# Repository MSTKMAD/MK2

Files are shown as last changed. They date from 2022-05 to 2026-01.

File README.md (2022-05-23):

# Proyecto de Contruccion del 2º modelo de la MACHETE (MK2)

Este reopsitorio es un Fork qe proviene del respositorio de bitbucket de la EDCPSU.
Las versiones HW de partida son la r15 para la tarjeta de la EDCPSU
Las versiones SW de partida son la 730 para el codigo de la DUAL y la version 731 de la EDCPSU o Main.

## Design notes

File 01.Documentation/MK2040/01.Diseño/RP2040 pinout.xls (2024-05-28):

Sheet: Pinout
 | ArduinoUNO |  |  |  |  |  |  |  |  |  | TPIC2810D MOSFET I2C Expander
 | PWM | Serial | Int | SPI | LED | I2C | Function | DIR | Description |  | Function | DIR | Description
0 |  | Rxi |  |  |  |  | RX | i | RS232 RX | D0 | LDO_S0 | o | Lower bit selection LDO voltage
1 |  | Txo |  |  |  |  | TX | o | RS232 TX | D1 | LDO_S1 | o | S11 bit selection LDO voltage
2 |  |  | INT 2 |  |  |  | PUSH | int | Pushbutton | D2 | LDO_S2 | o | S2 bit selection LDO voltage
3 | pwm |  | INT 3 |  |  |  | ROTPUSH | int | Rotary Pushbutton | D3 | LDO_S3 | o | S3 bit selection LDO voltage
4 |  |  |  |  |  |  | ROTA | i | Rotary A pin | D4 | LDO_S4 | o | S4 bit selection LDO voltage
5 | pwm |  |  |  |  |  | ROTB | i | Rotary B pin | D5 | LDO_S5 | o | S5 bit selection LDO voltage
6 | pwm |  |  |  |  |  | BUZZ | o | Buzzer | D6 | LDO_S6 | o | S6 bit selection LDO voltage
7 |  |  |  |  |  |  | /ERROR | i | Flag error (USB error detection) | D7 | LDO_S7 | o | S7 bit selection LDO voltage
8 |  |  |  |  |  |  | DSP_RST | io | Display Reset
9 | pwm |  |  |  |  |  | ONOFF | o | Output Switch (general op)
10 | pwm |  |  | SS |  |  | DISPLAY1 (SPI) | o | SS Display
11 | pwm |  |  | MOSI |  |  | DISPLAY2 (SPI) | o | MOSI Display
12 |  |  |  | MISO |  |  | DISPLAY3 (SPI) | i | MISO Display |  | TPIC2810D MOSFET I2C Expander
13 |  |  |  | SCK | led |  | DISPLAY4 (SPI) | o | SCK Display |  | Function | DIR | Description
A0 |  |  |  |  |  |  | ISEN | an | Output Current sensing | D0 | DCDC_S0 | o | Bit selection voltage DCDC
A1 |  |  |  |  |  |  | VOSEN | an | Voltage output sensing | D1 | DCDC_S1 | o | Bit selection voltage DCDC
A2 |  |  |  |  |  |  |  |  |  | D2 | DCDC_S2 | o | Bit selection voltage DCDC
A3 |  |  |  |  |  |  | /EN_VREG | o | Enables the NCP380 | D3 | LDO_YES | o | Path through LDO
A4 |  |  |  |  |  | SDA | SDA | o | I2C Bus | D4 | LDO_NOT | o | Bypass LDO
A5 |  |  |  |  |  | SCL | SCL | o | I2C Bus | D5 | 5VRAW_GO | o | Path thru 5V Raw input
A6 |  |  |  |  |  |  | VDCDCSEN | an | Voltage step-up sensing | D6 | USB_ILIM1 | o | Current Limit 1 for USB
A7 |  |  |  |  |  |  | 5VREGSEN | an | Voltage input sensing | D7 | USB_ILIM2 | o | Current Limit 2 for USB

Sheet: Pinout RP2040
 | ArduinoUNO
GPIO | PWM | Serial | Int | SPI | LED | I2C | Function | DIR | Description
0 | 0A | TxO | Int 0 |  |  |  | TX | o | RS232 TX
1 | 0B | RxI | Int 1 |  |  |  | RX | i | RS232 RX
2 | 1A |  | Int 2 |  |  |  | EN_DCDC
3 | 1B |  | Int 3 |  |  |  | PUSH_FILT
4 | 2A |  | Int 4 |  |  |  | RPUSH_FILT
5 | 2B |  | Int 5
6 | 3A |  | Int 6 |  |  | SDA | SDA | o | I2C Bus
7 | 3B |  | Int 7 |  |  | SCL | SCL | o | I2C Bus
8 | 4A |  | Int 8 |  |  |  | PEDAL_IP
9 | 4B |  | Int 9 |  |  |  | ROTB_FILT
10 | 5A |  | Int 10 |  |  |  | ROTA_FILT
11 | 5B |  | Int 11 |  |  |  | OVC_ALARM
12 | 6A |  | Int 12 |  |  |  | BUZZ
13 | 6B |  | Int 13 |  |  |  | SEL
14 | 7A |  | Int 14 |  |  |  | DSP_RESET
15 | 7B |  | Int 15 |  |  |  | SPARE2
16 | 0A |  | Int 16 | Rx |  |  | DISPLAY3 (SPI) | i | MISO Display
17 | 0B |  | Int 17 | CS |  |  | DISPLAY1 (SPI) | o | SS Display
18 | 1A |  | Int 18 | SCK |  |  | DISPLAY4 (SPI) | o | SCK Display
19 | 1B |  | Int 19 | TX |  |  | DISPLAY2 (SPI) | o | MOSI Display
20 | 2A |  | Int 20
21 | 2B |  | Int 21
22 | 3A |  | Int 22
23 | 3B |  | Int 23
24 | 4A |  | Int 24
25 | 4B |  | Int 25
26/A0 | 5A |  | Int 26 |  |  |  | ISEN | an | Output Current sensing
27/A1 | 5B |  | Int 27 |  |  |  | VOSEN | an | Voltage output sensing
28/A2 | 6A |  | Int 28 |  |  |  | VBUS_SENSE | an | Voltage step-up sensing
29/A3 | 6B |  | Int 29

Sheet: Boards Pinout
 | UF2 Bootloader | BOSSA compatible
 |  |  | Adafruit Feather RP2040 |  |  |  |  |  |  |  |  |  | SparkFun Pro Micro - RP2040
 |  |  |  |  |  |  |  | ORIGINAL | r20 | r21 | r22
 |  |  |  | Pin | Name | ADAFRUIT M0 SAMD21G18 | SPARKFUN SAMD21G18 | ARDUINO UNO EDCPSU | ARDUINO UNO EDCPSU | EDCPSU ARM Cortex | EDCPSU ARM Cortex | VOLTAGE
 |  |  |  | 3 | PA02 |  |  |  |  |  |  | 3V3
 |  |  |  | 4 | PA03
 |  |  |  | 9 | PA04
 |  |  |  | 10 | PA05
 |  |  |  | 11 | PA06
Price: | 0.36 € |  |  | 12 | PA07
DEBUG 10 pin connector (https://www.digikey.com/product-detail/en/3220-10-0100-00/1175-1627-ND/3883661) |  |  |  | 13 | PA08
 |  |  |  | 14 | PA09
 |  |  |  | 15 | PA10
 |  |  |  | 16 | PA11
 |  |  |  |  | PA12
 |  |  |  |  | PA13
 |  |  |  |  | PA14
 |  |  |  |  | PA15
 | 5 mm |  |  |  | PA16
12,65 mm |  |  |  |  | PA17
 |  |  |  |  | PA18
 |  |  |  |  | PA19
 |  |  |  |  | PA20
 |  |  |  |  | PA21
 |  |  |  |  | PA22
 |  |  |  |  | PA23
 |  |  |  |  | PA24
 |  |  |  |  | PA25
 |  |  |  |  | PA27
 |  |  |  |  | PA28
 |  |  |  |  | PA30
 |  |  |  |  | PA31
 |  |  |  | 47 | PB02
 |  |  |  | 48 | PB03
 |  |  |  | 7 | PB08
 |  |  |  | 8 | PB09
 |  |  |  |  | PB10
 |  |  |  |  | PB11
 |  |  |  |  | PB22
 |  |  |  |  | PB23

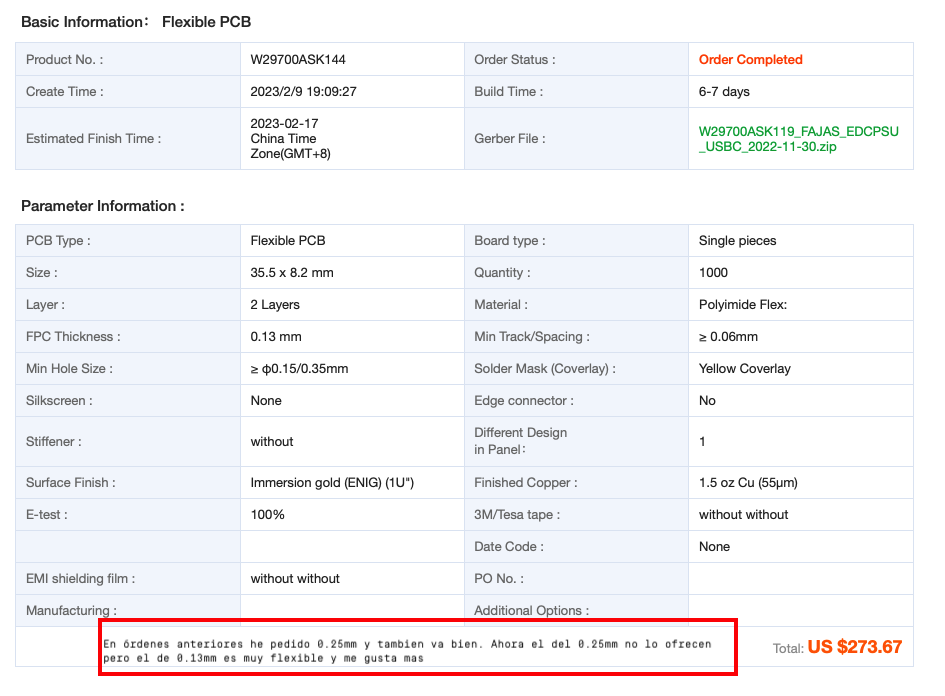
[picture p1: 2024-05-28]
02.Hardware/MK2 PCBs/05.FAJA USBC SINGLE/GERBER/Como pedir faja PCBWAY - 0.13mm.png

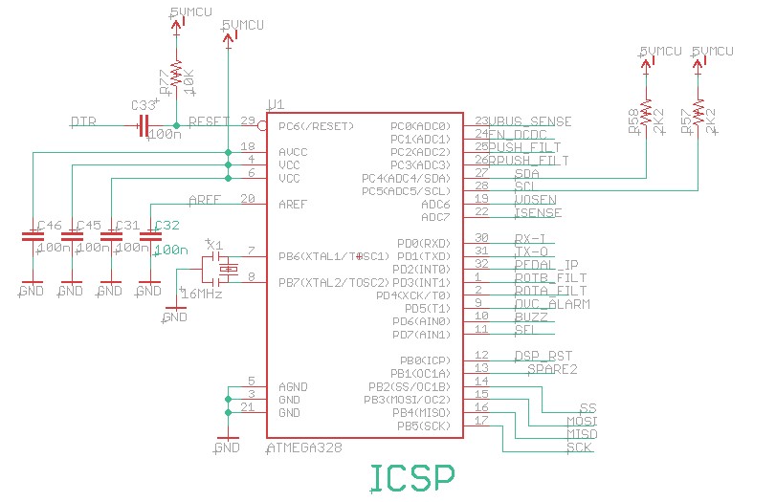
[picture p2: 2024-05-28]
01.Documentation/MK2040/01.Diseño/Atemega328P.jpg

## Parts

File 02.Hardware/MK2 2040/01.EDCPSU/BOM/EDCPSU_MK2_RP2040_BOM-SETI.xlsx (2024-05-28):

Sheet: EDCPSUMK2
 |  |  |  | BOM VERSION v | 5
 |  |  |  | Fecha | 2023-06-05
 |  |  |  | MK2-RP2040
Assembly? | Cambios | Pos | Qty | Parts | Value | Device | Package | Description | Details | COST (500pcs) | COST per Board (500 pcs) | DIGIKEY
P | NO | 2 | 1 | BZ1 | PKMCS0909E4000-R1 | PKMCS0909E4000-R1 | PKMCS0909 | PKMCS0909E4000-R1 |  | 0.48 € | 0.48 € | https://www.digikey.es/es/products/detail/murata-electronics/PKMCS0909E4000-R1/4878400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
P | NO | 3 | 3 | C17, C18, C21 | 4.7uF 50V X7R | CAP1210 | SMD1210 | Capacitor |  | 0.11 € | 0.32 € | https://www.digikey.es/en/products/detail/samsung-electro-mechanics/CL32B475KBUYNNE/3886950
NO | NO | 4 | 0 | C19, C65 | N.C. | CAP0805 | SMD0805 | Capacitor |  |  | 0.00 €
P | NO | 5 | 34 | C2, C4, C5, C6, C7, C8, C10, C12, C14, C16, C20, C22, C23, C24, C25, C27, C28, C29, C31, C32, C33, C34, C36, C44, C47, C48, C49, C50, C53, C55, C57, C58, C60, C66 | 100n 50v X7R/X5R | CAP0805 | SMD0805 | Capacitor |  |  | 0.00 €
P | NO | 6 | 4 | C26, C35, C43, C51 | 10uF 50V X5R/X7R | CAP1206 | SMD1206 | Capacitor |  | 0.07 € | 0.28 € | https://www.digikey.es/en/products/detail/samsung-electro-mechanics/CL31A106MBHNNNE/5961220
P | NO | 7 | 2 | C3, C62 | 22uF 10V X5R | CAP0805 | SMD0805 | Capacitor |  | 0.06 € | 0.11 € | https://www.digikey.es/en/products/detail/murata-electronics/GRM21BR61A226ME51L/5027595
P | NO | 8 | 1 | C30 | 33n | CAP0805 | SMD0805 | Capacitor |  |  | 0.00 €
P | NO | 9 | 1 | C37 | 10nF | CAP0805 | SMD0805 | Capacitor |  |  | 0.00 €
P | NO | 10 | 1 | C38 | 16pF | CAP0805 | SMD0805 | Capacitor |  |  | 0.00 €
P | NO | 11 | 4 | C39, C40, C41, C42 | 22uF 25V X5R | CAP1210 | SMD1210 | Capacitor |  | 0.12 € | 0.49 € | https://www.digikey.es/en/products/detail/samsung-electro-mechanics/CL32A226KPJNNNE/3889030
NO | NO | 12 | 0 | C52 | N.C | CAP0805 | SMD0805 | Capacitor |  |  | 0.00 €
P | NO | 13 | 2 | C59, C61 | 27p | CAP0805 | SMD0805 | Capacitor |  |  | 0.00 €
P | NO | 14 | 2 | C63, C64 | 4.7uF 50V X5R | CAP0805 | SMD0805 | Capacitor |  | 0.04 € | 0.09 € | https://www.digikey.es/en/products/detail/murata-electronics/GRT21BR61H475ME13L/5416817
P | NO | 15 | 8 | C9, C11, C13, C15, C45, C46, C54, C56 | 1uF 50V X7R | CAP0805 | SMD0805 | Capacitor |  |  | 0.00 €
P | valor | 16 | 1 | D1 | SMAJ24A | SMAJ24A | SMA-DO214 | ESD Suppressors / TVS Diodes 24volts 5uA 10.3 Amps UNI-Dir |  | 0.11 € | 0.11 € | https://www.digikey.es/en/products/detail/littelfuse-inc/SMAJ24A/762288
P | NO | 17 | 2 | D2, D7 | BAV199 | BAV199 | SOT23 | DIODE |  | 0.11 € | 0.23 € | https://www.digikey.es/es/products/detail/infineon-technologies/BAV199E6327HTSA1/506263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
P | NO | 18 | 1 | D4 | PESD5V0U2BT,215 | PESD5V0U2BT,215 | SOT23 | PESD5V0U2BT - Ultra low capacitance bidirectional double ESD protection diode |  | 0.18 € | 0.18 € | https://www.digikey.es/es/products/detail/nexperia-usa-inc/PESD5V0U2BT-215/1766938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
P | NO | 19 | 1 | D5 | 3SMAJ5923B-TP | 3SMAJ5923B-TP | SMA-DO214 | Zener Diodes 3W 8.2V |  | 0.12 € | 0.12 € | https://www.digikey.es/es/products/detail/micro-commercial-co/3SMAJ5923B-TP/1793169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
NO | NO | 20 | 0 | D6 | N.C | DSMC | DO-214AB |  |  |  | 0.00 €
P | Valor | 21 | 1 | D8 | SMAJ18A | SMAJ18A | SMA-DO214 | TVS 18V 400W Unidirectional |  | 0.13 € | 0.13 € | https://www.digikey.es/en/products/detail/littelfuse-inc/SMAJ18A/762282
P | NO | 22 | 1 | DZ1 | MMSZ5228B | MMSZ5228B | SOD123F | Diode Zener 3.9 5% 500mW 2Pin SOD123 Diodes Inc MMSZ5227B-7-F Zener Diode, 3.9V 5% 500 mW SMT 2-Pin SOD-123 |  | 0.09 € | 0.09 € | https://eu.mouser.com/ProductDetail/Diotec-Semiconductor/MMSZ5228B?qs=OlC7AqGiEDkIT4mCF6hrjg%3D%3D
P | NO | 25 | 1 | J1 | DX07S016JA1R1500 | DX07S016JA1R1500 | JAE_DX07S016JA1R1500 | USB-C (USB TYPE-C) USB 2.0 Receptacle Connector 24 (16+8 Dummy) Position Surface Mount, Right Angle; Through Hole |  | 1.08 € | 1.08 € | https://www.digikey.es/es/products/detail/jae-electronics/DX07S016JA1R1500/11585731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
P | NO | 26 | 1 | J6 | Display | OLED_LCD | OLED_LCD |  |  |  | 0.00 €
P | NO | 27 | 1 | JP1 | 20021521-00010T1LF | 20021521-00010T1LF | 20021521-00010T1LF | MINITEK 127 SHROUDED HDR |  | 0.64 € | 0.64 € | https://www.digikey.es/en/products/detail/amphenol-cs-fci/20021521-00010T1LF/2414951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
P | NO | 29 | 1 | L1 | NRS4018T4R7MDGJ | NRS4018T4R7MDGJ | NRS4018T100MDGJ | Inductor SMD wirewound 4.7uH |  | 0.12 € | 0.12 € | https://www.digikey.es/en/products/detail/taiyo-yuden/NRS4018T100MDGJ/2648964
P | NO | 30 | 1 | L2 | 4.7uH | L74437368047 | WE-LHMI |  |  | 0.72 € | 0.72 € | https://www.digikey.es/en/products/detail/pulse-electronics/PA4342-472NLT/5436333
P | NO | 31 | 5 | L3, L4, L5, L6, L7 | MMZ2012Y202BT000 | SMD0805 | SMD0805 | Ferrite bead |  | 0.02 € | 0.11 € | https://www.digikey.es/en/products/detail/tdk-corporation/MMZ2012Y202BT000/571868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
P | Valor | 32 | 1 | LED1 | LTL1NHSH6D | LTL1NHSH6D | LTL1NHSH6D | LED 3MM LITEON YELLOW 65mcd 60º |  | 0.03 € | 0.03 € | https://www.tme.eu/es/en/details/ltl1nhsh6d/tht-leds-round/liteon/
NO | sin montar | 33 | 0 | LS1 | SMT-0540-S-R | SMT-0540-S-R | SMT0540SR | Speakers & Transducers SMD TRANSDUCER 3VP-P 100MA |  |  | 0.00 €
P | NO | 34 | 1 | OP1 | LTV816S | LTV816S | SMD4 | OPTO COUPLER |  | 0.13 € | 0.13 € | https://www.digikey.es/es/products/detail/liteon/LTV-816S/385831?s=N4IgTCBcDaIIwDYAMBaOBmBcUFYUDkAREAXQF8g
P | NO | 35 | 1 | PTC1 | 2A NOM / 3.5A LIM | 0ZCC0150BF2C | SMD1812 | PTC RESTTBLE 1.50A 24V CHIP 1812 |  | 0.13 € | 0.13 € | https://www.digikey.es/es/products/detail/bel-fuse-inc/0ZCC0150BF2C/2165288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
P | NO | 36 | 4 | Q2, Q4, Q5, Q9 | 2N7002PW | MOSFET-NCHANNEL2N7002PW | SOT323 | N-MOSFET VGS=2.4V 500mA, VDS=60V |  | 0.09 € | 0.35 € | https://www.digikey.es/es/products/detail/nexperia-usa-inc/2N7002PW-115/2296328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
P | NO | 37 | 8 | R1,R32, R39, R40, R42, R49, R66 | 10K | RESISTOR0805 | SMD0805 | Generic Resistor Package |  |  | 0.00 €
P | NO | 38 | 1 | R10 | 22K | RESISTOR0805 | SMD0805 | Generic Resistor Package |  |  | 0.00 €
P | Valor | 39 | 1 | R12 | 0.025R / 1W | RR2512 | SMD2512 | 25mR Sensing resistor |  | 0.19 € | 0.19 € | https://www.digikey.es/en/products/detail/yageo/RL2512FK-070R025L/3885847
P | NO | 40 | 5 | R13, R23, R52, R53, R54 | 2K2 | RESISTOR0805 | SMD0805 | Generic Resistor Package |  |  | 0.00 €
P | NO | 41 | 7 | R14, R17, R21, R24, R28, R29, R65 | 33R | RESISTOR0805 | SMD0805 | Generic Resistor Package |  |  | 0.00 €
NO | NO | 42 | 7 | R16, R18, R30, R34, R45, R58, R60 | N.C | RESISTOR0805 | SMD0805 | Generic Resistor Package |  |  | 0.00 €
P | Cantidad | 43 | 7 | R2, R19, R20, R25, R27, R46, R59 | 1K | RESISTOR0805 | SMD0805 | Generic Resistor Package |  |  | 0.00 €
P | Cantidad | 44 | 7 | R22, R26, R31, R33, R61, R99, R57 | 330R | RESISTOR0805 | SMD0805 | Generic Resistor Package |  |  | 0.00 €
P | Cantidad | 45 | 2 | R3, R43 | 11K | RESISTOR0805 | SMD0805 | Generic Resistor Package |  |  | 0.00 €
P | Cantidad | 46 | 2 | R37, R41 | 150K | RESISTOR0805 | SMD0805 | Generic Resistor Package |  |  | 0.00 €
P | NO | 47 | 2 | R38, R63 | 27R | RESISTOR0805 | SMD0805 | Generic Resistor Package |  |  | 0.00 €
P | NO | 48 | 1 | R4 | 5K6 | RESISTOR0805 | SMD0805 | Generic Resistor Package |  |  | 0.00 €
NO | Eliminada | 49 | 0 | - | - | - | - | - |  |  | 0.00 €
P | NO | 50 | 1 | R36 | 27K | RESISTOR0805 | SMD0805 | Generic Resistor Package |  |  | 0.00 €
P | NO | 51 | 1 | R44 | 25K | RESISTOR0805 | SMD0805 | Generic Resistor Package |  |  | 0.00 €
P | NO | 52 | 2 | R47, R48 | 100R | RESISTOR0805 | SMD0805 | Generic Resistor Package |  |  | 0.00 €
P | NO | 53 | 1 | R5 | 2K8 | RESISTOR0805 | SMD0805 | Generic Resistor Package |  |  | 0.00 €
P | NO | 54 | 1 | R50 | 56K | RESISTOR0805 | SMD0805 | Generic Resistor Package |  |  | 0.00 €
P | NO | 55 | 1 | R51 | 390K | RESISTOR0805 | SMD0805 | Generic Resistor Package |  |  | 0.00 €
P | NO | 56 | 2 | R55, R56 | 5K1 | RESISTOR0805 | SMD0805 | Generic Resistor Package |  |  | 0.00 €
NO | Eliminada | 57 | 0 | - | - | - | - | - |  |  | 0.00 €
P | NO | 58 | 1 | R6 | 1K4 | RESISTOR0805 | SMD0805 | Generic Resistor Package |  |  | 0.00 €
P | NO | 59 | 1 | R62 | 100K | RESISTOR0805 | SMD0805 | Generic Resistor Package |  |  | 0.00 €
P | NO | 60 | 1 | R7 | 180K | RESISTOR0805 | SMD0805 | Generic Resistor Package |  |  | 0.00 €
P | NO | 61 | 1 | R8 | 91K | RESISTOR0805 | SMD0805 | Generic Resistor Package |  |  | 0.00 €
P | NO | 62 | 1 | R9 | 43K | RESISTOR0805 | SMD0805 | Generic Resistor Package |  |  | 0.00 €
P | NO | 63 | 1 | R35 | 130R | RESISTOR0805 | SMD0805 | Generic Resistor Package |  |  | 0.00 €
P | NO | 64 | 1 | RSENSE | 100mR | RESISTOR1206 | SMD1206 | Generic Resistor Package |  | 0.06 € | 0.06 € | https://www.digikey.es/en/products/detail/bourns-inc/CRL1206-FW-R100ELF/3593165
P | correccion | 65 | 1 | S1 | PEC12R-3220F-S0024 | ROTARTY_ENCODER | PEC12R-3220F-S0024 | ROTARY ENCODER MECHANICAL 24PPR |  | 0.91 € | 0.91 € | https://www.digikey.es/en/products/detail/bourns-inc/PEC12R-3220F-S0024/4699265
P | correccion | 66 | 1 | S2 | KSC931G LFS | KSC931G LFS | KSC931G LFS | Momentary switch |  | 0.54 € | 0.54 € | https://www.digikey.es/en/products/detail/c-k/KSC931G-LFS/3533878
P | NO | 67 | 1 | U1 | RP2040TR7 | RP2040TR7 | 56-QFN (7x7) | ARM MCU, RP2040 Series Microcontrollers, ARM Cortex-M0+, 32 bit, 133 MHz, 16 MB, 56 Pins |  | 0.65 € | 0.65 € | https://www.digikey.es/es/products/detail/raspberry-pi/SC0914-13/14306010?s=N4IgTCBcDaIE4AcwAYAsyQF0C%2BQ
P | NO | 68 | 1 | U10 | IP2721 | IP2721 | TSSOP16 | TYPEC/PD2.0/PD3.0 Physical Layer IC for USB TYPEC input Interfaces Working voltage: 3V~25V Package: TSSOP16 |  |  | 0.00 €
P | correccion | 69 | 1 | U11 | AP63203 | AP63203WU-7 | SOT23-6 | Switching Voltage Regulators DCDC Conv HV Buck TSOT26 T&R 3K |  | 0.43 € | 0.43 € | https://www.digikey.es/es/products/detail/diodes-incorporated/AP63203WU-7/9858426
P | NO | 70 | 1 | U12 | AP64501SP-13 | AP64501SP-13 | SOIC8 | Conv DC-DC 3.8V to 40V Synchronous Step Down Single-Out 0.8V to 39V 5A 8-Pin SO EP T/R |  | 1.25 € | 1.25 € | https://www.digikey.es/es/products/detail/diodes-incorporated/AP64501SP-13/10419715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
NO | sin montar | 71 | 0 | U2 | MCP4725A1T-E/CH | MCP4725A1T-E/CH | SOT23-6 | MCP4725 DAC |  |  | 0.00 € | https://www.digikey.es/es/products/detail/microchip-technology/MCP4725A1T-E-CH/1827895
P | NO | 72 | 2 | U3, U6 | SN74AC14PWR | 7414 | TSSOP14 | Hex schmitt trigger INVERTER |  | 0.27 € | 0.54 € | https://www.digikey.es/es/products/detail/texas-instruments/SN74AC14PWR/376031
P | Valor | 73 | 1 | U4 | MAX9938TEUK+TCT-ND | integrated Circuit | SOT23-5 | Current sense amplifier. GAIN=25 |  | 1.08 € | 1.08 € | https://www.digikey.es/es/products/detail/analog-devices-inc-maxim-integrated/MAX9938TEUK-T/1937784
P | NO | 74 | 1 | U5 | W25Q64JVSSIQ | W25Q64JVSSIQ | SOIC8-WIDE | 64M-bit Serial Flash Memory with uniform 4KB sectors and Dual/Quad SPI |  | 0.76 € | 0.76 € | https://www.digikey.es/es/products/detail/winbond-electronics/W25Q64JVSSIQ/5803992
P | NO | 75 | 1 | U7 | TPIC2810D | TPIC2810D | SOIC16 |  |  | 1.03 € | 1.03 € | https://www.digikey.es/es/products/detail/texas-instruments/TPIC2810D/509926
P | Valor | 76 | 1 | U8 | LM4040C30FTA | LM4040C30FTA | SOT23 | Diodes Inc LM4040C30FTA, Shunt Precision Voltage Reference 3V, 0.5%, 3-Pin SOT-23 |  | 0.28 € | 0.28 € | https://www.digikey.es/es/products/detail/diodes-incorporated/LM4040C30FTA/4249970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
P | NO | 77 | 1 | U9 | MAX9064EUK+T | MAX9064EUK+T | SOT23-6 |  |  | 0.86 € | 0.86 € | https://www.digikey.es/es/products/detail/analog-devices-inc-maxim-integrated/MAX9064EUK-T/1937852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
P | correccion | 78 | 1 | X1 | ABM3C-12.000MHZ-D4Y-T | ABM3C-12.000MHZ-D4Y-T | ABM3C-12.000MHZ-D4Y-T | Abracon 12MHz Crystal +/-30ppm 4-SMD, No Lead 5 x 3 x 1.3mm |  | 0.57 € | 0.57 € | https://www.digikey.es/es/products/detail/abracon-llc/ABM3C-12-000MHZ-D4Y-T/2639882
P | Nueva | 79 | 1 | R15 | 0R | RESISTOR0805 | SMD0805 | Generic Resistor Package |  |  | 0.00 €
NO | sin montar | 80 | 0 | D3 | N.C | BAV199 | SOT23 | DIODE |  |  | 0.00 €
P | Nueva | 81 | 1 | R11 | 15K | RESISTOR0805 | SMD0805 | Generic Resistor Package |  |  | 0.00 €
 |  |  |  |  |  |  |  |  |  | 13.47 € | 15.10 €

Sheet: Historico
HISTÓRICO
VERSIÓN | FECHA | AUTOR | CAMBIO
1 | 2023-04-04 | JRC | Creacion
2 | 2023-05-30 | JRC | Se añade el pos 79 con el part R15 Se añade la pos 80 con el part D3 con el valor N.C Se añade a la pos 44 el part 57 aumentando su Qty. Se cambia el value de la pos 76 a LM4040C30FTA Se cambia el valor de la pos 39 part R12 a 0,025mOhm Se aumenta la pos 46 con el part R41 Se aumenta la pos 45 con el part R43 Se añade la pos 81 cambia el valor de R11 a 15K
3 | 2023-05-31 | JRC | Se añade la columna de Cambios
4 | 2023-06-01 | DGB | Varios cambios y correcciones. Se añaden links de digikey, se corrigen denominaciones y se estandariza nombre de encapsulados
5 | 2023-06-05 | JRC | Se añaden la columna de precios por unidad en compras de 500 y el coste de la placa, multiplicando por el numero de unidades en la placa

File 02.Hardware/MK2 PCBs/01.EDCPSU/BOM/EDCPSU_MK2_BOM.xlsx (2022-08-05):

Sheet: EDCPSUMK2
 |  |  |  |  |  |  | BOM VERSION v1
 |  |  |  |  |  |  | 2022-05-23
 |  |  |  |  |  |  | EDCPSUMK2r1
Assembly? | Compra Seti | Pos | Qty | Parts | Value | Device | Package | Description | Details | DIGIKEY | COST (25pcs) | COST (100pcs) | COST per Board (25pcs)
P | P | 1 | 1 | R12 | 0.05R / 1W | Resistor | 2512 | Current sense resistor | 1W, 1%, 75ppm | 985-1555-1-ND | 0.27 | 0.18 | 0.27
P | P | 2 | 7 | R1, R32, R39, R49, R42, R66, R77 | 10K | Resistor | 805 | Resistor | 5% |  |  |  | 0
P | P | 3 | 1 | R11 | 15K | Resistor | 805 | Resistor | 5%
P | P | 4 | 1 | R3 | 11K | Resistor | 805 | Resistor | 5% |  |  |  | 0
P | P | 5 | 1 | R7 | 180K | Resistor | 805 | Resistor | 5% |  |  |  | 0
P | P | 6 | 6 | R2, R19, R20, R25,R27,R59 | 1K | Resistor | 805 | Resistor | 5% |  |  |  | 0
P | P | 7 | 1 | R6 | 1K4 | Resistor | 805 | Resistor | 5% |  |  |  | 0
P | P | 8 | 1 | R16 | 12K | Resistor | 805 | Resistor | 5% |  |  |  | 0
P | P | 9 | 2 | R37,R51 | 220K | Resistor | 805 | Resistor | 5% |  |  |  | 0
P | P | 10 | 1 | R10 | 22K | Resistor | 805 | Resistor | 5% |  |  |  | 0
P | P | 11 | 7 | R13, R23, R52, R53, R54, R57, R58 | 2K2 | Resistor | 805 | Resistor | 5% |  |  |  | 0
P | P | 12 | 1 | R5 | 2K8 | Resistor | 805 | Resistor | 5% |  |  |  | 0
P | P | 13 | 10 | R14, R17, R21, R24, R28, R29, R31, R65, R99, R45 | 33 | Resistor | 805 | Resistor | 5% |  |  |  | 0
P | P | 14 | 4 | R30,R33, R35, R61 | 330 | Resistor | 805 | Resistor | 5% |  |  |  | 0
P | P | 15 | 2 | R22, R26 | 330 | Resistor | 1206 | Resistor | 5% |  |  |  | 0
P | P | 16 | 1 | R44 | 33K | Resistor | 805 | Resistor | 5% |  |  |  | 0
P | P | 17 | 1 | R9 | 43K | Resistor | 805 | Resistor | 5% |  |  |  | 0
P | P | 18 | 1 | R4 | 5K6 | Resistor | 805 | Resistor | 5% |  |  |  | 0
P | P | 19 | 1 | R15 | 68K | Resistor | 805 | Resistor | 5% |  |  |  | 0
P | P | 20 | 1 | R36 | 75K | Resistor | 805 | Resistor | 5% |  |  |  | 0
P | P | 21 | 1 | R8 | 91K | Resistor | 805 | Resistor | 5% |  |  |  | 0
P | P | 22 | 29 | C1, C2, C7, C8, C10, C12, C14, C15, C20, C22, C23, C24, C25, C27, C28, C29, C31, C32, C33, C34, C36, C44, C45, C46, C47, C48, C49, C50, C53,C55,C57,C58 | 100n | Capacitor | 805 | Capacitor | 25V-50V, X7R or XR5 |  |  |  | 0
P | P | 23 | 5 | C4, C6, C26, C35, C43 | 10uF | Capacitor | 1206 | Capacitor | 25V-50V, X7R or XR5 |  |  |  | 0
P | P | 24 | 2 | C3, C30 | 15n | Capacitor | 805 | Capacitor | 25V-50V, X7R or XR5 |  |  |  | 0
P | P | 25 | 1 | C38 | 15p | Capacitor | 805 | Capacitor | 25V-50V, X7R or XR5 |  |  |  | 0
P | P | 26 | 4 | C11, C13, C16, C54 | 1uF | Capacitor | 805 | Capacitor | 25V-50V, X7R or XR5 |  |  |  | 0
P | P | 27 | 2 | C9,C56 | 1uF | Capacitor | 1206 | Capacitor | 25V-50V, X7R or XR5 |  |  |  | 0
P | P | 28 | 1 | C37 | 2.2n | Capacitor | 805 | Capacitor | 25V-50V, X7R or XR5 |  |  |  | 0
P | P | 29 | 4 | C39, C40, C41, C42 | 22uF | Capacitor | 1210 | Capacitor | 25V, X5R | 490-6540-1-ND | 0.31 |  | 1.24
P | P | 30 | 3 | C17, C18, C21 | 4.7uF | Capacitor | 1206 | Capacitor | 50V, 10% X7R | 1276-2789-1-ND | 0.18 | 0.14 | 0.54
P | P | 31 | 1 | L2 | 4.7uH | inductor | WE-LHMI |  | 4.7uH, 7A 0.0155 OHM | 732-3389-1-ND | 2.96 | 2.5 | 2.96
P | P | 32 | 1 | L1 | 6.8uH | Inductor | NR4018T100M | Inductor | 6.8uH, 1A, 0.132R | 587-2657-1-ND | 0.25 | 0.2 | 0.25
P | P | 33 | 5 | L3, L4, L5, L6, L7 | MMZ2012Y202BT000 | Inductor | 805 | Inductor | FERRITE CHIP 2000 OHM 400MA | 445-1561-1-ND | 0.08 | 0.045 | 0.4
P | P | 34 | 2 | U3, U6 | SN74AC14DBR | integrated Circuit | SSOP14 | Hex schmitt trigger INVERTER |  | 296-4299-1-ND | 0.38 | 0.28 | 0.76
P | P | 35 | 1 | U1 | ATMEGA328P-AU | integrated Circuit | 32-TQFP | MCU 8BIT 32KB FLASH 32TQFP |  | ATMEGA328P-AU-ND (http://www.digikey.es/product-detail/en/ATMEGA328P-AU/ATMEGA328P-AU-ND/1832260) | 2.8 (http://www.digikey.es/product-detail/en/ATMEGA328P-AU/ATMEGA328P-AU-ND/1832260) | 2.56 | 2.8
P | P | 36 | 1 | U5 | LM3480IM3X-12 | integrated Circuit | SOT23-3 | Small package linear regulator |  | LM3480IM3X-12/NOPBCT-ND | 0.76 | 0.66 | 0.76
P | P | 37 | 1 | U4 | MAX9938TEUK+TCT-ND | integrated Circuit | SOT23-5 | Current sense amplifier | X25 GAIN | MAX9938TEUK+TCT-ND | 1 | 0.93 | 1
P | P | 38 | 1 | U2 | BD9G101G | integrated Circuit | SSOP6 | BD9G101G - Simple Step-down |  | BD9G101G-CT-ND | 1.26 | 1.11 | 1.26
P | P | 39 | 1 | U7 | TPIC2810D | integrated Circuit | SO16 | I2C Led driver |  | 296-21426-5-ND | 1.4 | 1.13 | 1.4
P | P | 40 | 1 | U8 | TPS54531DDAR | Integrated Circuit | SOIC8 | BUCK converter |  | 296-40801-1-ND | 2.2 | 1.45 | 2.2
P | P | 41 | 1 | X1 | 16MHz | RESONATORSMD | 3-SMD, Non-Standard | CER RESONATOR 16.00MHZ SMD | 16MHz | 490-1198-1-ND | 0.39 | 0.31 | 0.39
P | P | 42 | 1 | S2 | TAC_SWITCH_KSC931G-SMD | pushbutton | TAC_SW_SMD_KSC931G | Momentary Switch |  | CKN10432CT-ND | 0.73 | 0.61 | 0.73
P | P | 43 | 1 | PTC1 | 1,5A HOLD / 3A LIM | PTC | 1812 | PTC RESTTBLE 1.50A 24V CHIP 1812 | 1,5A | 507-1505-1-ND | 0.24 | 0.22 | 0.24
P | P | 44 | 5 | Q2, Q3, Q4,Q5, Q9 | 2N7002PW | transistor | SOT323 | MOSFET N-CH 60V 0.31A, 1.6 Ohm. 2.4 VGS |  | 568-5987-1-ND | 0.24 | 0.18 | 1.2
P | P | 45 | 2 | D2,D7 | BAV199 | diode | SOT23 | DIODE |  | BAV199INCT-ND | 0.18 | 0.08 | 0.36
P | P | 46 | 1 | D6 | Diode | diode | DO-214AB | SCHOTTKY 40V 5A DO214AB |  | SK54L-TPMSCT-ND | 0.35 | 0.3 | 0.35
P | P | 47 | 1 | D1 | RB060M-60TR | diode | PMDU | DIODE SCHOTTKY 60V 2A PMDU |  | RB060M-60CT-ND | 0.3 | 0.19 | 0.3
P | P | 48 | 1 | D8 | B220A-13-F | diode | DO-214AC | DIODE SCHOTTKY 20V 2A SMA |  | B220A-FDICT-ND | 0.31 | 0.19 | 0.31
P | P | 49 | 1 | OP1 | LTV816S | Integrated Circuit | SMD4 Gullwing | OPTO COUPLER | CTRmin=50% @ 5mA, 5KViso | 160-1361-5-ND | 0.28 | 0.18 | 0.28
P | P | 50 | 1 | BZ1 | PKMCS0909E4000-R1 | speaker | SMD | Buzzer 12V |  | 490-9647-1-ND (https://www.digikey.es/product-detail/en/murata-electronics-north-america/PKMCS0909E4000-R1/490-9647-1-ND/4878401) | 1.08 | 0.968 | 1.08
P | NO | 52 | 1 | S1 | ROTARTY_ENCODER | ROTARTY_ENCODER | ROTARY_ENC_PLAIN | Simple no LED rotary encoder | Cambiado modelo con rosca | 652-PEC12R3220FS0024 (http://www.mouser.com/ProductDetail/bourns/pec12r-3220f-s0024/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) |  | 0.62
P | NO | 53 | 1 | LED1 | LED thru hole | LED3MM | LED3MM | LED Yellow
- | - | 54 |  | DELETED
- | - | 55 |  | DELETED
NO | NO | 56 | 2 | C5, C19 | N.C. | CAP0805 | 805 | Capacitor
NO | NO | 57 | 1 | R18 | N.C. | RESISTOR0805-RES | 805 | Resistor
- | - | 58 |  | DELETED
- | - | 59 |  | DELETED
- | - | 60 |  | DELETED
- | - | 61 |  | DELETED
P | NO | 62 | 1 | J6 | Display | OLED_LCD | OLED_LCD
- | - | 63 |  | DELETED
- | - | 64 |  | DELETED
- | - | 65 |  | DELETED
P | P | 66 | 1 | R41 | 330k | RESISTOR0805-RES | SMD0805 | Resistor | 5%
P | P | 67 | 1 | R43 | 27k | RESISTOR0805-RES | SMD0805 | Resistor | 5%
P | P | 68 | 1 | D4 | BZT52-B5V6J | DIODE | SOD-123 | Zener diode 5V6 590mW 2% 40ohm | 2% | Mouser (https://www.mouser.es/ProductDetail/Nexperia/BZT52-B5V6J) |  | 0.054
NO | NO | 69 | 0 | R46,R34 | N.C. | RESISTOR0805-RES | SMD0805 | Resistor | 5%
P | P | 70 | 2 | R47,R48 | 100R | RESISTOR0805-RES | SMD0805 | Resistor | 5%
P | P | 71 | 1 | R50 | 56K | RESISTOR0805-RES | SMD0805 | Resistor | 5%
P | P | 72 | 2 | R55,R56 | 5K1 | RESISTOR0805-RES | SMD0805 | Resistor | 5%
P | P | 73 | 1 | R62 | 100K | RESISTOR0805-RES | SMD0805 | Resistor | 5%
P | P | 74 | 1 | Rsense | 100mR | RESISTOR1206-RES | SMD1206 | Resistor | 1% | 273-KDV12DR100ETCT-ND (https://www.digikey.es/es/products/detail/ohmite/KDV12DR100ET/10476622)
P | P | 75 | 1 | J1 | DX07S016JA1R1500 | DX07S016JA1R1500 | JAE_DX07S016JA1R1500 | USB-C Connector |  | 670-DX07S016JA1R1500TR-ND (https://www.digikey.es/es/products/detail/jae-electronics/DX07S016JA1R1500/11585731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)
P | P | 76 | 1 | U9 | MAX9064EUK+T | 21-0057F_MXM | SOT23-5 | Comparator 0,2v |  | MAX9064EUK+TCT-ND (https://www.digikey.es/es/products/detail/analog-devices-inc-maxim-integrated/MAX9064EUK-T/1937852)
P | NO | 77 | 1 | U10 | IP2721 | SOP65P640X120-16N | TSSOP16

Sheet: Historico
HISTÓRICO
VERSIÓN | FECHA | AUTOR | CAMBIO
0 | 2016-10-17 | D. Garrido | Creación
1 | 2016-10-27 | D. Garrido | Se añade columna de Posicion. Pos30, se corrige encapsulado de condensadores de SMD1210 a 1206 Pos40 , se corrige denominacion de integrado (antes:74HC14). Pos42 , se corrige denominación de integrado (antes: LM3480IM4) Se añade Pos64,65 (sin completar aún)
2 | 2020-09-06 | D. Garrido | Se añade posiciones 66, 67 y 68. Se añade Q4 en pos44 and R45 in pos13
3 | 2020-10-09 | D. Garrido | Pos 52. Nuevo rotary con rosca. Referencia de Mouser
Cambio de Modelo a MK2 |  |  | Esta BOM se crea a partir de la original EDCPSU v3
1 | 2022-05-22 | J.Rodriguez | Se cambia el valor de R30 de 33 a 330 se elimina de la Pos13 y se añade a la Pos14. Se cambia el valor de R27 de 330 a 1k, se elimina de la Pos14 y se añade a la Pos6 Se añade R49 en Pos2. Se añade R51 a Pos 9. Se añade R59 a Pos 6. Se añade R34 a Pos 69. Se elimina C51 de Pos22. Se elimina C52 de Pos23. Se añade Q5 a la Pos44 Se elimina D3 de Pos45. Se elimina D5 de Pos46. Se añade C55 , C57 y C58 a Pos 22. Se añade C56 a Pos 27. Se añade D7 a Pos 45. Se añade Pos70, Pos71, Pos72, Pos73, Pos74, Pos75, Pos76 y Pos77. Se elimina Pos 54,55,58,59,61,63,64,65 (No se montaban)

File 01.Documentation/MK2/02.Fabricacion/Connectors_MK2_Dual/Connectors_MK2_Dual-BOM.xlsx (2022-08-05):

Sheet: BOM
 |  |  |  |  |  |  | BOM VERSION v1
 |  |  |  |  |  |  | 2022-05-27
 |  |  |  |  |  |  | CONNECTORS_MK2_DUAL_v1
Assembly? | Compra Seti | Pos | Qty | Parts | Value/Reference | Device | Package | Description | Details | DIGIKEY | COST (1000pcs) | Substitute
P | P | 1 | 1 | R3 | 10k | Resistor | SMD0603 | Resistor | 5%
P | P | 2 | 2 | R8, R9 | 220R | Resistor | SMD0603 | Resistor | 5%
P | P | 3 | 1 | R4 | 330R | Resistor | SMD0604 | Resistor | 5%
P | P | 4 | 1 | R7 | 3k3 | Resistor | SMD0605 | Resistor | 5%
P | P | 5 | 2 | R5, R6 | 47k | Resistor | SMD0606 | Resistor | 5%
P | P | 6 | 5 | Q1, Q2, Q3, Q4, Q5 | 2N7002PW | transistor | SOT323 | N-channel MOSFETs |  | 2N7002W-FDICT-ND (https://www.digikey.es/es/products/detail/diodes-incorporated/2N7002W-7-F/814962)
P | P | 7 | 2 | Q6, Q7 | SI4425DY | transistor | SOIC8 | Trans MOSFET P-CH 30V 29A 8-Pin SOIC N T/R |  | 2156-SI4425DY-ND (https://www.digikey.es/es/products/detail/rochester-electronics-llc/SI4425DY/12129450) |  | SI4459ADY-T1-GE3 AOSP21313C
P | P | 8 | 3 | MACHINE1, MACHINE2, PEDAL | ACJS-MHOM | Connector | CONN_MHDR_AMP | Audio connector 6.35mm stereo |  | 889-1817-ND (https://www.digikey.es/es/products/detail/amphenol-sine-systems-corp/ACJS-MHDR/7105422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)
P | P | 9 | 2 | LED1, LED2 | 5988380117F | Led | LED_APA3010SRCPRV-GX_KNB | SMD Led Green 90º position |  | 350-3034-2-ND (https://www.digikey.es/es/products/detail/dialight/5988380117F/2672539)
P | NO | 10 | 1 | FLX2 | FLEX8 | Cabling |  | Polyester flexible PCB. 2 Layers | poliester

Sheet: Historico
HISTÓRICO
VERSIÓN | FECHA | AUTOR | CAMBIO
0 | 27 mayo 2022 | J.Rodriguez | Creación

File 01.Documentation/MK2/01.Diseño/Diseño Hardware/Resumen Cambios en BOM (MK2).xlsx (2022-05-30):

CAMBIOS EN BOM -- MK2
Mayo 2022
 |  |  |  | Añadir unidades en BOM
 |  |  |  | Componentes Nuevo. Comprar
 |  |  |  | No comprar ó disminuir cantidad en BOM
EDCPSUMK2r1
Posicion | Tipo | Value | Cambio | DigikeyCode | Precio
Pos2 | Resistor | 10k | 1 | -
Pos6 | Resistor | 1k | 2 | -
Pos9 | Resistor | 220k | 1 | -
Pos13 | Resistor | 33R | -1 | -
Pos14 | Resistor | 330R | 2 | -
Pos22 | Capacitor | 100nF | -1 | -
Pos23 | Capacitor | 10uF | -1 | -
Pos27 | Capacitor | 1uF | 1 | -
Pos44 | Semiconductor | 2N7002PW | 1 | 2N7002W-7-F (https://www.digikey.es/en/products/detail/diodes-incorporated/2N7002W-7-F/814962)
Pos46 | Semiconductor | Schottky 60v 2A | -1 | SK54L-TPMSCT-ND (https://www.digikey.es/en/products/detail/micro-commercial-co/SK54L-TP/1990356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)
Pos70 | Resistor | 100R | 2 | -
Pos71 | Resistor | 56k | 1 | -
Pos72 | Resistor | 5k1 | 2 | -
Pos73 | Resistor | 100k | 1 | -
Pos74 | Resistor | 100mR | 1 | 273-KDV12DR100ETTR-ND (https://www.digikey.es/en/products/detail/ohmite/KDV12DR100ET/10476622) | 0.049
Pos75 | Connector | DX07S016JA1R1500 | 1 | 670-DX07S016JA1R1500TR-ND (https://www.digikey.es/en/products/detail/jae-electronics/DX07S016JA1R1500/11585731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) | 1.04
Pos76 | Semiconductor | MAX9064EUK+T | 1 | MAX9064EUK+TTR-ND (https://www.digikey.es/en/products/detail/analog-devices-inc-maxim-integrated/MAX9064EUK-T/1937852) | 0.59
Pos77 | Semiconductor | IP2721 | 1 | YA COMPRADO! | 0.65
Connectors_MK2-Dual-r1
Posicion | Tipo | Value | Cambio | DigikeyCode | Precio
Pos1 | Resistor | 10k | 1 | -
Pos2 | Resistor | 220R | 2 | -
Pos3 | Resistor | 330R | 1 | -
Pos4 | Resistor | 3k3 | 1 | -
Pos5 | Resistor | 47k | 2 | -
Pos6 | Semiconductor | 2N7002 | 5 | 2N7002W-7-F (https://www.digikey.es/en/products/detail/diodes-incorporated/2N7002W-7-F/814962) | 0.08
Pos7 | Semiconductor | SI4425DY | 2 | 2156-SI4425DY-ND (https://www.digikey.es/es/products/detail/rochester-electronics-llc/SI4425DY/12129450) | 0.7
Pos8 | Connector | ACJS-MHDR | 1 | 889-1817-ND (https://www.digikey.es/en/products/detail/amphenol-sine-systems-corp/ACJS-MHDR/7105422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)
Pos9 | Semiconductor | APA3010SRCPRV-GX | 2 | 754-1577-2-ND (https://www.digikey.es/en/products/detail/kingbright/APA3010SRCPRV-GX/2757938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) | 0.088

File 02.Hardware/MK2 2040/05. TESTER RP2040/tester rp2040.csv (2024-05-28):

Qty | Value | Device | Package | Parts | Description
7 |  | CONN_01 | 1X01 | J3, J4, J5, J6, J7, J8, J9 | Single connection point. Often used as Generic Header-pin footprint for 0.1 inch spaced/style header connections
1 |  | LED3MM | LED3MM | LED1 | LEDs
1 |  | RPI_PICO_IG-TH | RPI_PICO_TH | X1
4 | 100R | RESISTOR0805 | 0805 | R8, R15, R28, R30 | Generic Resistor Package
2 | 100k | RESISTOR0402 | 0402 | R2, R16 | Generic Resistor Package
3 | 100n 50v X7R/X5R | CAP0805 | 0805 | C9, C10, C11 | Capacitor
1 | 10k | RESISTOR0805 | 0805 | R66 | Generic Resistor Package
1 | 130R | RESISTOR0805 | 0805 | R35 | Generic Resistor Package
1 | 250mA/100V | DIODE-BAS16J | SOD-323 | D1 | Diode
3 | 2N7002PW | MOSFET-NCHANNEL2N7002PW | SOT323 | Q2, Q3, Q6 | Common NMOSFET Parts
3 | 2k2 | RESISTOR0805 | 0805 | R25, R26, R27 | Generic Resistor Package
1 | 302-S201 | 302-S201 | SHDR20W66P254_2X10_3300X905X90 | J1 | CONN HEADER VERT 20POS GOLD
5 | 33 | RESISTOR0805 | 0805 | R20, R21, R22, R24, R29 | Generic Resistor Package
1 | 330R | RESISTOR0805 | 0805 | R31 | Generic Resistor Package
4 | 47 | RESISTOR0805 | 0805 | R3, R9, R11, R13 | Generic Resistor Package
1 | 47K | RESISTOR0805 | 0805 | R6 | Generic Resistor Package
2 | 47k | RESISTOR0402 | 0402 | R1, R5 | Generic Resistor Package
5 | 51k | RESISTOR0805 | 0805 | R4, R7, R10, R12, R14 | Generic Resistor Package
1 | BAV199 | BAV199 | SOT23 | D2 | DIODE
1 | Display | OLED_LCD | OLED_LCD | DISPLAY
1 | MAX4634EUB+T | MAX4634EUB+T | SOP50P490X110-10N | IC1 | Multiplexer Switch ICs Fast, Low-Voltage, 4 Ohm, 4-Channel CMOS Analog Multiplexer
1 | MMSZ5227B-7-F | MMSZ5227B-7-F | SOD3716X135N | Z1 | Diode Zener 3.6V 5% 500mW 2Pin SOD123 Diodes Inc MMSZ5227B-7-F Zener Diode, 3.6V 5% 500 mW SMT 2-Pin SOD-123
3 | MOMENTARY-SWITCH-SPST-SMD-5.2MM | MOMENTARY-SWITCH-SPST-SMD-5.2MM | TACTILE_SWITCH_SMD_5.2MM | S1, S2, S3 | Momentary Switch (Pushbutton) - SPST
4 | PJA3416AE_R1_00001 | PJA3416AE_R1_00001 | SOT23_PJA3416_PNJ | Q1, Q5, Q8, Q9
2 | RQ3G110ATTB | RQ3G110ATTB | RQ3G110ATTB | Q4, Q7 | ROHM - RQ3G110ATTB - Power MOSFET, P Channel, 40 V, 35 A, 0.0098 ohm, RDS 12.4m, PD 20W, HSMT8, Surface Mount

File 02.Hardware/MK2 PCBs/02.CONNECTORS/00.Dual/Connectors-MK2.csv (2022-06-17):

Qty | Value | Device | Package | Parts | Description
1 | 10k | RESISTOR0603 | 0603 | R3 | Generic Resistor Package
2 | 220R | RESISTOR0603 | 0603 | R8, R9 | Generic Resistor Package
5 | 2N7002PW | MOSFET-NCH-2N7002PW | SOT323 | Q1, Q2, Q3, Q4, Q5 | N-channel MOSFETs
1 | 330 | RESISTOR0603 | 0603 | R4 | Generic Resistor Package
1 | 3k3 | RESISTOR0603 | 0603 | R7 | Generic Resistor Package
2 | 47k | RESISTOR0603 | 0603 | R5, R6 | Generic Resistor Package
3 | ACJS-MHDR | ACJS-MHDR | CONN_MHDR_AMP | MACHINE1, MACHINE2, PEDAL
2 | APA3010SRCPRV-GX | APA3010SRCPRV-GX | LED_APA3010SRCPRV-GX_KNB | LED1, LED2
1 | FLEX8 | FLEX8 | FLEX8 | K1 | WR-FPC 1mm SMT Horiz. Bot. Contact Hinge type WR-FPC 1mm 08 pins Hinge type SMT Horizontal Bottom Contact
2 | SI4459ADY-T1-GE3 | SI4459ADY-T1-GE3 | SOIC127P600X175-8N | Q6, Q7 | Trans MOSFET P-CH 30V 29A 8-Pin SOIC N T/R

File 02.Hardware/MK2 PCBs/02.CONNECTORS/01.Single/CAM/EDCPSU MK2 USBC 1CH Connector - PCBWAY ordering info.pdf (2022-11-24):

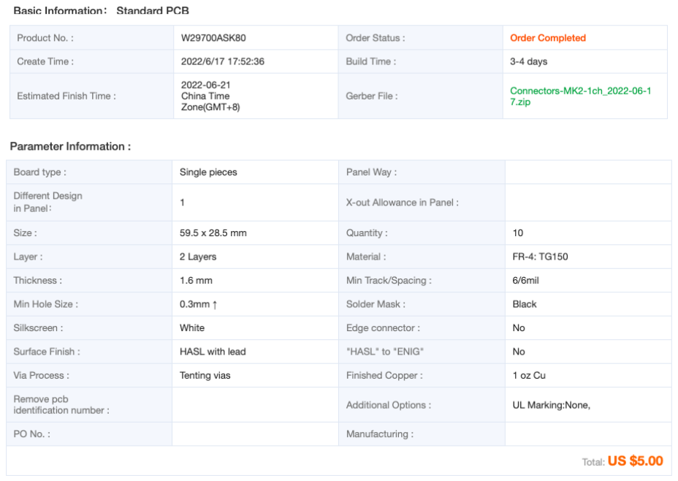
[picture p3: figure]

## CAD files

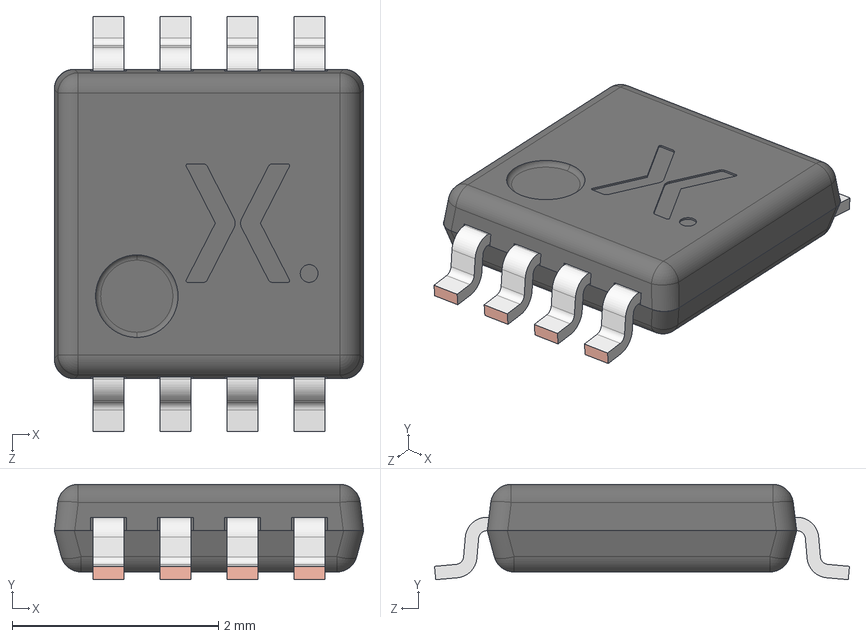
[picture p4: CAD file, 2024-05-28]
01.Documentation/MK2040/01.Diseño/Librerias EAGLE/LIB_74LVC1G74DP,125/74LVC1G74DP,125/3D/74LVC1G74DP,125.stp
3.00 x 0.925 x 4.02 mm
SOT505-2 Lower mold body
SOT505 Lead x 8
SOT505-2 Upper mold body

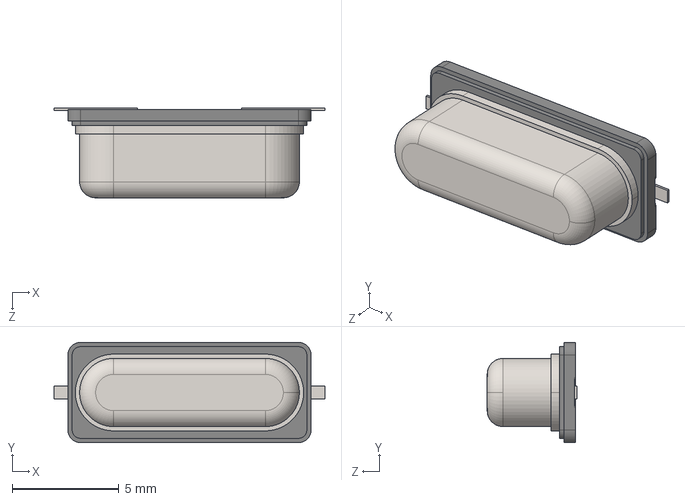
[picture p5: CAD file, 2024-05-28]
01.Documentation/MK2040/01.Diseño/Librerias EAGLE/LIB_ABLS-12.000MHZ-B4-T/ABLS-12.000MHZ-B4-T/3D/ABLS-12.000MHZ-B4-T.stp
12.7 x 4.70 x 4.20 mm

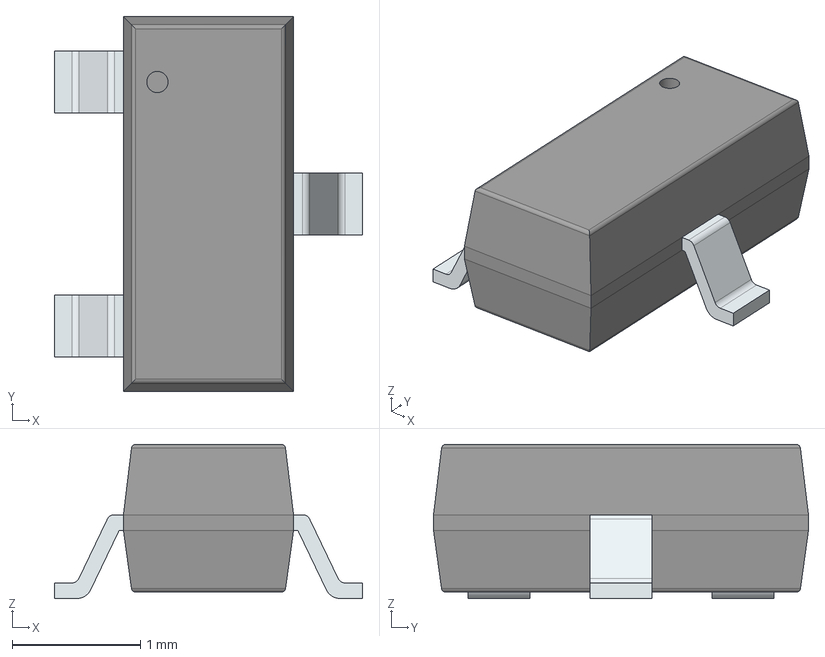
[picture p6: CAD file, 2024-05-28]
01.Documentation/MK2040/01.Diseño/Librerias EAGLE/LIB_MMBD1503A/MMBD1503A/3D/MMBD1503A.stp
2.40 x 2.92 x 1.20 mm
PinsArrayL
FilletPinR

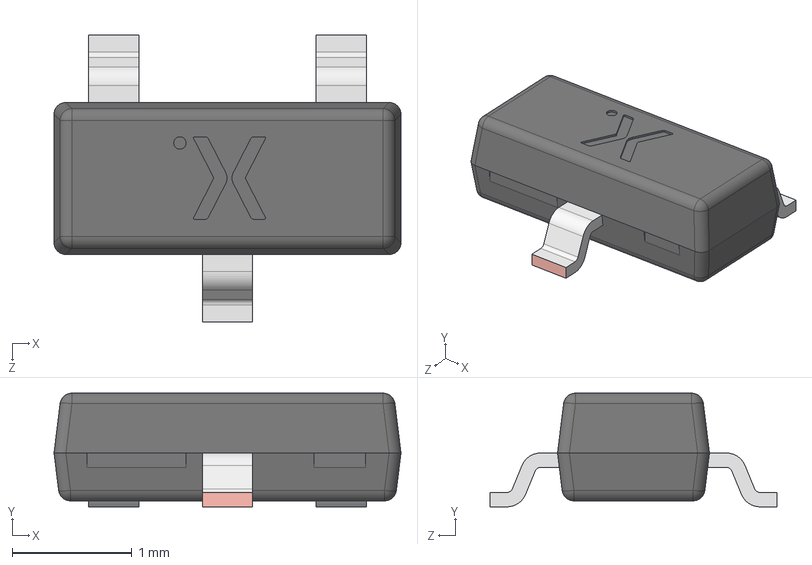
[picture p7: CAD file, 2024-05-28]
01.Documentation/MK2040/01.Diseño/Librerias EAGLE/LIB_PESD5V0U2BT,215/PESD5V0U2BT,215/3D/PESD5V0U2BT,215.stp
2.90 x 0.95 x 2.40 mm
SOT23 lower body
SOT23 Lead x 3
SOT23 Upper body

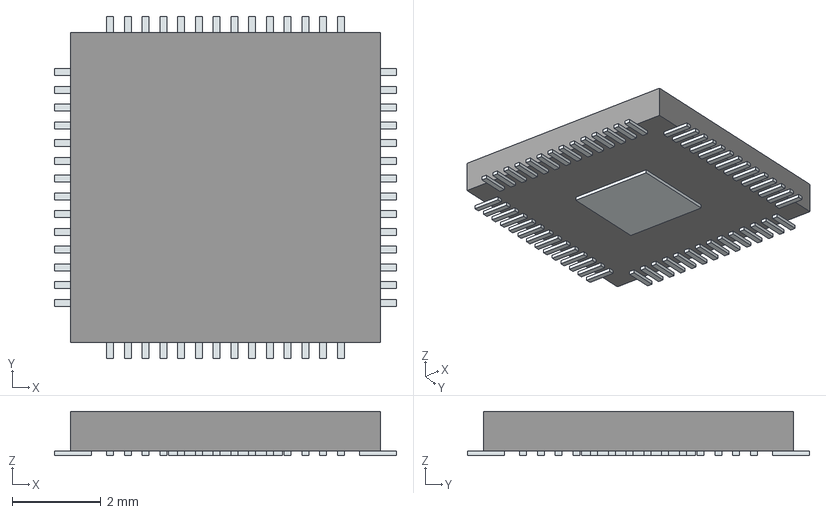
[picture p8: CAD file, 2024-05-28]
01.Documentation/MK2040/01.Diseño/Librerias EAGLE/LIB_RP2040TR7/RP2040TR7/3D/RP2040TR7.stp
7.71 x 7.71 x 1.00 mm
Pins

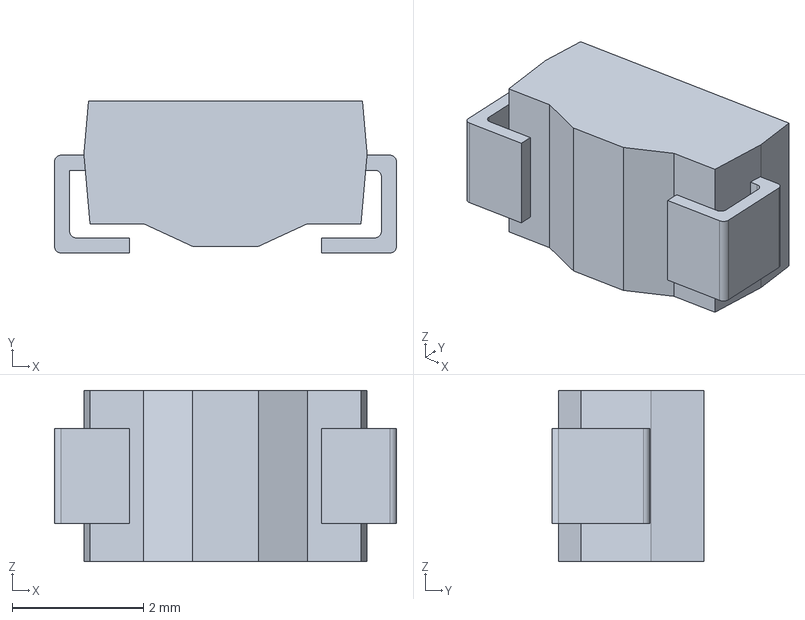
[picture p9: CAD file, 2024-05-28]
01.Documentation/MK2040/01.Diseño/Librerias EAGLE/LIB_SMAJ24CA/SMAJ24CA/3D/SMAJ24CA.stp
5.21 x 2.31 x 2.60 mm

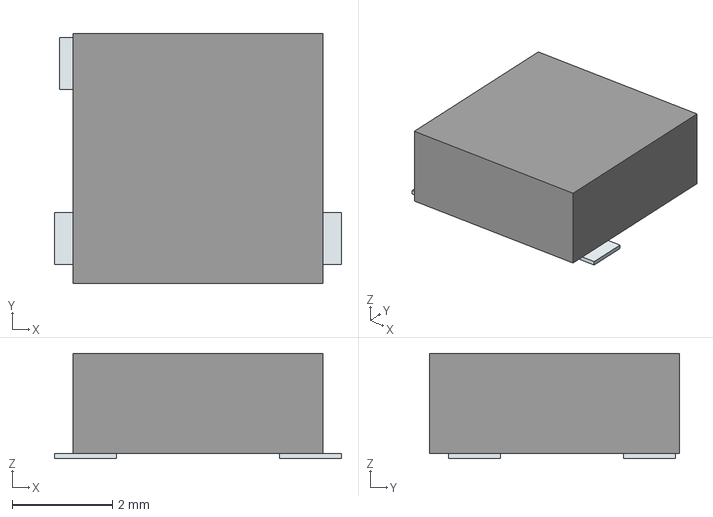
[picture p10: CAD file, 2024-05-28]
01.Documentation/MK2040/01.Diseño/Librerias EAGLE/LIB_SMT-0540-S-R/SMT-0540-S-R/3D/SMT-0540-S-R.stp
5.74 x 5.00 x 2.10 mm
Pins

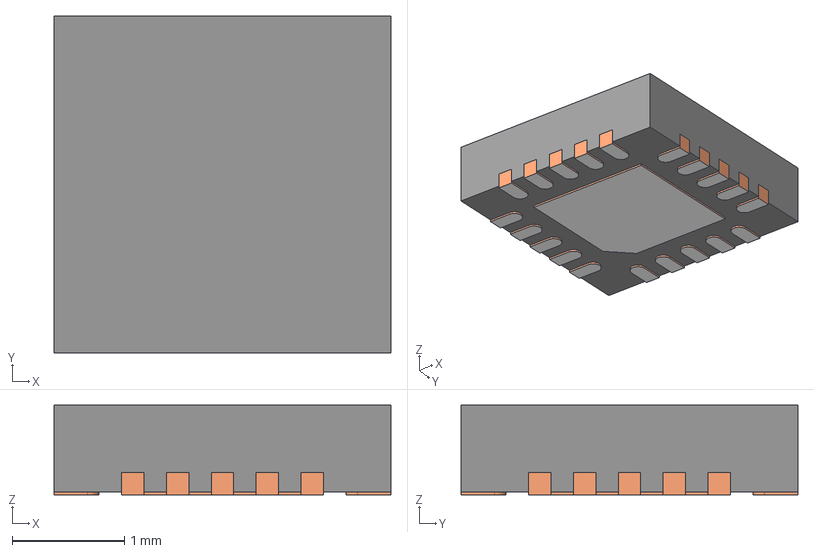
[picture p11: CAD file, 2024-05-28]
01.Documentation/MK2040/01.Diseño/Librerias EAGLE/LIB_TPD8S300RUKR/TPD8S300RUKR/3D/TPD8S300RUKR.stp
3.00 x 3.00 x 0.8 mm
BODY-QFN
FRAME-RUK0020B
PIN1-ID

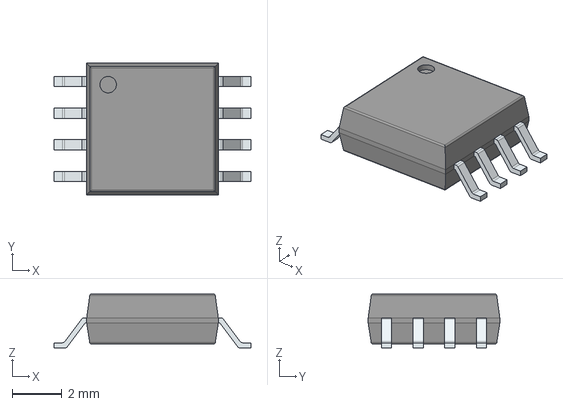
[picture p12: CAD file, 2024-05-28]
01.Documentation/MK2040/01.Diseño/Librerias EAGLE/LIB_W25Q64JVSSIQ/W25Q64JVSSIQ/3D/W25Q64JVSSIQ.stp
7.90 x 5.28 x 2.16 mm
PinsArrayLR

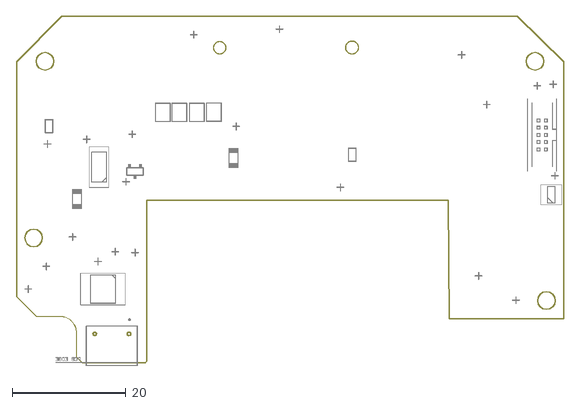
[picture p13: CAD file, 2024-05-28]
02.Hardware/MK2 2040/01.EDCPSU/EDCPSUMK2-RP2040.dxf
96.1 x 61.4

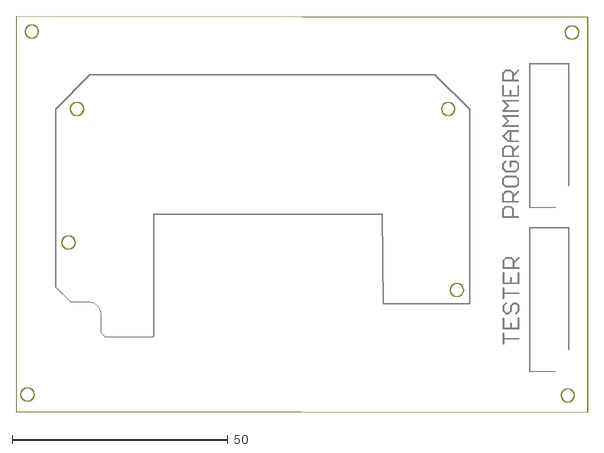
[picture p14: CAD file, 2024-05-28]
02.Hardware/MK2 2040/02.POGO-TEST/POGOTEST-MK2RP2040.dxf
132.6 x 92.0

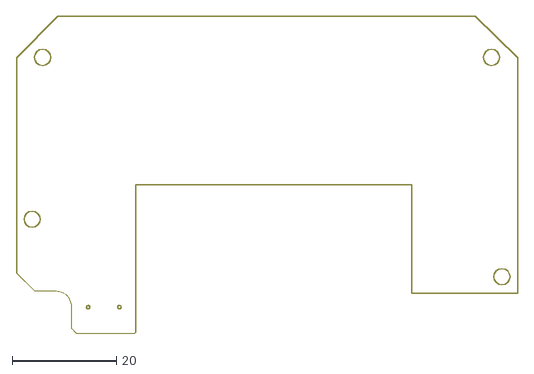
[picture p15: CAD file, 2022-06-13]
02.Hardware/MK2 PCBs/01.EDCPSU/EDCPSUMK2.dxf
96.1 x 60.9

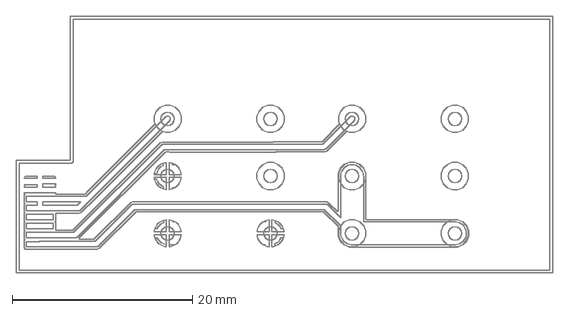
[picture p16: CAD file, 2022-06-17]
02.Hardware/MK2 PCBs/02.CONNECTORS/01.Single/Connectors-MK2-1ch.dxf
59.5 x 28.5 mm

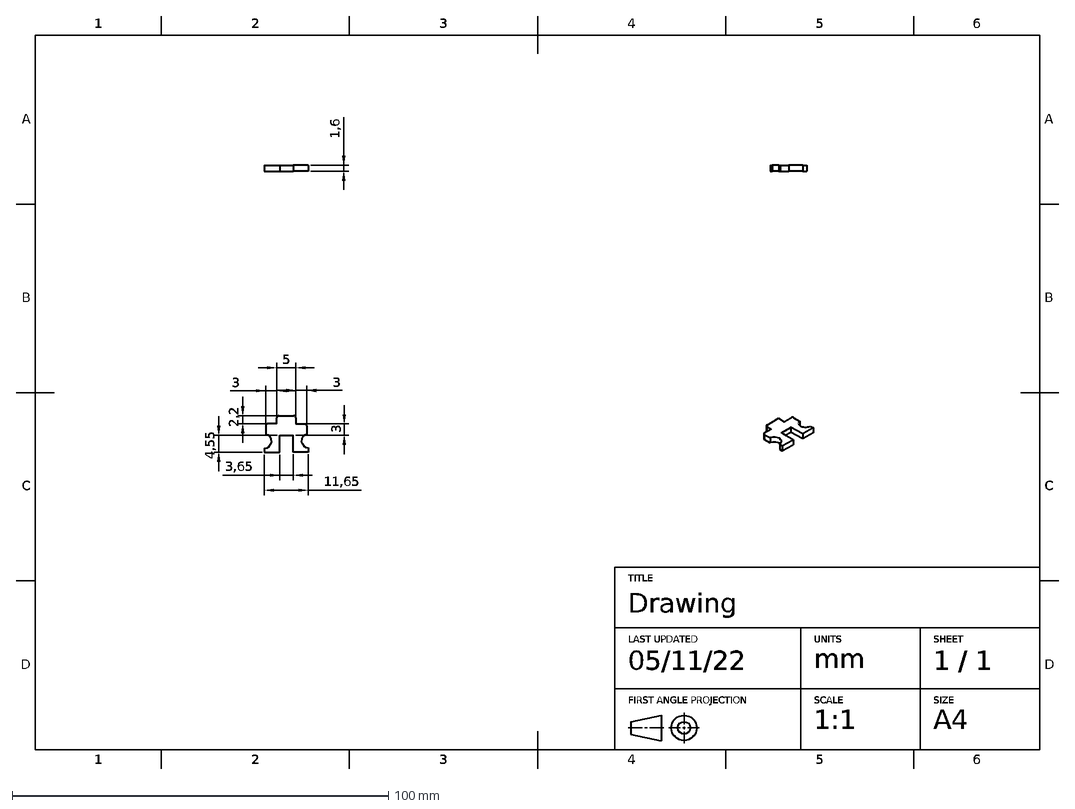
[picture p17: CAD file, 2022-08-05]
02.Hardware/MK2 PCBs/03.TESTS/Lentilla/Drawing 2.dxf
11,65
3
5
3,65
4,55
2,2
1,6
1
2
4
6
D
C
B
A
TITLE
Drawing
LAST UPDATED
05/11/22
UNITS
mm
SHEET
1 / 1
FIRST ANGLE PROJECTION
SCALE
1:1
SIZE
A4

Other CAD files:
02.Hardware/MK2 PCBs/03.TESTS/PRUEBA MECANICA-EDCPSUr16D/MECH_EDCPSUr16D_USBC/EDCPSU_M2 v1.dxf
02.Hardware/MK2 PCBs/03.TESTS/USBC-OVC_LIMIT/CAMOutputs/DrawingFiles/USBC-OVC_LIMIT.dxf
02.Hardware/MK2 PCBs/04.FAJA USBC/FAJA_LARGA_USBC.dxf
01.Documentation/MK2040/01.Diseño/Librerias EAGLE/LIB_74LVC1G74DP,125/74LVC1G74DP,125/Allegro/sop65p400x110-8n.psm
01.Documentation/MK2040/01.Diseño/Librerias EAGLE/LIB_74LVC1G74DP,125/74LVC1G74DP,125/DEHDL/74lvc1g74dp_125/chips/chips.prt
01.Documentation/MK2040/01.Diseño/Librerias EAGLE/LIB_ABLS-12.000MHZ-B4-T/ABLS-12.000MHZ-B4-T/Allegro/abls.psm
01.Documentation/MK2040/01.Diseño/Librerias EAGLE/LIB_ABLS-12.000MHZ-B4-T/ABLS-12.000MHZ-B4-T/DEHDL/abls_12.000mhz_b4_t/chips/chips.prt
01.Documentation/MK2040/01.Diseño/Librerias EAGLE/LIB_AP63201WU-7/AP63201WU-7/3D/AP63201WU-7.stp
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

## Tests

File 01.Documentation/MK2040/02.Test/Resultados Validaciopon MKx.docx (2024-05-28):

# Resultados Validaciopon MKx-RP2040

# 1 alimentación 3v3

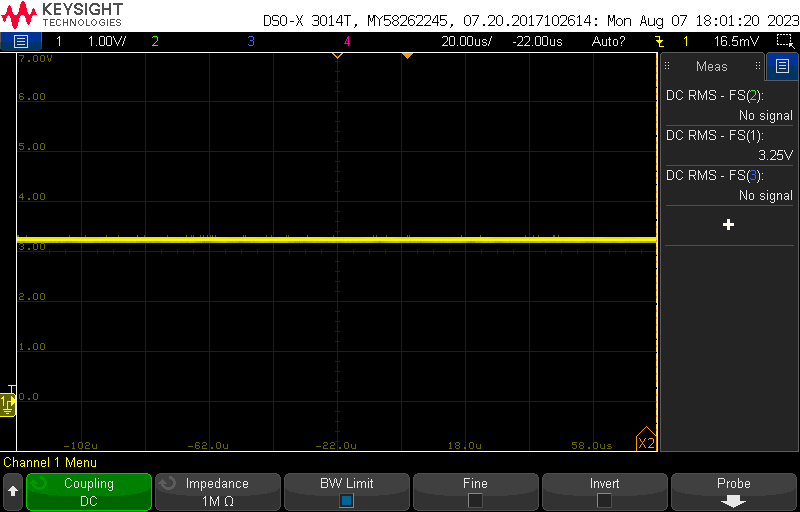
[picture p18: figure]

## 1.1 vacío

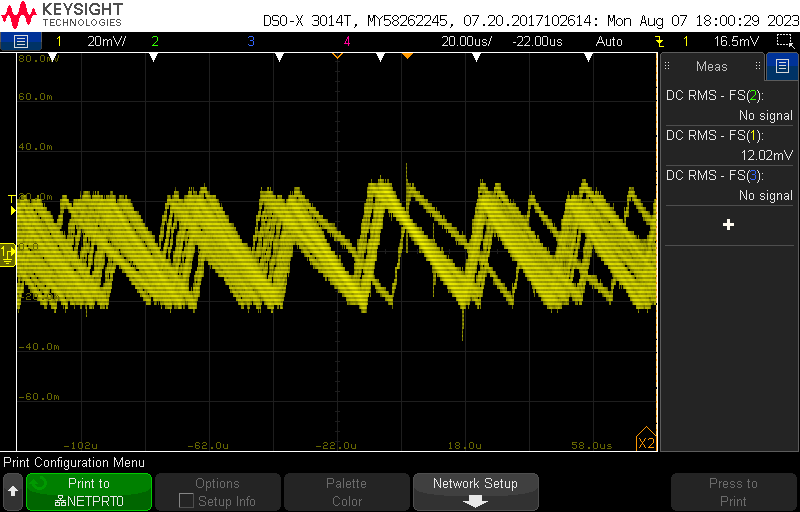
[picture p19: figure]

20mV de rizado

## 1.2 Resistencia de 33 Ohm a la salida

Sin cambios apreciables ni en vlaor ni en rizado

## 1.3 Arranque del sistema

4,5 ms en vacio. Sin cambios en valor fina con carga.

# 2 Guardado en EEPROM

Para comprobar la eeprom se enciende se fija un valor disitinto.

Se espera a que salga el indicador REC que marcaria el guardado en EEPROM.

Se desconecta la alimentacion

Al conectarla de nuevo se observa que efectivamente el valor se ha guardado.

En MK2, se repite el proceso para el NITRO y para el Chanel 2.

En MK1, se repite para las 4 memorias.

En todos los casos se recibe un valor positivo.

# 3 Rotary + Pulsador

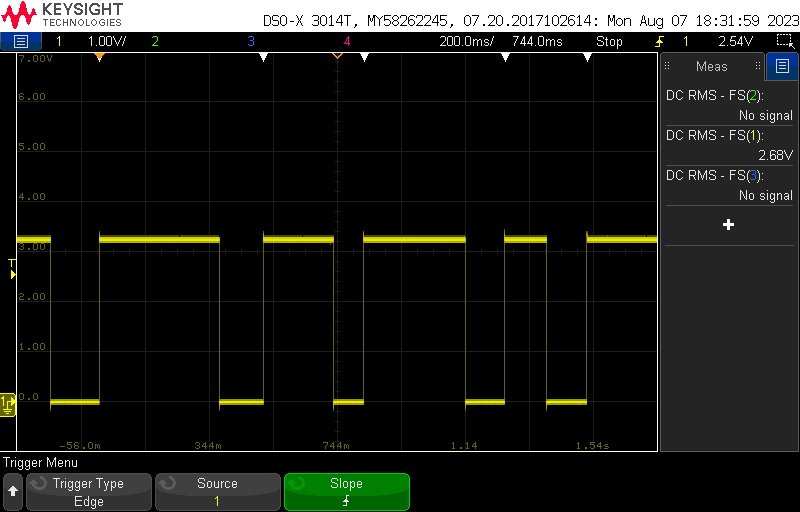
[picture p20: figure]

## 3.1 Pulsacion pulsador

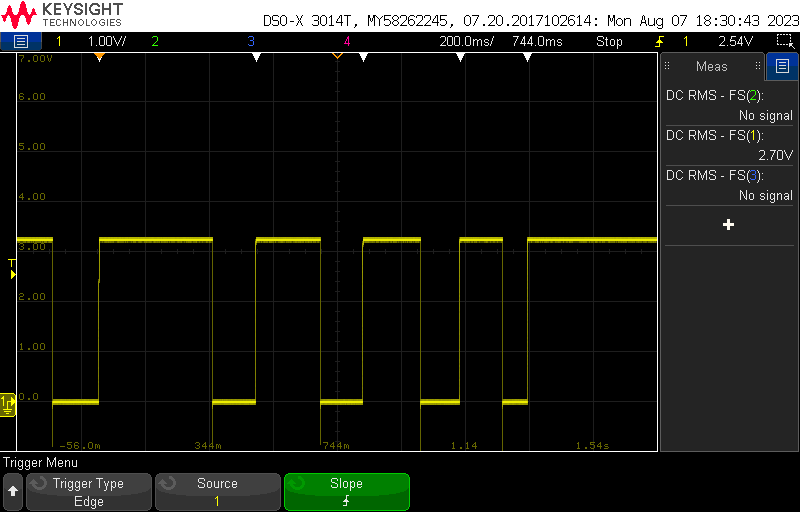
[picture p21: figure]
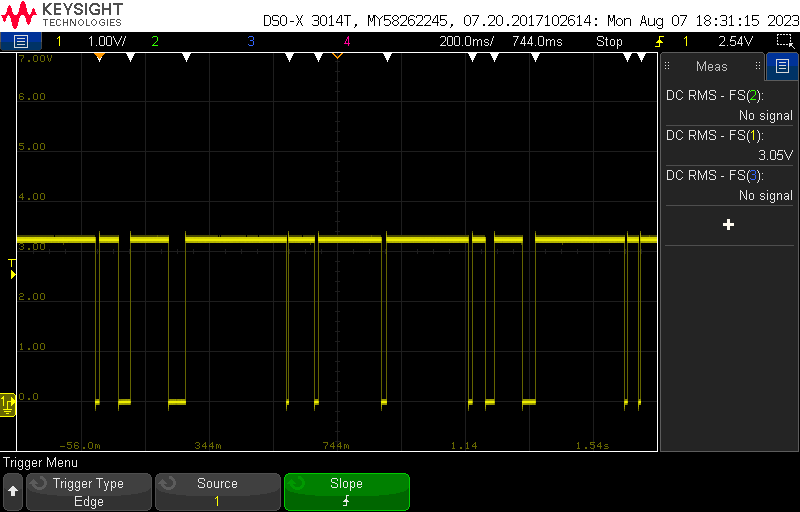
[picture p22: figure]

## 3.2 Pulsacion Rotary

## 3.3 Rotación A

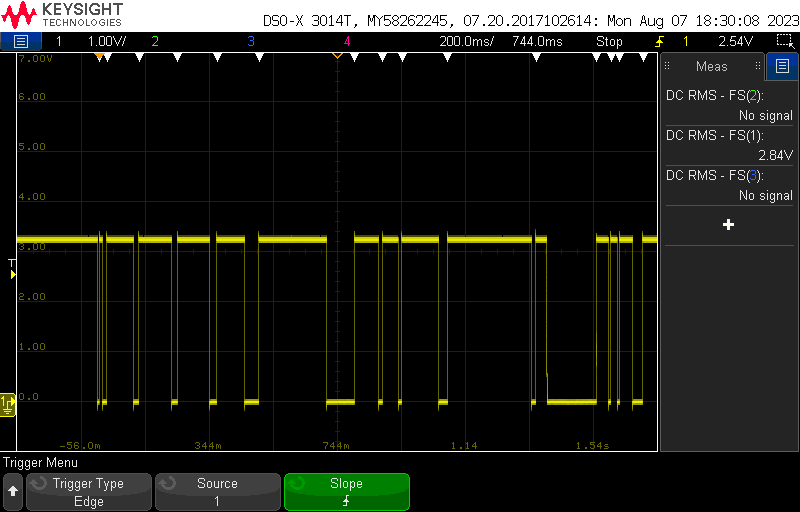
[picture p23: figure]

## 3.4 Rotación B

# 4 Referencia de Tensión de 3v

Valor DCDC.

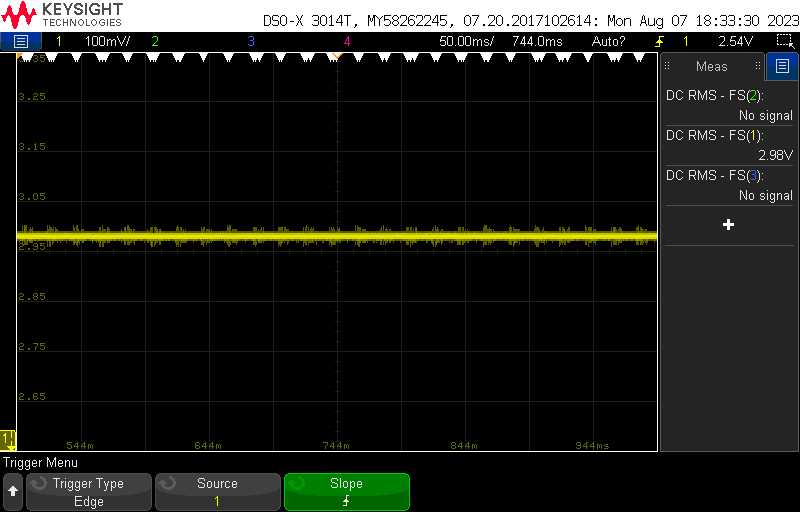
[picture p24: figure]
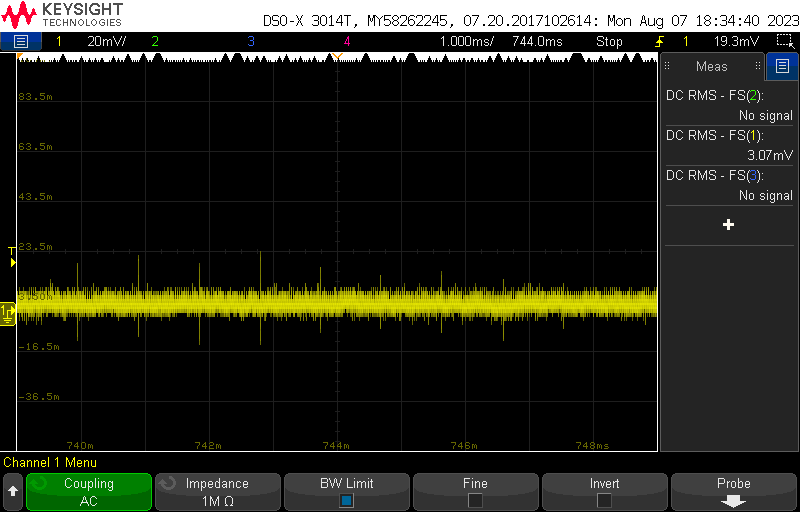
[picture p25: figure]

Rizado.

# 5 Sensados

## 5.1 Corriente de Salida

Isense = Iout*0.025mOhm * 25G

#cuentas ADC = Iout * 0.625 * 1/3v * 1024

## 5.2 Tensión de Salida

Vout_sense = Vout * 27/177 = Vout * 0.1525

#cuentas ADC = Vout * 0.1525 * 1/3v * 1024

## 5.3 Tensión de Entrada

Vin_sense = IN+ * 56/446 = Vout * 0.1255

#cuentas ADC = IN+ * 0.1255 * 1/3v * 1024

# 6 Control de tensión de alimentación

Gracias al sensado de tensión de entrada, el micro es capaz de detectar correctamente las tensiónes por debajo del umbral (17.5v) y no permite el trabajar por con tensiones por debajor. Se hacen pruebas con

20v -> Permite Trabajar

12 → Corta

5 → Corta

# 7 Pedal

## 7.1 Corriente

La corriente con la trabaja el pedal es de 14,5mA

## 7.2 Corriente mínima de funcionamiento

Se hacen pruebas colocado distintos valores de resistencias cerrando los contactos del pedal y midiendo la corriente que circula.

Se obtiene que la corriente mínima (aproximada) de funcionamiento se encuentra entre 1 – 1.2mA

# 8 Comparador de OVC de la entrada

1º Se puentea la resistencia de sensado de salida

2º Se intena hacer mediante cortocircuito → El DCDC no lo agaunta.

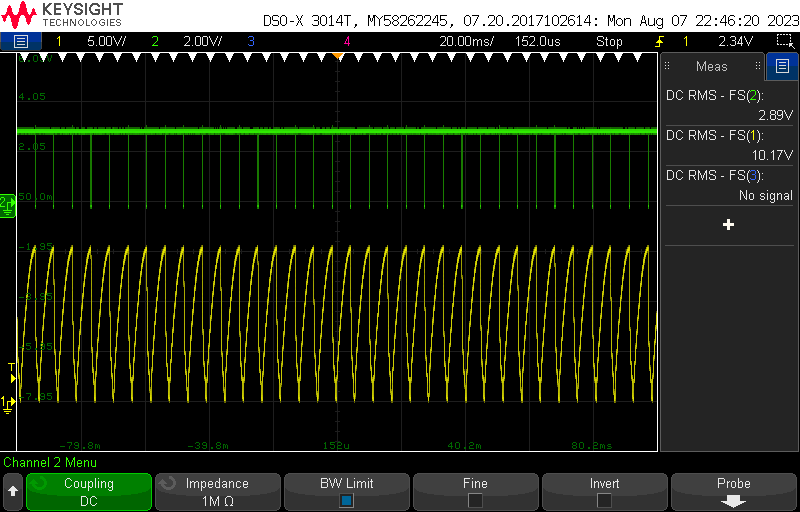
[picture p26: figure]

3º Se hace a 16v @ 6.6Ohm (5.1 +1.5) → 2.5 A entrada → Salta correctamente.

4º Se hace a 16v @ 5.1 Ohm → 48W aprox → Salta Correctamente

Pulso en EN_DCDC debido al comparador → 40us

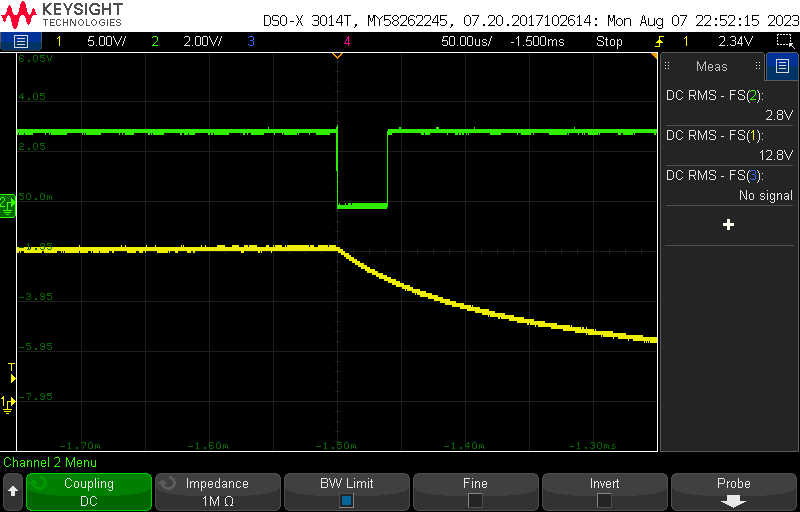
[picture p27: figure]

Pulso en OVC_Alarm tras quitar el condensador C54 que filtraba la señal.

MK2 Atmega → Protección de cobre corriente a la entrada => Salta.


# 9 DCDC

## 9.1 I2C


SDA


SCL

## 9.2 Escalera en Vacio


Rizado 2v


Rizado 9v


Rizado 16

## 9.3 Escalera con carga


Caída por el mosfet → Vgs inestable

5v @ 2 Ohm → 11,25W → Faja y DCDC a 45ºC


5.5v @ 5.1 Ohm → 5.5W → DCDC a 43ºC


9v @ 5.1 Ohm → 16.2W → Faja y DCDC a 50ºC


9v @ 10 Ohm → 8.1 W → DCDC a 43ºC


12.5v @ 10 Ohm → 15.625W → DCDC a 45ºC


16v @ 10 Ohm → 25.6W → DCDC a 40ºC


## 9.4 Comprobador de Producción

El corte por sobre corriente se encuentra tarado por software a 3A .

En el caso del comprobador de producción salta a partir de los 8,1V para una corriente marcada de 2.9 A.

## 9.5 Cortocircuito franco

El DCDC cae. En el caso de la MK1 caerá la tensión del alimentador y por tanto se activa la protección del DCDC en el Enable.

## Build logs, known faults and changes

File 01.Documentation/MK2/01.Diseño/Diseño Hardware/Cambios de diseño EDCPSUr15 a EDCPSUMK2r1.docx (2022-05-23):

# Cambios de diseño EDCPSUr15 a EDCPSUMK2r1.

Componente cambiado | Descripcion del cambio.
R34,R38,R40,LED3,LED2,Q1 | Extirpacion de la célula de test por deshuso.
D5 | Overkill
C52,CR1,K1,D3,Q3,R30 | Célula del relé a la salida del DCDC.

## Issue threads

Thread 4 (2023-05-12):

Cambiar conector de programacion

Jmusotoku, 2023-05-12:
Cambiar el conector de programacion de paso 1.27 al mismo conector  que tiene la [CPU de la bateria.
](https://www.digikey.es/es/products/detail/hirose-electric-co-ltd/DF40C-2-0-20DS-0-4V-51/1967923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)

Cuesta la mitad y hemos visto que tiene bastante resistencia a quitar y poenrse varias veces, ademas que podemos diseñar la placa tal y como queramos.

Closed 2024-04-23.

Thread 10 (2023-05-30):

Rectificacion de la referencia de tension del ADC.

Jmusotoku, 2023-05-30:
**TARADO DE FONDO DE ESCALA**
Los divisores de tensión para las medidas del ADC están taradas a 3v mientras que la referencia de tensión es de 2.5.

**SOLUCION**:
Cambiar la referencia de  tensión a un modelo de 3v.

**R57 ERRONEA**
Durante las pruebas de test de la versión 1 de la placa, se descubrió que el valor de R57, 800R, no es un valor estándar y debido a eso se monto una resistencia de 10K que impedía el correcto funcionamiento de la referencia de tensión.

**SOLUCION**:
Cambiar el valor a 1k, un valor estandar y que permite el correcto funcionamiento de la referencia (150uA min para el ADC + 45uA de la referencia)
Aunque es suficiente una corriente de 200uA vamos a calcular R57 para  1mA
Ahora, al ser la referencia de 3v en vez de 2.5v, hay que recalcular R57.
(3.3-3v)/1mA = aprox 330R

david-reo, 2023-05-31:
Hay que cambiar tambien las referencias al valor anterior de 2.5V

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

Closed 2024-04-23.

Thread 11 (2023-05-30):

Re-diseño de la proteccion hardwward de UV

Jmusotoku, 2023-05-30:
La proteccion de UnderVoltage situada a la entrada del enable de DCDC tiene que recalcularse ya que el los valores de hysteresis del funcionamiento del DCDC son distintos al anterior:
Vh = 1.18
Vl = 1.09

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

SOLUCION:
Siguiendo la formula del datasheet, se obtienen los nuevos valores: 150k y 11K para cotar si la tensión cae por debajo de los 16v

Closed 2024-04-23.

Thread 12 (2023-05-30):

Ajuste de la resistencia de sensado de la tension de salida

Jmusotoku, 2023-05-30:
Al cambiar el fondo de escala del ADC a 3v es necesario reajustar las ganancias en los sensados.
El sensado de la corriente de salida se rige por la formula:
Visense = Iout * R12 *25

Para un limite de 3v y una corriente máxima de 4 A, sale que hay que poner una resistencia de al menos 30mR.

SOLUCION:
R12 pasa de 50mR a 25mR. Permitiendo medir hasta 4,8A.

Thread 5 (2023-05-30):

Cambio ocnectro SWD

Jmusotoku, 2023-05-30:
El conectro colocado actualemnte es demasiado caro. Se decide cambiar en un futuro por el conector usado en el bateria debido a que es mas barato.

Todo esto estaria potenciado si la programacion a traves de los pogopins no fuese bien y fuese un problema.

Closed 2024-04-23.

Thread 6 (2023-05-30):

Apartr de cobre debajo de U12 (DCDC)

Jmusotoku, 2023-05-30:
Debido a problema con el integrado U12,  ha sido necesario desoldarlo. Este compoennte tien un pad de dispiacion inferior al cual esta soldado que dificulta mucho su desmontaje.

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

Se decide abrir el cobre de la capa de bottom para, en caso de ser necesario desmontar el componente, se pudiese aplicar calor desde la parte de abajo para desoldar el pad de  disipación y asi poder retirar el componente.

Jmusotoku, 2023-05-30:
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

Closed 2024-04-23.

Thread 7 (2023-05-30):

Error en el diseño del DCDC de 3v3

Jmusotoku, 2023-05-30:
Durante el test del diseño v1 e la placa EDPSU MK2 RP2040, el DCDC de 3v3 no funciono correctamente.

El problema es el fallo de diseño presente y que se puede comprobar al mirar al datasheet.
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

El FB no se encuentra conectado a la salida. por lo que se encuentra el DCDC en lazo abierto.

SOLUCION:
Se decide cambiar el jumper uno Normalmente Cerrado y poner una resistencia de 0Ohm en R15.

Closed 2024-04-23.

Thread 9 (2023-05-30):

Error Diseño Buzzer EDCPSUMK2 RP2040

Jmusotoku, 2023-05-30:
Durante la etapa de test de la versión 1 del diseño, se descubrió que el diodo de la DCDC de 3v3 se calentaba.

Al comprobar porque se descubrió que error en el diseño del buzzer.
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

Al poner el diodo D3 en serie con la resistencia, y con esa orientación, se conseguía que los 19v estuvieran directamente conectados a los 3v3 v produciendo que el zener se calentara.

SOLUCION:

No montar el diodo D3.

Closed 2024-04-23.

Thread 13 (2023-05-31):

Cambio de Zener del DCDC 3v3

Jmusotoku, 2023-05-31:
Tras las pruebas de la placa v1 del EDPSU-RP2040 se determina que el diodo DZ1 se calienta demasiado, la diferencia entre su voltaje de funcionamiento y el real es demasiado escas y circula mas corriente de la que deberia.

Se decide cambiar a un diodo de 3.9 que aumente la distancia al voltaje de funcionamiento del DCDC pero que no supongo un riesgo para el sistema.

Jmusotoku, 2023-05-31:
Se seleccion el siguiente [MMSZ5228B 3.9v](https://eu.mouser.com/ProductDetail/Diotec-Semiconductor/MMSZ5228B?qs=OlC7AqGiEDkIT4mCF6hrjg%3D%3D)

Closed 2024-04-23.

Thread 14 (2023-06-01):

El TVS de Vin (Vbus) tiene que ser UNI-DIRECCIONAL

david-reo, 2023-06-01:
Actualmente D1 es un TVS bidireccional, lo cual no tiene ningún sentido en la entrada de 19V.

**Solucion**
Se pasa a un TVS idéntico pero uni-direccional

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

Closed 2024-04-23.

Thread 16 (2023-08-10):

Ajuste de las protección de Undervolteje y Cortocircuito

Jmusotoku, 2023-08-10:
El diseño de la protección de undervoltage no es correcta.  Si se detecta una muestra por debajo del umbral, se encuentra en la protección, pero en cuanto se detecta una única fuera del umbral, se sale y no da el fallo.

Adicionalmente, cuando el voltaje es muy bajo (<4v) el voltaje no cae lo suficiente para que el sensado de la tensión de salida lo pueda medir. Esto se debe en gran medida a que al trabajar a bajo voltaje y cortocircuitar el transistor corta y tira la salida a 0, sin embargo el sensado de la salida se produce en la placa EDCPSU, por lo que se queda en el lado con los condensadores de salida del DCDC los cuales evitan que la salida caiga a 0 manteniendo entorno a los 2 V. El sensado de salida no puede medir nunca 0. Por lo tanto es necesario implementar una protección adicional para los casos del corto circuito que tenga en cuenta esta circunstancia.

Closed 2024-04-23.

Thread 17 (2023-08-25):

Mover PADS para pogopin de USB-D+ y USB-D- al otro lado del jumper entre Conector y CPU

david-reo, 2023-08-25:
Ahora mismo los testpad del USB-D+/- están en el lado del conector, de forma que si el jumper que lo une con la CPU no está hecho no hay conexión a la CPU.
Hay que cambiarlos al extremo de la CPU.

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

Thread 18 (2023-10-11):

Aislar lineas que cruzan la linea de corte de PCB para prevenir cortocircuitos.

Jmusotoku, 2023-10-11:
Las pistas que cruzan la linea de corte del PCB para convertir la MK2 en MK1 necesitanestar aisladas para prevenir que al cortar el PCB, estas hagan corto con cualquiera de los planos de las distintas capas

Closed 2024-04-23.

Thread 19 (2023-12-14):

Fallo del Nitro en los modelos de RP2040.

Jmusotoku, 2023-12-14:
Se observado que en los modelos MK1 y MK2 el Nitro es excesivamente corto (<10ms). AL conectar una maquina en la salida es inapreciable la presencia de dicho NITRO.

Es necesario realizar una modificación en el código para asegurar un mínimo de 200ms en el periodo de arranque.

Jmusotoku, 2023-12-14:
Durante la inspeccion del codigo se descubre que este carece de delay durante la escalera ascendente del NITRO.
Esto puede haber pasado desapercibido en el modelo ATMEGA debido a que la comunicacio I2C y la ejecucion de las instrucciones podian estar durando el tiempo suficiente (~5ms) como para que la escalera fuera observable y nostable.
Al pasar a un uControlador mas rapido, este tiempo se habria reducido drasticamente.

Se decide incluir un delay de 5 ms para recuperar el Nitro Previo en la version para ATMEGA y la creacion de un nuevo NITRO para la version RP2040

Jmusotoku, 2023-12-14:
Tras la modificacion y con el testeo sobre maquina se decide aumentar el delay hasta 15ms (aprox) para conseguir que la escalera ascente del Nitro durase un minimo de 200ms y fuese claramente apreciable en el arranque de las maquinas.

Closed 2024-04-23.

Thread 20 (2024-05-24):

Fallo en la produccion Hardware de la EDCPSU en algunos componentes

Jmusotoku, 2024-05-24:
OBSERVACION
La producción de SETI ha venido con algunos componentes mal. Las resistencias de pull-up del I2C no han venido soldadas.
Por otro lado los condensadores C54 y C13 que no deberían venir montados si que han venido.

DIAGNOSTICO
Tras revisar la BOM se observa que dichas indicaciones no están y por lo tanto es normal que SETI haya entregado las placas así.
Las placas son correctas según los archivos que nosotros hemos enviado.

SOLCUION
Actualización de la BOM. Generar documento de cambios para fabricación y avisar a SETI de los cambios.

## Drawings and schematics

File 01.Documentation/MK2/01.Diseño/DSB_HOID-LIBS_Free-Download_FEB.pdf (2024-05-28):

# HOID-LIBS

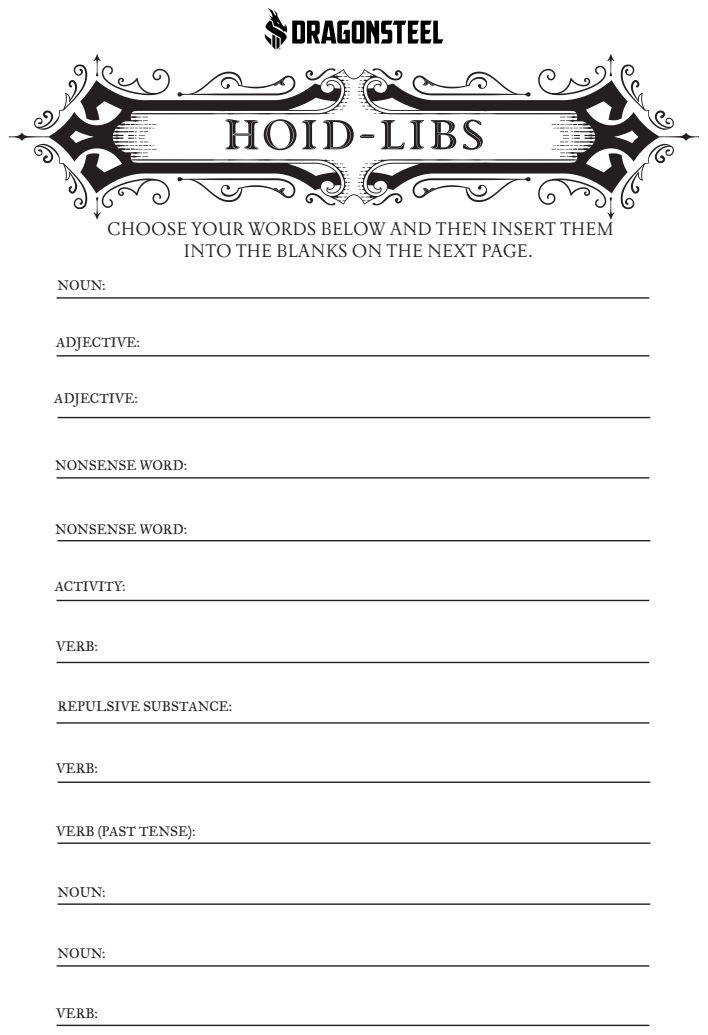
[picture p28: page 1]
NOUN:; ADJECTIVE:; NONSENSE WORD:; REPULSIVE SUBSTANCE:; VERB:; ACTIVITY:

CHOOSE YOUR WORDS BELOW AND THEN INSERT THEM

INTO THE BLANKS ON THE NEXT PAGE.

VERB (PAST TENSE):

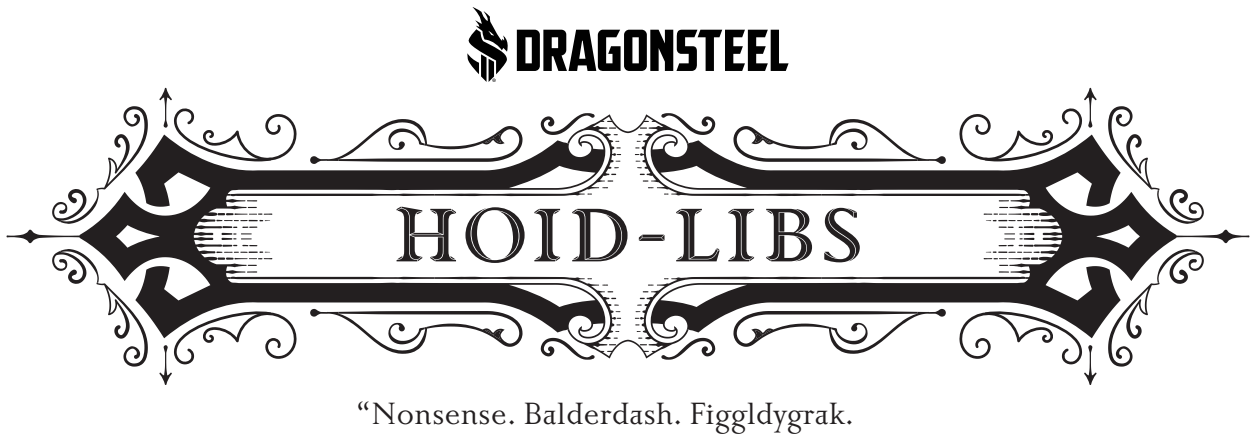
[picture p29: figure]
“Nonsense. Balderdash. Figgldygrak.; HOID-LIBS

...I wonder if you could do that to a ______________. Pull him apart, emotion by emotion, bit by bit, __________ chunk by ____________ chunk. Then combine them back together into something else, like a Dysian Aimian. If you do put a man together like that, Dalinar, be sure to name him _____________, after me. Or perhaps _______________.”

“How remarkable, [if] you spend your life __________________, you eventually find they won’t ___________ up for you. There’s poetry in that, don’t you think, you storming personification of __________________________?”

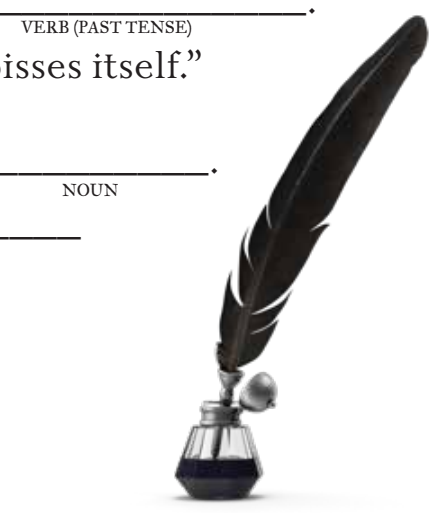
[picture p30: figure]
VERB (PAST TENSE)

“Can you ____________ it? Something just _________________.
I believe that’s the sound the world makes when it pisses itself.”

“Deal with your own stupid ___________, you ___________. Don’t make me come over there and ______________
you around again.”

Isn't it odd that gibberish words are often the sounds of other words, cut up and dismembered, then stitched into something like them —yet wholly unlike them at the same time...

NOUN

NOUN | NOUN
ADJECTIVE | ADJECTIVE
NONSENSE WORD | NONSENSE WORD

REPULSIVE SUBSTANCE

VERB

VERB

ACTIVITY

VERB

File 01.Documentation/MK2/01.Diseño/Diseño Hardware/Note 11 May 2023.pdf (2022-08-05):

100124T | ENA | X

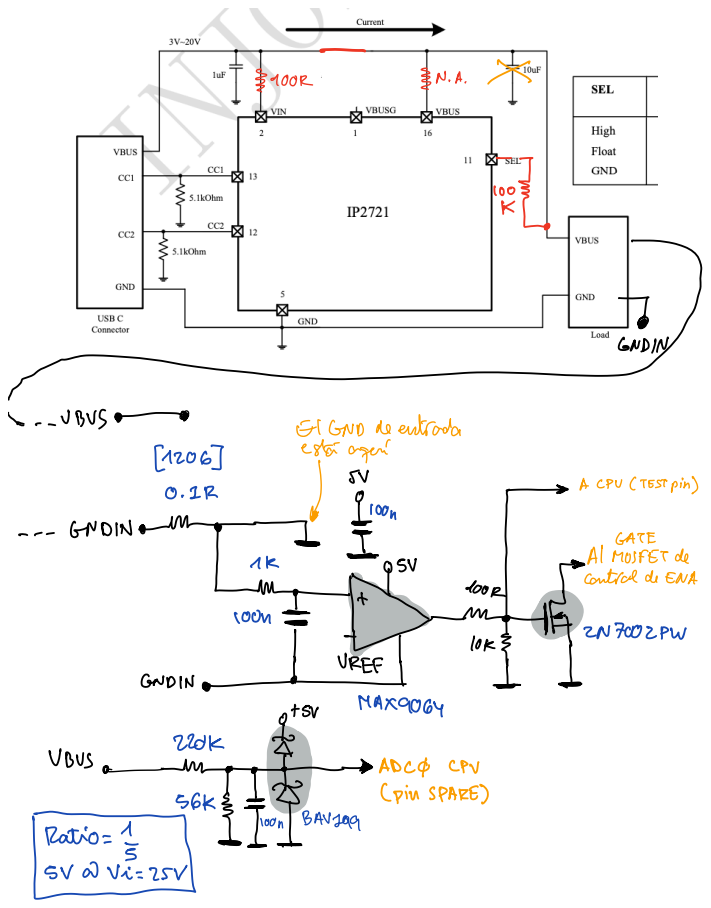
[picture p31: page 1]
estáaquí; BUSTO; A Cpu TESTPin; III; AIMIÉÉde; f controldeENA; jfjj.fi; pinSPARE

mowing
MiÜptFrazoorew
Stigma Arca Civ
zyj

ánimo | YI
ü | µ

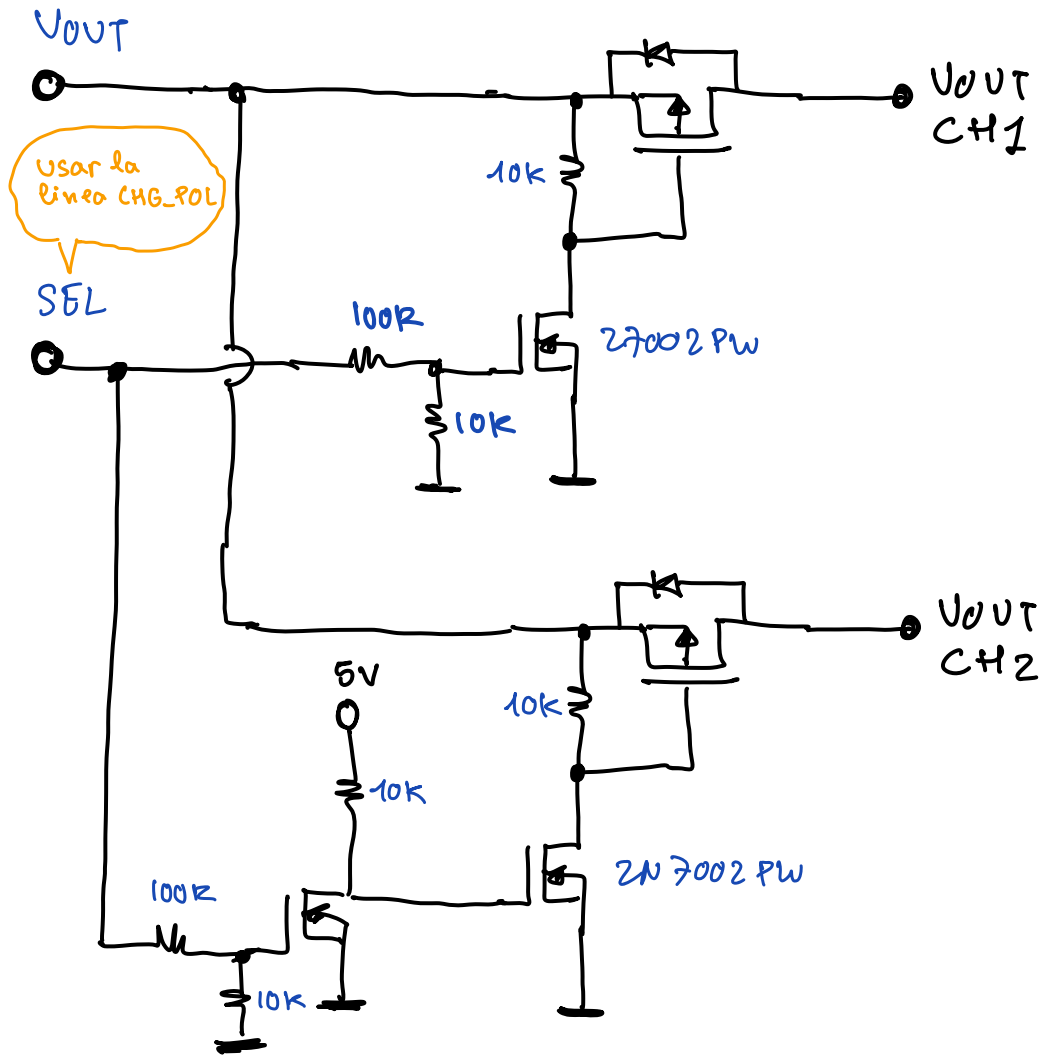
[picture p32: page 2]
ánimo azora; K 1 tewtf; Jjj; azora

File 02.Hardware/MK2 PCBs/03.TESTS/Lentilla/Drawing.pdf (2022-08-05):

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

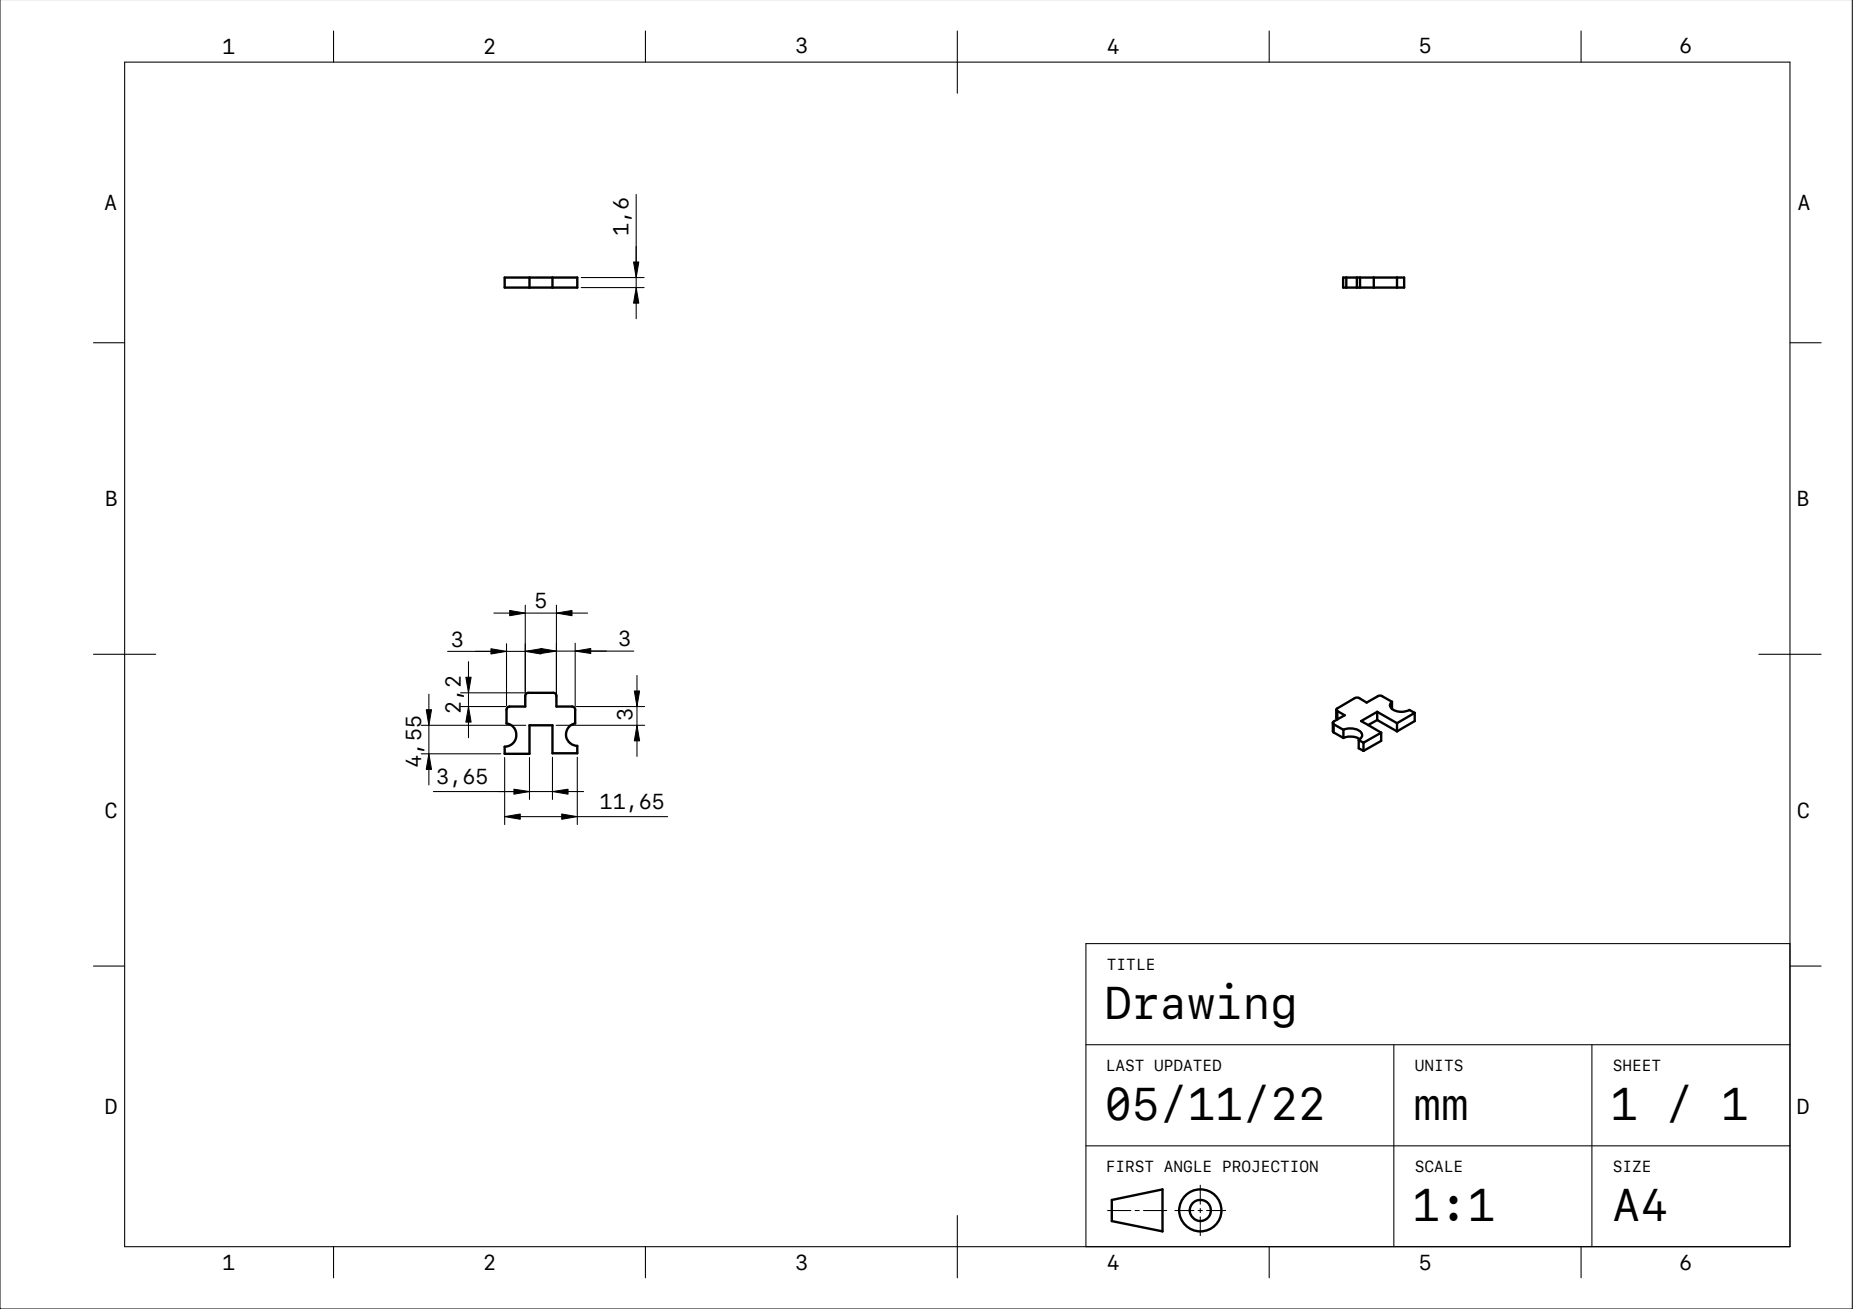
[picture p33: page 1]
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

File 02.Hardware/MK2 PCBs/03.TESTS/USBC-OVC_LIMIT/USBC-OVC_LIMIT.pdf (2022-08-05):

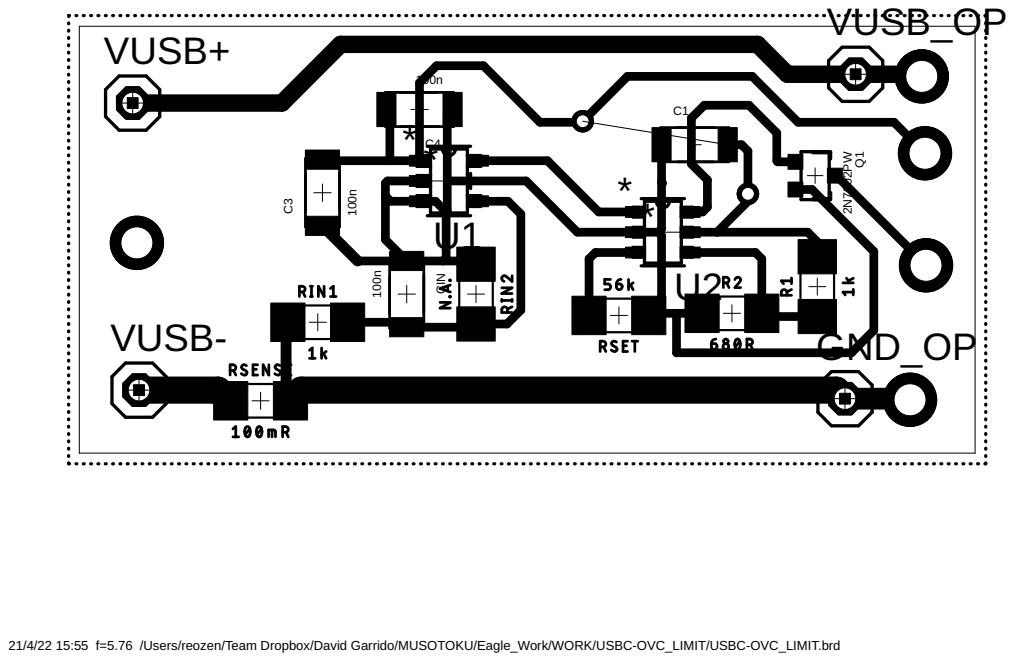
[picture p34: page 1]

21/4/22 15:55 f=5.76 /Users/reozen/Team Dropbox/David Garrido/MUSOTOKU/Eagle_Work/WORK/USBC-OVC_LIMIT/USBC-OVC_LIMIT.brd

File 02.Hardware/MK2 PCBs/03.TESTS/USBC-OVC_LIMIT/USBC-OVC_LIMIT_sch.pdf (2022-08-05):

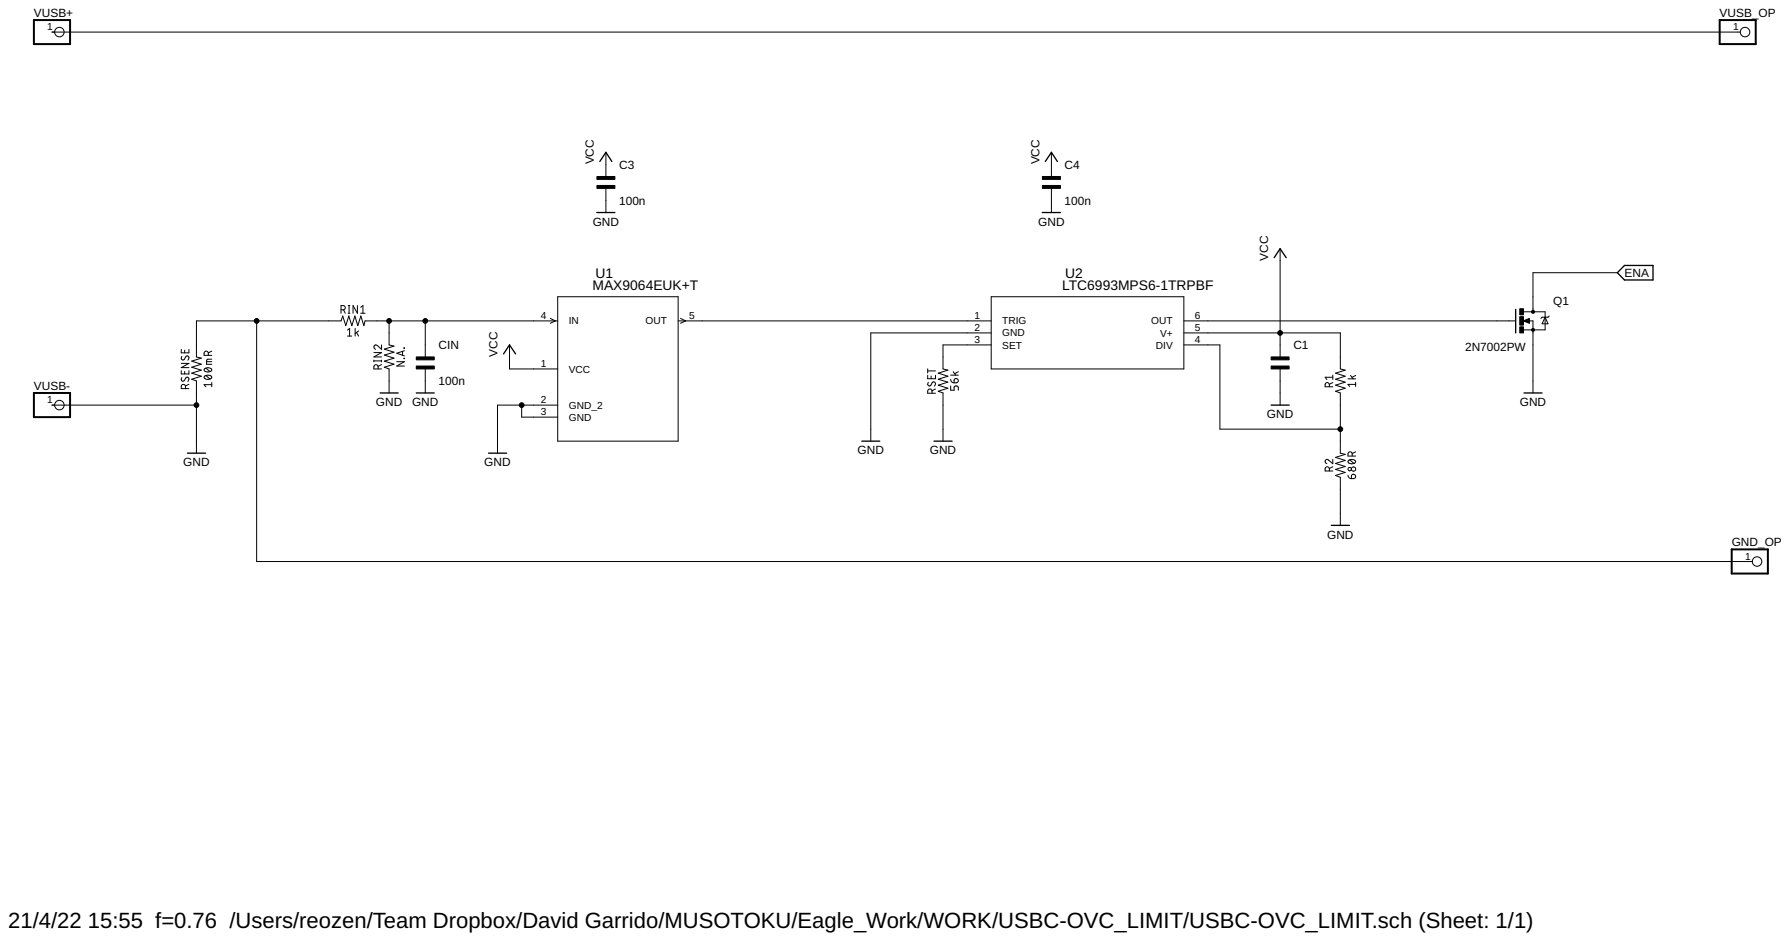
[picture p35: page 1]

21/4/22 15:55 f=0.76 /Users/reozen/Team Dropbox/David Garrido/MUSOTOKU/Eagle_Work/WORK/USBC-OVC_LIMIT/USBC-OVC_LIMIT.sch (Sheet: 1/1)

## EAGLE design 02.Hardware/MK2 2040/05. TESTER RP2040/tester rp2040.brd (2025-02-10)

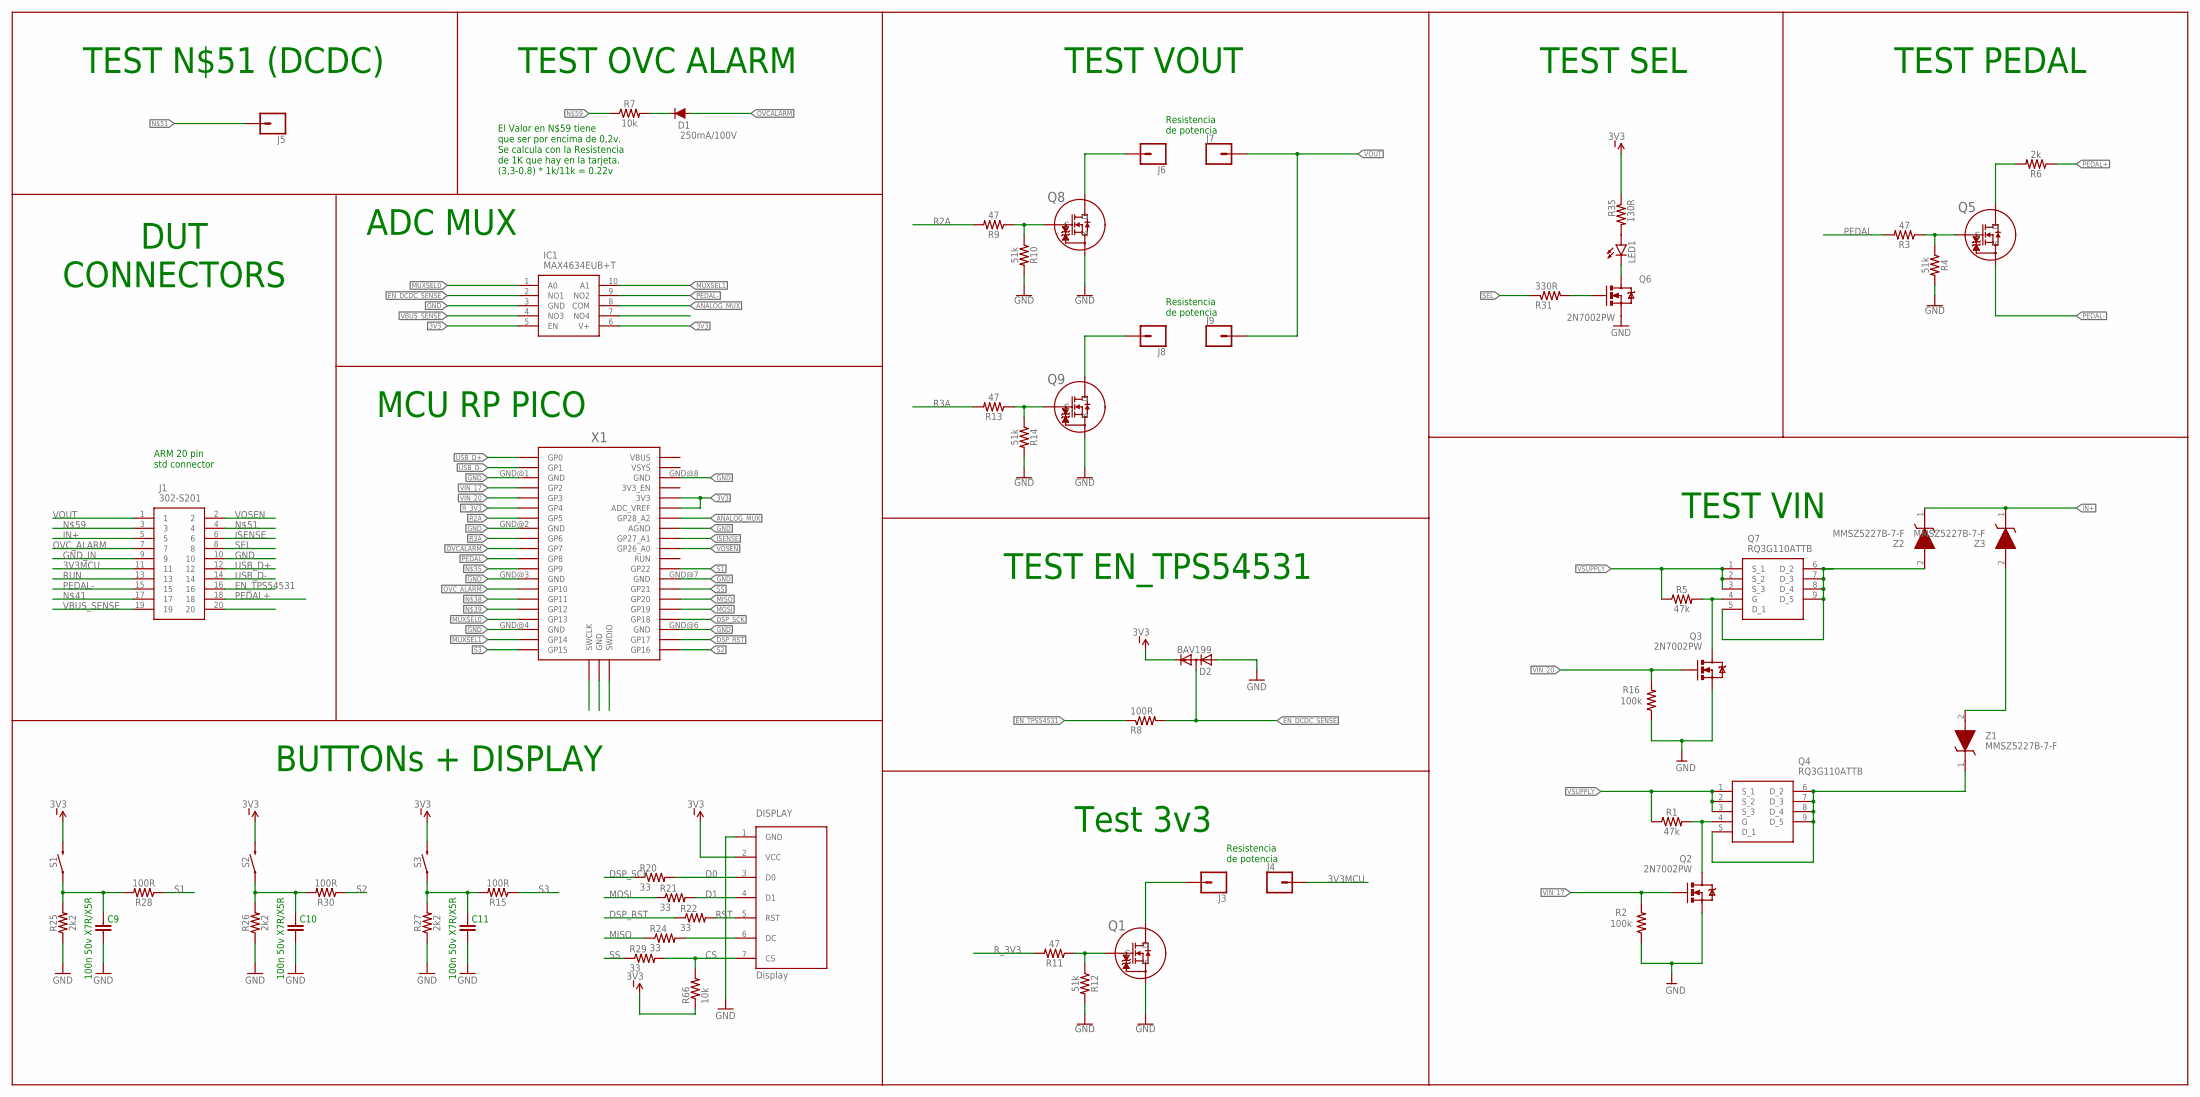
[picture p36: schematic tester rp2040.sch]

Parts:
C9, C10, C11: 100n 50v X7R/X5R; 0805
D1: 250mA/100V; SOD-323
D2: BAV199; SOT23
DISPLAY: Display; OLED_LCD
IC1: MAX4634EUB+T; SOP50P490X110-10N
J1: 302-S201; SHDR20W66P254_2X10_3300X905X90
J3, J4, J5, J6, J7, J8, J9: CONN_01; 1X01
LED1: LED3MM
Q1, Q5, Q8, Q9: PJA3416AE_R1_00001; SOT23_PJA3416_PNJ
Q2, Q3, Q6: 2N7002PW; SOT323
Q4, Q7: RQ3G110ATTB
R1, R5: 47k; 0402
R2, R16: 100k; 0402
R3, R9, R11, R13: 47; 0805
R4, R10, R12, R14: 51k; 0805
R6: 2k; 0805
R7, R66: 10k; 0805
R8, R15, R28, R30: 100R; 0805
R20, R21, R22, R24, R29: 33; 0805
R25, R26, R27: 2k2; 0805
R31: 330R; 0805
R35: 130R; 0805
S1, S2, S3: MOMENTARY-SWITCH-SPST-SMD-5.2MM; TACTILE_SWITCH_SMD_5.2MM
X1: RPI_PICO_IG-TH; RPI_PICO_TH
Z1, Z2, Z3: MMSZ5227B-7-F; SOD3716X135N

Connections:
3V3: D2.2 (C), DISPLAY.2 (VCC), IC1.5 (EN), IC1.6 (V+), R35.1, R66.1, S1.3 (2), S2.3 (2), S3.3 (2), X1.3V3, X1.ADC_VREF
3V3MCU: J1.11, J4.1
ANALOG_MUX: IC1.8 (COM), X1.GP28_A2
CS: DISPLAY.7 (CS), R29.2, R66.2
D0: DISPLAY.3 (D0), R20.2
D1: DISPLAY.4 (D1), R21.2
DSP_RST: R22.1, X1.GP17
DSP_SCK: R20.1, X1.GP18
EN_DCDC_SENSE: D2.3 (AC), IC1.2 (NO1), R8.2
EN_TPS54531: J1.16, R8.1
GND: C9.1, C10.1, C11.1, D2.1 (A), DISPLAY.1 (GND), IC1.3 (GND), J1.10, Q1.2 (S), Q2.2 (S), Q3.2 (S), Q6.2 (S), Q8.2 (S), Q9.2 (S), R2.1, R4.2, R10.2, R12.2, R14.2, R16.1, R25.1, R26.1, R27.1, X1.AGND, X1.GND@1 (GND), X1.GND@2 (GND), X1.GND@3 (GND), X1.GND@4 (GND), X1.GND@6 (GND), X1.GND@7 (GND), X1.GND@8 (GND)
GND_IN: J1.9
IN+: J1.5, Q7.5 (D_1), Q7.6 (D_2), Q7.7 (D_3), Q7.8 (D_4), Q7.9 (D_5), Z2.1 (K), Z2.2 (A), Z3.1 (K)
ISENSE: J1.6, X1.GP27_A1
MISO: R24.1, X1.GP20
MOSI: R21.1, X1.GP19
MUXSEL0: IC1.1 (A0), X1.GP13
MUXSEL1: IC1.10 (A1), X1.GP14
unnamed: J3.1, Q1.3 (D)
unnamed: Z1.2 (A), Z3.2 (A)
unnamed: Q3.3 (D), Q7.4 (G), R5.2
unnamed: D1.C, R7.2
unnamed: Q2.3 (D), Q4.4 (G), R1.2
unnamed: DISPLAY.6 (DC), R24.2
unnamed: Q5.1 (G), R3.1, R4.1
unnamed: Q4.5 (D_1), Q4.6 (D_2), Q4.7 (D_3), Q4.8 (D_4), Q4.9 (D_5), Z1.1 (K)
unnamed: Q1.1 (G), R11.1, R12.1
unnamed: Q5.3 (D), R6.2
unnamed: Q6.1 (G), R31.2
unnamed: LED1.A, R35.2
unnamed: LED1.K (C), Q6.3 (D)
unnamed: Q8.1 (G), R9.1, R10.1
unnamed: J6.1, Q8.3 (D)
unnamed: Q9.1 (G), R13.1, R14.1
unnamed: J8.1, Q9.3 (D)
unnamed: C9.2, R25.2, R28.2, S1.1
unnamed: C10.2, R26.2, R30.2, S2.1
unnamed: J1.4, J5.1
unnamed: C11.2, R15.2, R27.2, S3.1
unnamed: J1.3, R7.1
OVCALARM: D1.A, X1.GP7
OVC_ALARM: J1.7, X1.GP10
PEDAL: R3.2, X1.GP8
PEDAL+: J1.18, R6.1
PEDAL-: IC1.9 (NO2), J1.15, Q5.2 (S)
R2A: R9.2, X1.GP5
R3A: R13.2, X1.GP6
RST: DISPLAY.5 (RST), R22.2
RUN: J1.13
R_3V3: R11.2, X1.GP4
S1: R28.1, X1.GP22
S2: R30.1, X1.GP16
S3: R15.1, X1.GP15
SEL: J1.8, R31.1
SS: R29.1, X1.GP21
USB_D+: J1.12, X1.GP0
USB_D-: J1.14, X1.GP1
VBUS_SENSE: IC1.4 (NO3), J1.19
VIN_17: Q2.1 (G), R2.2, X1.GP2
VIN_20: Q3.1 (G), R16.2, X1.GP3
VOSEN: J1.2, X1.GP26_A0
VOUT: J1.1, J7.1, J9.1
VSUPPLY: Q4.1 (S_1), Q4.2 (S_2), Q4.3 (S_3), Q7.1 (S_1), Q7.2 (S_2), Q7.3 (S_3), R1.1, R5.1

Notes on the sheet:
ARM 20 pin std connector
Resistencia de potencia
Test 3v3
TEST VIN
TEST PEDAL
TEST OVC ALARM
TEST N$51 (DCDC)
TEST SEL
TEST EN_TPS54531
TEST VOUT
ADC MUX
MCU RP PICO
DUT CONNECTORS
BUTTONs + DISPLAY
El Valor en N$59 tiene que ser por encima de 0,2v. Se calcula con la Resistencia de 1K que hay en la tarjeta. (3,3-0.8) * 1k/11k = 0.22v

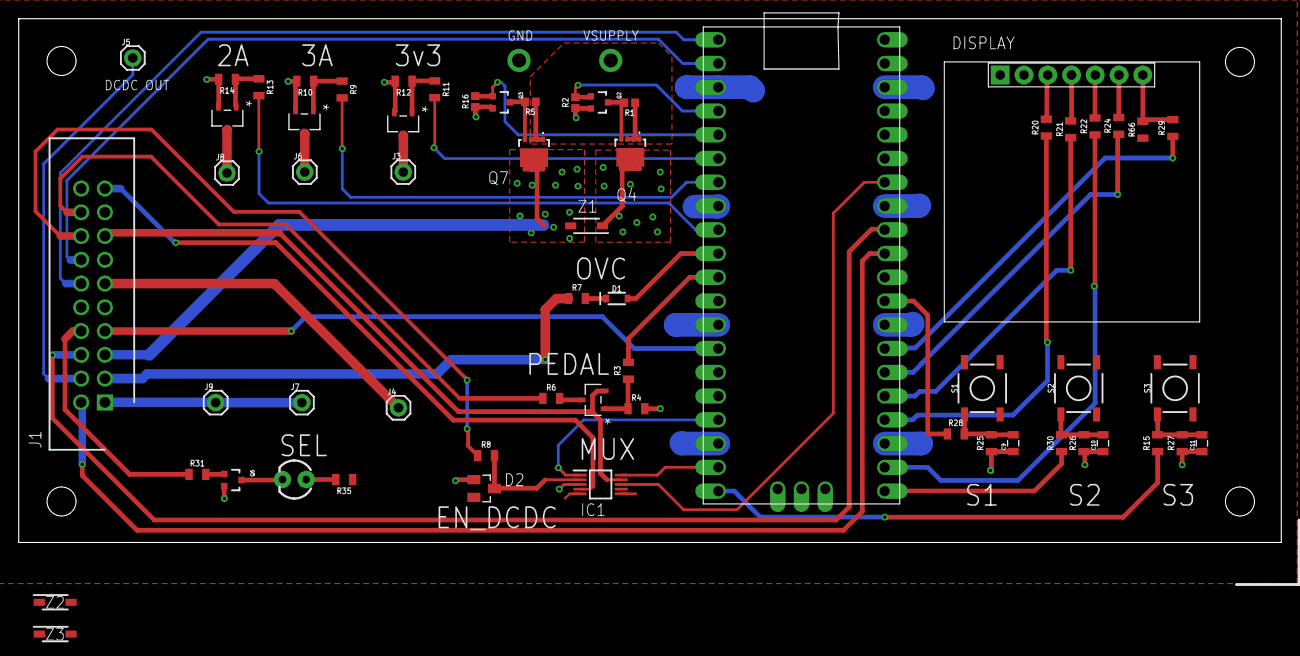
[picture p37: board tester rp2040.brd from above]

Board: 2 copper layers, 135.0 x 56.0 mm, 61 parts (0 on the bottom side), 61 nets.

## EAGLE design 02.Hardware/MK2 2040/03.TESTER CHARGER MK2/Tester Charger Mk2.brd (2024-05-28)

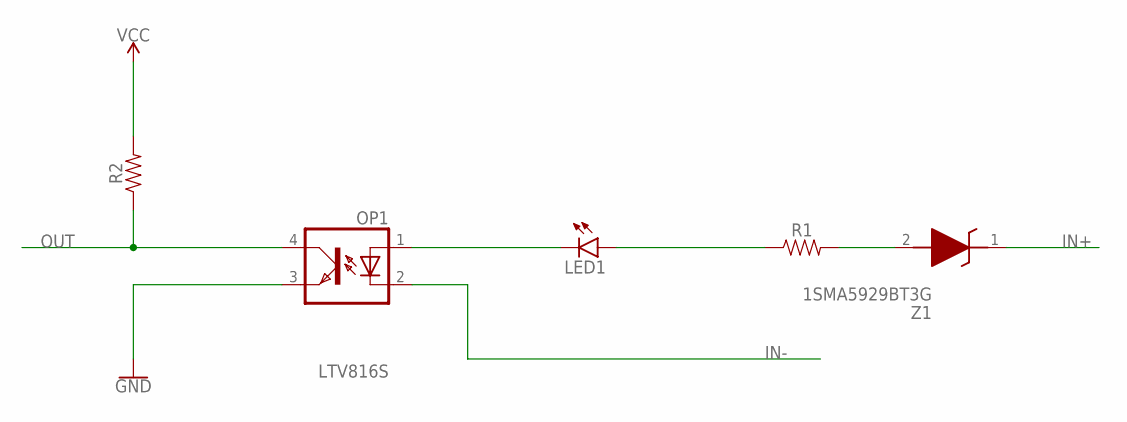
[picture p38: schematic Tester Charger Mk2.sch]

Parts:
LED1: LED3MM
OP1: LTV816S; SMD4
R1, R2: 0805
Z1: 1SMA5929BT3G; DIOM5226X220N

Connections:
GND: OP1.3 (EMIT)
IN+: Z1.1 (K)
IN-: OP1.2 (C)
unnamed: LED1.K (C), OP1.1 (A)
unnamed: R1.2, Z1.2 (A)
unnamed: LED1.A, R1.1
OUT: OP1.4 (COL), R2.1
VCC: R2.2

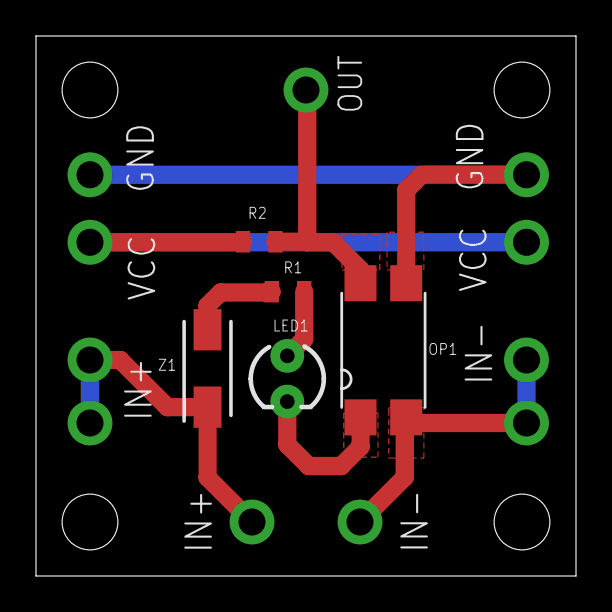
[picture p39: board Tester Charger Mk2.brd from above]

Board: 2 copper layers, 30.0 x 30.0 mm, 5 parts (0 on the bottom side), 4 nets.

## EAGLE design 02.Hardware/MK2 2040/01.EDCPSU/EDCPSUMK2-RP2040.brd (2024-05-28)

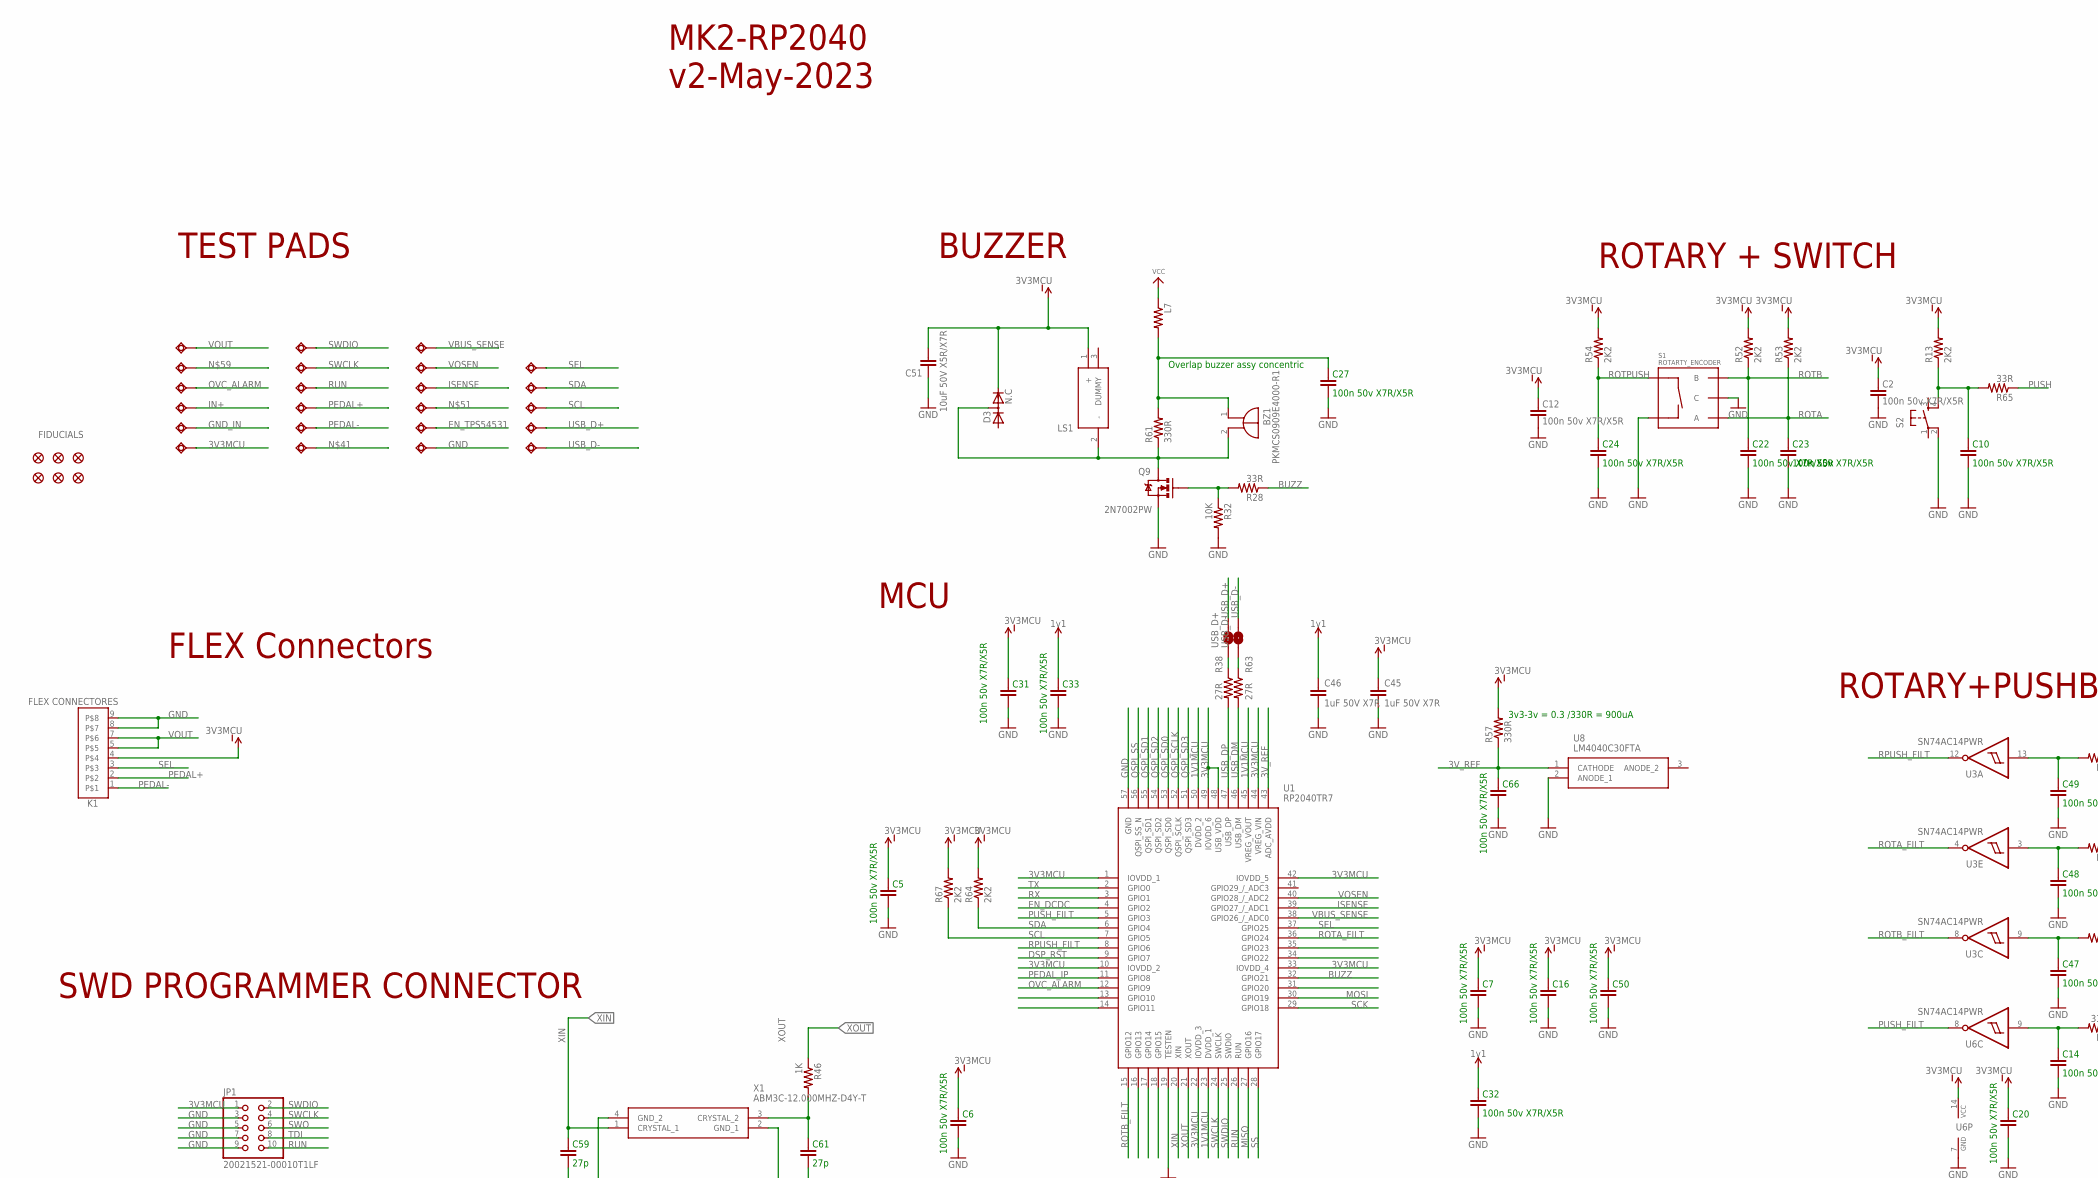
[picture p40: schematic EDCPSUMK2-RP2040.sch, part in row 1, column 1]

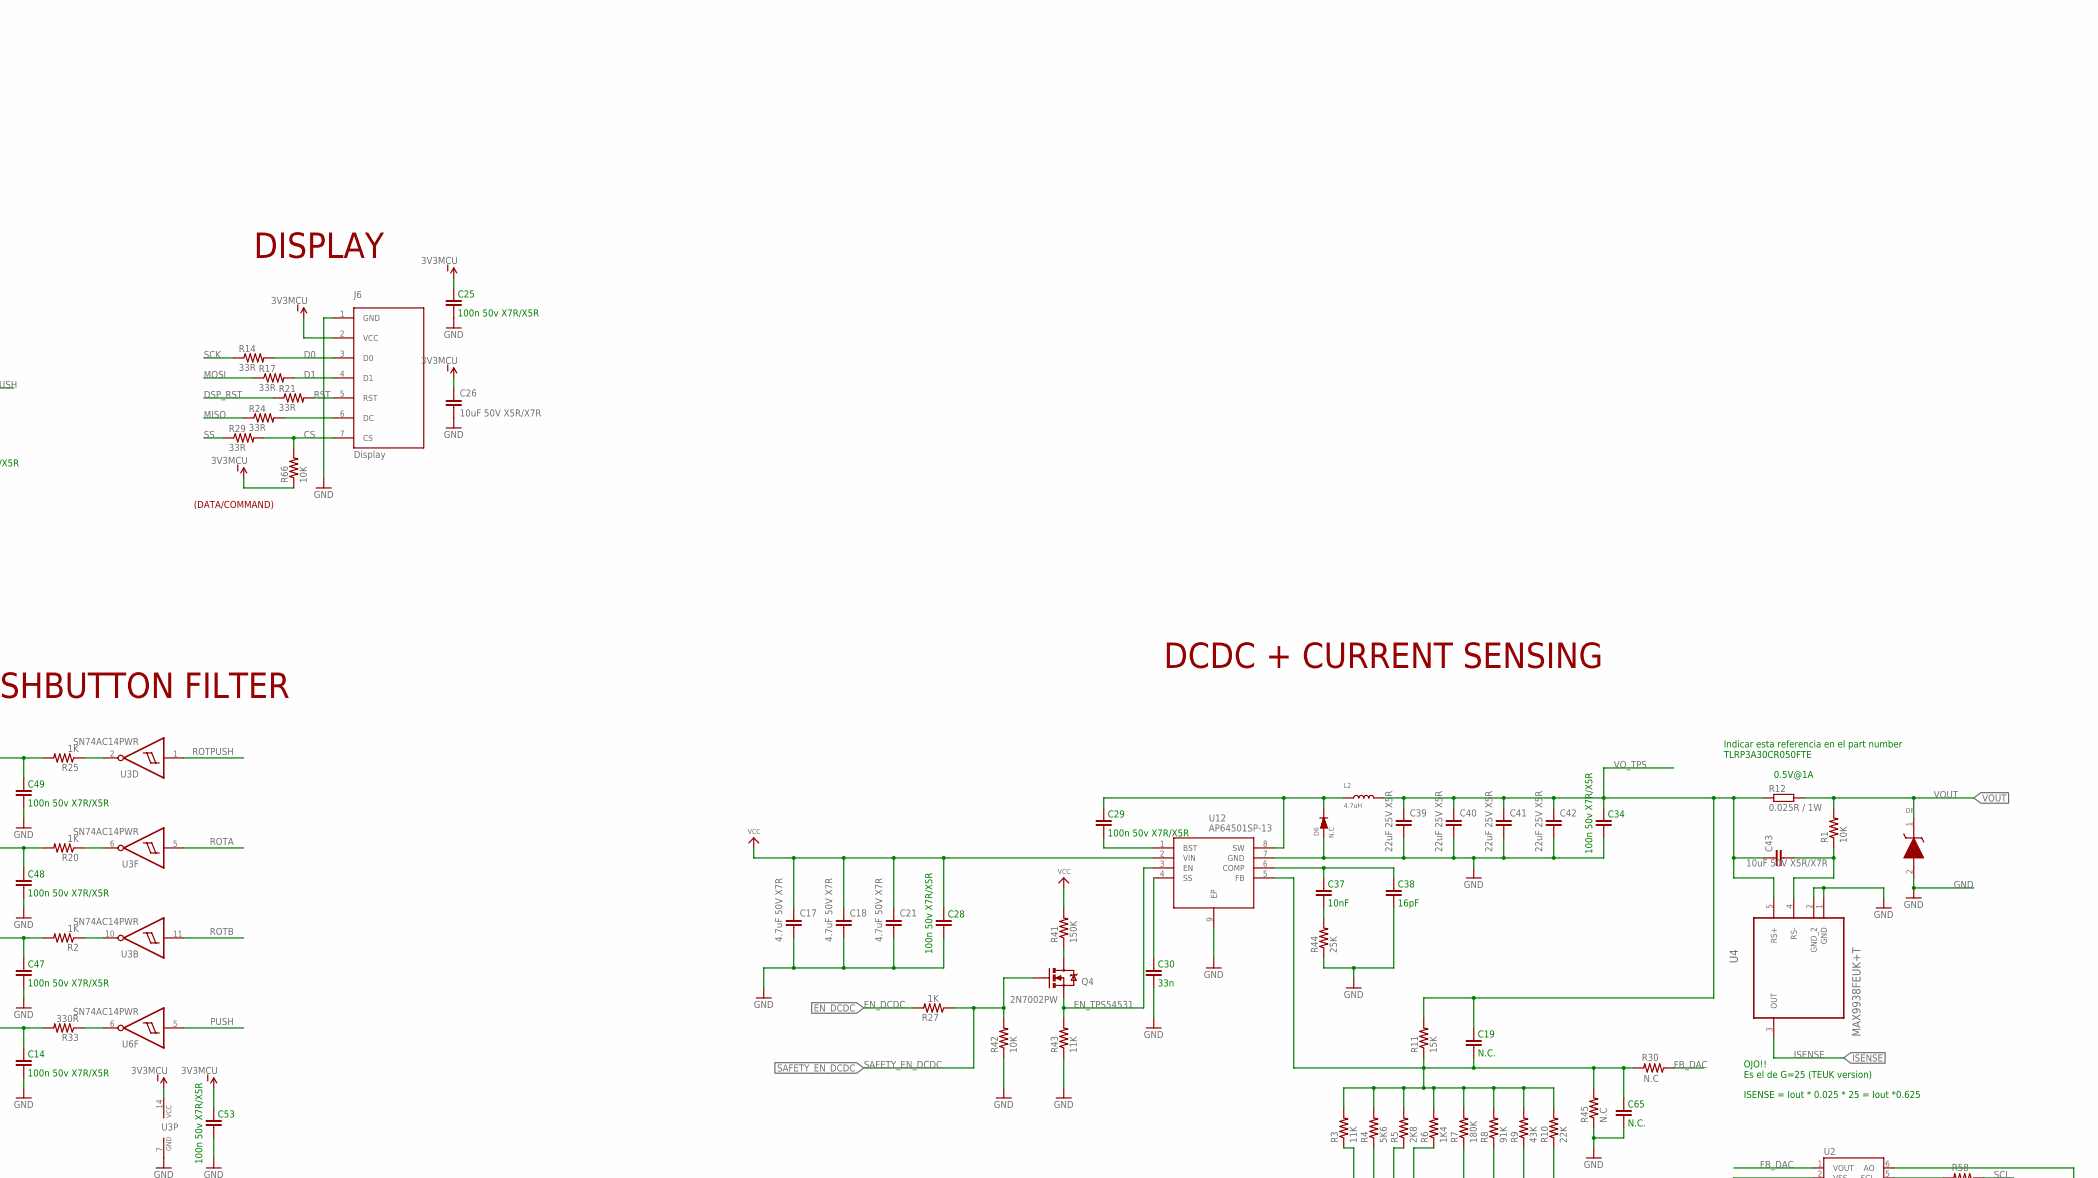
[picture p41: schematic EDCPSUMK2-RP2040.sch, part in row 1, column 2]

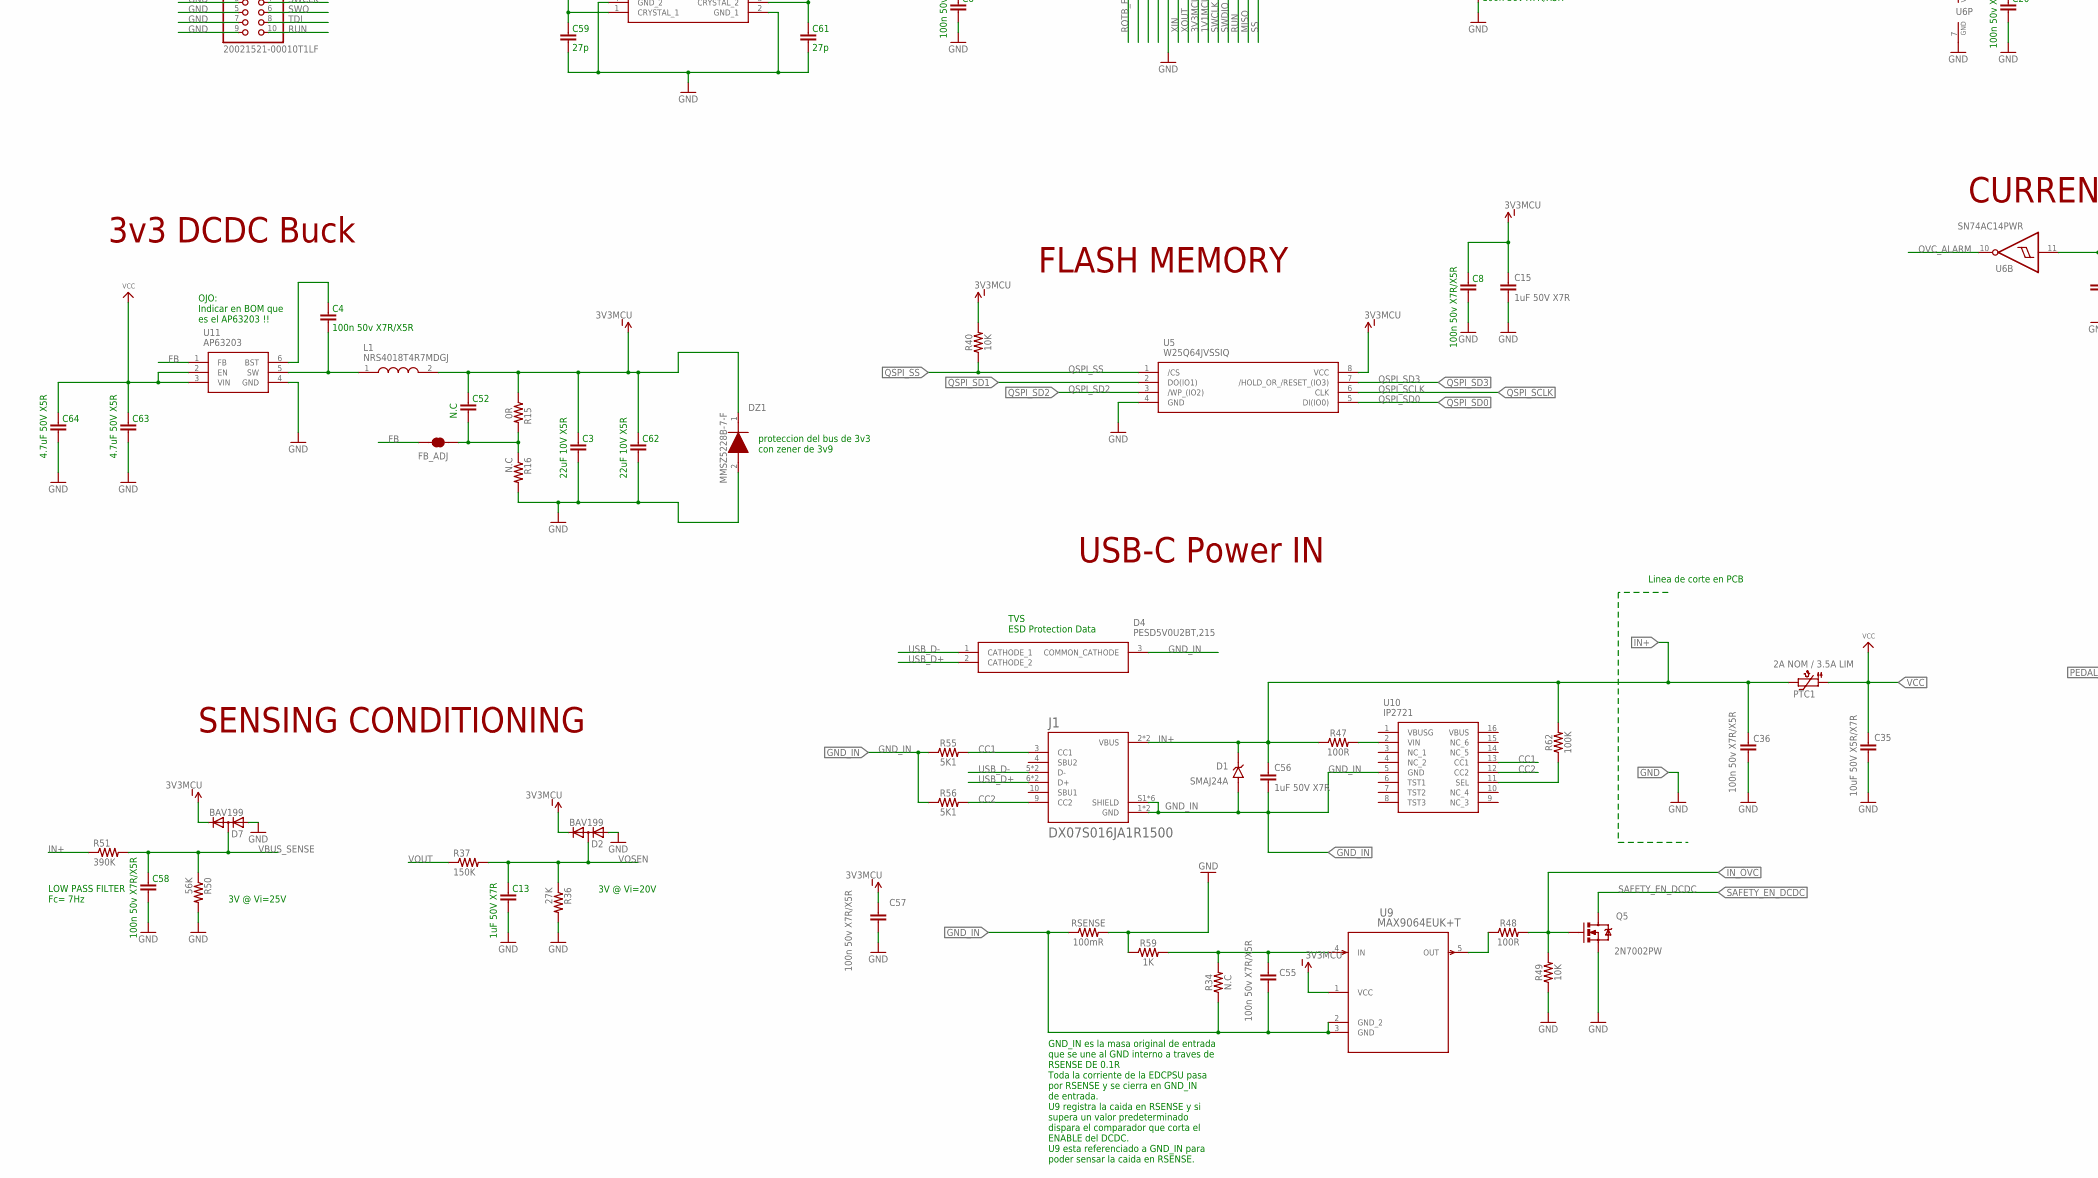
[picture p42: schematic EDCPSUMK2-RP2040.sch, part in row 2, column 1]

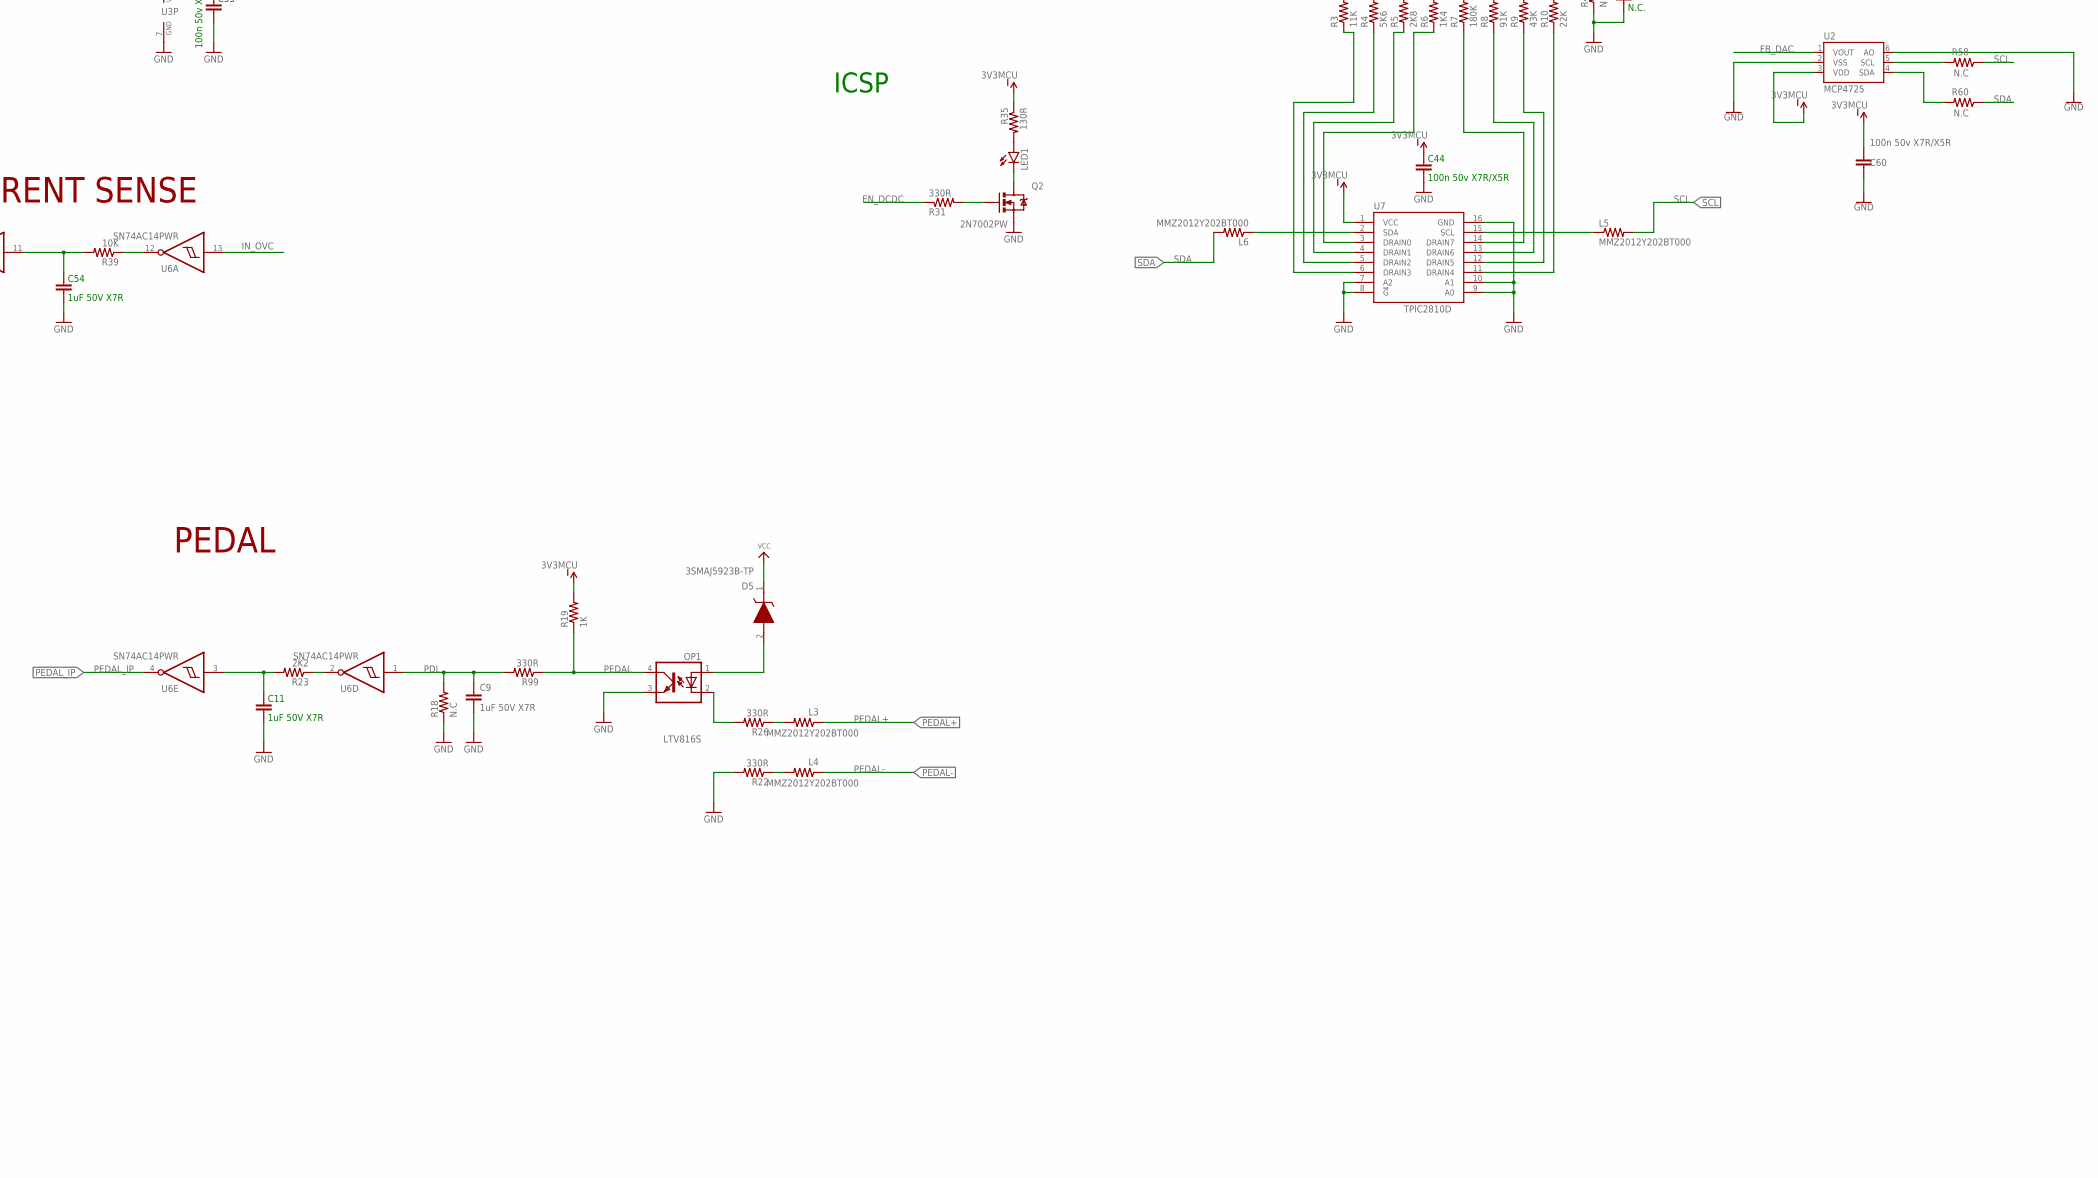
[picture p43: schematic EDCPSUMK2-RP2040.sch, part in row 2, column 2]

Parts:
3V3MCU: TESTPAD_TPSQB1,27; TESTPAD_B1,27
BZ1: PKMCS0909E4000-R1; PKMCS0909
C2, C4, C5, C6, C7, C8, C10, C12, C14, C16, C20, C22, C23, C24, C25, C27, C28, C29, C31, C32, C33, C34, C36, C44, C47, C48, C49, C50, C53, C55, C57, C58, C60, C66: 100n 50v X7R/X5R; 0805
C3, C62: 22uF 10V X5R; 0805
C9, C11, C13, C15, C45, C46, C54, C56: 1uF 50V X7R; 0805
C17, C18, C21: 4.7uF 50V X7R; 1210
C19, C65: N.C.; 0805
C26, C35, C43, C51: 10uF 50V X5R/X7R; 1206
C30: 33n; 0805
C37: 10nF; 0805
C38: 16pF; 0805
C39, C40, C41, C42: 22uF 25V X5R; 1210
C52: N.C; 0805
C59, C61: 27p; 0805
C63, C64: 4.7uF 50V X5R; 0805
D1: SMAJ24A; DIOM4325X244N
D2, D7: BAV199; SOT23
D3: N.C; SOT23
D4: PESD5V0U2BT,215; SOT95P230X110-3N
D5: 3SMAJ5923B-TP; DIOM5226X244N
D6: N.C; DO-214AB
D8: RB060M-60TR; DIOM5226X244N
DZ1: MMSZ5228B-7-F; SODFL3518X115N
EN_TPS54531: TESTPAD_TPSQB1,27; TESTPAD_B1,27
FB_ADJ: JUMPER-SMT_2_NC_TRACE_NO-SILK; SMT-JUMPER_2_NC_TRACE_NO-SILK
FID1, FID2, FID3, FID4, FID5, FID6: FIDUCIAL1X2; FIDUCIAL-1X2
GND: TESTPAD_TPSQB1,27; TESTPAD_B1,27
GND_IN: TESTPAD_TPSQB1,27; TESTPAD_B1,27
IN+: TESTPAD_TPSQB1,27; TESTPAD_B1,27
ISENSE: TESTPAD_TPSQB1,27; TESTPAD_B1,27
J1: DX07S016JA1R1500; JAE_DX07S016JA1R1500
J6: Display; OLED_LCD
JP1: 20021521-00010T1LF
K1: FLEX CONNECTORES; FLEX8
L1: NRS4018T4R7MDGJ; NRS4018T100MDGJ
L2: 4.7uH; WE-LHMI
L3, L4, L5, L6, L7: MMZ2012Y202BT000; 0805
LED1: LED3MM
LS1: SMT-0540-S-R; SMT0540SR
N$41, N$51, N$59: TESTPAD_TPSQB1,27; TESTPAD_B1,27
OP1: LTV816S; SMD4
OVC_ALARM: TESTPAD_TPSQB1,27; TESTPAD_B1,27
PEDAL+: TESTPAD_TPSQB1,27; TESTPAD_B1,27
PEDAL-: TESTPAD_TPSQB1,27; TESTPAD_B1,27
PTC1: 2A NOM / 3.5A LIM; 1812L
Q2, Q4, Q5, Q9: 2N7002PW; SOT323
R1, R32, R39, R40, R42, R49, R66: 10K; 0805
R2, R19, R20, R25, R27, R46, R59: 1K; 0805
R3, R43: 11K; 0805
R4: 5K6; 0805
R5: 2K8; 0805
R6: 1K4; 0805
R7: 180K; 0805
R8: 91K; 0805
R9: 43K; 0805
R10: 22K; 0805
R11: 15K; 0805
R12: 0.025R / 1W; R2512
R13, R23, R52, R53, R54, R64, R67: 2K2; 0805
R14, R17, R21, R24, R28, R29, R65: 33R; 0805
R15: 0R; 0805
R16, R18, R30, R34, R45, R58, R60: N.C; 0805
R22, R26, R31, R33, R57, R61, R99: 330R; 0805
R35: 130R; 0805
R36: 27K; 0805
R37, R41: 150K; 0805
R38, R63: 27R; 0805
R44: 25K; 0805
R47, R48: 100R; 0805
R50: 56K; 0805
R51: 390K; 0805
R55, R56: 5K1; 0805
R62: 100K; 0805
RSENSE: 100mR; 1206
RUN: TESTPAD_TPSQB1,27; TESTPAD_B1,27
S1: ROTARTY_ENCODER; ROTARY_ENC_PLAIN
S2: TAC_SWITCH_KSC931G-SMD; TAC_SW_SMD_KSC931G
SCL: TESTPAD_TPSQB1,27; TESTPAD_B1,27
SDA: TESTPAD_TPSQB1,27; TESTPAD_B1,27
SEL: TESTPAD_TPSQB1,27; TESTPAD_B1,27
SWCLK: TESTPAD_TPSQB1,27; TESTPAD_B1,27
SWDIO: TESTPAD_TPSQB1,27; TESTPAD_B1,27
U1: RP2040TR7
U2: MCP4725; SOT23-6
U3, U6: SN74AC14PWR; TSSOP14
U4: MAX9938FEUK+T; SOT95P280X145-5N
U5: W25Q64JVSSIQ; SOIC127P790X216-8N
U7: TPIC2810D; SO16
U8: LM4040C30FTA; SOT96P240X120-3N
U9: MAX9064EUK+T; 21-0057F_MXM
U10: IP2721; SOP65P640X120-16N
U11: AP63203; SOT95P280X100-6N
U12: AP64501SP-13; SOIC127P600X163-9N
USB-D+: TESTPAD_TPSQB1,27; TESTPAD_B1,27
USB-D-: TESTPAD_TPSQB1,27; TESTPAD_B1,27
USB_D+: JUMPER-SMT_2_NO_NO-SILK; SMT-JUMPER_2_NO_NO-SILK
USB_D-: JUMPER-SMT_2_NO_NO-SILK; SMT-JUMPER_2_NO_NO-SILK
VBUS_SENSE: TESTPAD_TPSQB1,27; TESTPAD_B1,27
VOSEN: TESTPAD_TPSQB1,27; TESTPAD_B1,27
VOUT: TESTPAD_TPSQB1,27; TESTPAD_B1,27
X1: ABM3C-12.000MHZ-D4Y-T; ABM3C16000MHZD4YT

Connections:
1V1MCU: C32.2, C33.2, C46.1, U1.23 (DVDD_1), U1.45 (VREG_VOUT), U1.50 (DVDD_2)
3V3MCU: 3V3MCU.TP, C2.2, C3.2, C5.2, C6.2, C7.2, C8.2, C12.2, C15.1, C16.2, C20.2, C25.2, C26.1, C31.2, C44.2, C45.1, C50.2, C51.2, C52.2, C53.2, C57.1, C60.2, C62.2, D2.2 (C), D3.2 (C), D7.2 (C), DZ1.1 (K), J6.2 (VCC), JP1.1, K1.4, L1.2, LS1.1 (+), R13.2, R15.1, R19.2, R35.1, R40.2, R52.2, R53.2, R54.2, R57.2, R64.2, R66.1, R67.2, U1.1 (IOVDD_1), U1.10 (IOVDD_2), U1.22 (IOVDD_3), U1.33 (IOVDD_4), U1.42 (IOVDD_5), U1.44 (VREG_VIN), U1.48 (USB_VDD), U1.49 (IOVDD_6), U2.3 (VDD), U3.14 (VCC), U5.8 (VCC), U6.14 (VCC), U7.1 (VCC), U9.1 (VCC)
3V_REF: C66.2, R57.1, U1.43 (ADC_AVDD), U8.1 (CATHODE)
BUZZ: R28.1, U1.32 (GPIO21)
CC1: J1.3 (CC1), R55.2, U10.13 (CC1)
CC2: J1.9 (CC2), R56.2, U10.12 (CC2)
CS: J6.7 (CS), R29.2, R66.2
D0: J6.3 (D0), R14.2
D1: J6.4 (D1), R17.2
DSP_RST: R21.1, U1.9 (GPIO7)
EN_DCDC: R27.2, R31.1, U1.4 (GPIO2)
EN_TPS54531: EN_TPS54531.TP, Q4.2 (S), R43.2, U12.3 (EN)
FB: FB_ADJ.2, U11.1 (FB)
FB_DAC: R30.1, U2.1 (VOUT)
GND: C2.1, C3.1, C5.1, C6.1, C7.1, C8.1, C9.2, C10.1, C11.1, C12.1, C13.1, C14.1, C15.2, C16.1, C17.2, C18.2, C20.1, C21.2, C22.1, C23.1, C24.1, C25.1, C26.2, C27.1, C28.1, C30.1, C31.1, C32.1, C33.1, C34.1, C35.2, C36.1, C38.1, C39.2, C40.2, C41.2, C42.2, C44.1, C45.2, C46.2, C47.1, C48.1, C49.1, C50.1, C51.1, C53.1, C54.1, C57.2, C58.1, C59.1, C60.1, C61.1, C62.1, C63.1, C64.1, C65.1, C66.1, D2.1 (A), D6.1 (A), D7.1 (A), D8.2 (A), DZ1.2 (A), GND.TP, J6.1 (GND), JP1.3, JP1.5, JP1.7, JP1.9, K1.8, K1.9, OP1.3 (EMIT), Q2.2 (S), Q5.2 (S), Q9.2 (S), R16.2, R18.1, R22.2, R32.2, R36.2, R42.1, R43.1, R44.1, R45.1, R49.1, R50.2, R59.1, RSENSE.2, S1.C, S1.SW-, S2.2, U1.19 (TESTEN), U1.57 (GND), U2.2 (VSS), U2.6 (AO), U3.7 (GND), U4.1 (GND), U4.2 (GND_2), U5.4 (GND), U6.7 (GND), U7.7 (A2), U7.8 (!G), U7.9 (A0), U7.10 (A1), U7.16 (GND), U8.2 (ANODE_1), U11.4 (GND), U12.7 (GND), U12.9 (EP), X1.2 (GND_1), X1.4 (GND_2)
GND_IN: C55.2, C56.2, D1.A, D4.3 (COMMON_CATHODE), GND_IN.TP, J1.1 (GND), J1.12 (GND), J1.S1 (SHIELD), J1.S2 (SHIELD), J1.S3 (SHIELD), J1.S4 (SHIELD), J1.S5 (SHIELD), J1.S6 (SHIELD), R34.1, R55.1, R56.1, RSENSE.1, U9.2 (GND_2), U9.3 (GND), U10.5 (GND)
IN+: C36.2, C56.1, D1.C (K), IN+.TP, J1.2 (VBUS), J1.11 (VBUS), PTC1.2, R47.1, R51.1, R62.2
IN_OVC: Q5.1 (G), R48.2, R49.2, U6.13 (I)
ISENSE: ISENSE.TP, U1.39 (GPIO27_/_ADC1), U4.3 (OUT)
MISO: R24.1, U1.27 (GPIO16)
MOSI: R17.1, U1.30 (GPIO19)
unnamed: R3.1, U7.6 (DRAIN3)
unnamed: R4.1, U7.5 (DRAIN2)
unnamed: R5.1, U7.4 (DRAIN1)
unnamed: R6.1, U7.3 (DRAIN0)
unnamed: R7.1, U7.14 (DRAIN7)
unnamed: J6.6 (DC), R24.2
unnamed: R8.1, U7.13 (DRAIN6)
unnamed: R9.1, U7.12 (DRAIN5)
unnamed: R10.1, U7.11 (DRAIN4)
unnamed: C43.2, R1.1, U4.4 (RS-)
unnamed: LED1.A, R35.2
unnamed: LED1.K (C), Q2.3 (D)
unnamed: R33.1, U6.6 (O)
unnamed: R62.1, U10.11 (SEL)
unnamed: R39.1, U6.12 (O)
unnamed: D5.2 (A), OP1.1 (A)
unnamed: C10.2, R13.1, R65.2, S2.4
unnamed: C47.2, R2.2, U3.9 (I)
unnamed: C19.1, C65.2, R3.2, R4.2, R5.2, R6.2, R7.2, R8.2, R9.2, R10.2, R11.1, R30.2, R45.2, U12.5 (FB)
unnamed: Q9.1 (G), R28.2, R32.1
unnamed: Q2.1 (G), R31.2
unnamed: R2.1, U3.10 (O)
unnamed: R20.1, U3.6 (O)
unnamed: R25.1, U3.2 (O)
unnamed: C49.2, R25.2, U3.13 (I)
unnamed: C48.2, R20.2, U3.3 (I)
unnamed: C11.2, R23.2, U6.3 (I)
unnamed: BZ1.2 (-), D3.3 (AC), LS1.2 (-), Q9.3 (D), R61.1
unnamed: BZ1.1 (+), C27.2, L7.2, R61.2
unnamed: R23.1, U6.2 (O)
unnamed: Q4.3 (D), R41.1
unnamed: C14.2, R33.2, U6.9 (I)
unnamed: C52.1, FB_ADJ.1, R15.2, R16.1
unnamed: C54.2, R39.2, U6.11 (I)
unnamed: L6.1, U7.2 (SDA)
unnamed: N$41.TP, OP1.2 (C), R26.2
unnamed: L3.2, R26.1
unnamed: C30.2, U12.4 (SS)
unnamed: R58.2, U2.5 (SCL)
unnamed: L4.2, R22.1
unnamed: C29.1, U12.1 (BST)
unnamed: R60.2, U2.4 (SDA)
unnamed: R47.2, U10.2 (VIN)
unnamed: C29.2, D6.2 (K), L2.1, N$51.TP, U12.8 (SW)
unnamed: C37.2, C38.2, U12.6 (COMP)
unnamed: C37.1, R44.2
unnamed: L5.1, U7.15 (SCL)
unnamed: C4.2, U11.6 (BST)
unnamed: R48.1, U9.5 (OUT)
unnamed: C55.1, N$59.TP, R34.2, R59.2, U9.4 (IN)
unnamed: C61.2, R46.2, X1.3 (CRYSTAL_2)
unnamed: R38.1, USB_D+.1
unnamed: R63.1, USB_D-.1
unnamed: C4.1, L1.1, U11.5 (SW)
OVC_ALARM: OVC_ALARM.TP, U1.12 (GPIO9), U6.10 (O)
PDL: C9.1, R18.2, R99.2, U6.1 (I)
PEDAL: OP1.4 (COL), R19.1, R99.1
PEDAL+: K1.2, L3.1, PEDAL+.TP
PEDAL-: K1.1, L4.1, PEDAL-.TP
PEDAL_IP: U1.11 (GPIO8), U6.4 (O)
PUSH: R65.1, U6.5 (I)
PUSH_FILT: U1.5 (GPIO3), U6.8 (O)
QSPI_SCLK: U1.52 (QSPI_SCLK), U5.6 (CLK)
QSPI_SD0: U1.53 (QSPI_SD0), U5.5 (DI(IO0))
QSPI_SD1: U1.55 (QSPI_SD1), U5.2 (DO(IO1))
QSPI_SD2: U1.54 (QSPI_SD2), U5.3 (/WP_(IO2))
QSPI_SD3: U1.51 (QSPI_SD3), U5.7 (/HOLD_OR_/RESET_(IO3))
QSPI_SS: R40.1, U1.56 (QSPI_SS_N), U5.1 (/CS)
ROTA: C23.2, R53.1, S1.A, U3.5 (I)
ROTA_FILT: U1.36 (GPIO24), U3.4 (O)
ROTB: C22.2, R52.1, S1.B, U3.11 (I)
ROTB_FILT: U1.15 (GPIO12), U3.8 (O)
ROTPUSH: C24.2, R54.1, S1.SW+, U3.1 (I)
RPUSH_FILT: U1.8 (GPIO6), U3.12 (O)
RST: J6.5 (RST), R21.2
RUN: JP1.10, RUN.TP, U1.26 (RUN)
RX: U1.3 (GPIO1)
SAFETY_EN_DCDC: Q4.1 (G), Q5.3 (D), R27.1, R42.2
SCK: R14.1, U1.29 (GPIO18)
SCL: L5.2, R58.1, R67.1, SCL.TP, U1.7 (GPIO5)
SDA: L6.2, R60.1, R64.1, SDA.TP, U1.6 (GPIO4)
SEL: K1.3, SEL.TP, U1.37 (GPIO25)
SS: R29.1, U1.28 (GPIO17)
SWCLK: JP1.4, SWCLK.TP, U1.24 (SWCLK)
SWDIO: JP1.2, SWDIO.TP, U1.25 (SWDIO)
SWO: JP1.6
TDI: JP1.8
TX: U1.2 (GPIO0)
USB_D+: D4.2 (CATHODE_2), J1.6 (D+), J1.7 (D+), USB-D+.TP, USB_D+.2
USB_D-: D4.1 (CATHODE_1), J1.5 (D-), J1.8 (D-), USB-D-.TP, USB_D-.2
USB_DM: R63.2, U1.46 (USB_DM)
USB_DP: R38.2, U1.47 (USB_DP)
VBUS_SENSE: C58.2, D7.3 (AC), R50.1, R51.2, U1.38 (GPIO26_/_ADC0), VBUS_SENSE.TP
VCC: C17.1, C18.1, C21.1, C28.2, C35.1, C63.2, C64.2, D5.1 (K), L7.1, PTC1.1, R41.2, U11.2 (EN), U11.3 (VIN), U12.2 (VIN)
VOSEN: C13.2, D2.3 (AC), R36.1, R37.2, U1.40 (GPIO28_/_ADC2), VOSEN.TP
VOUT: D8.1 (K), K1.5, K1.7, R1.2, R12.2, R37.1, VOUT.TP
VO_TPS: C19.2, C34.2, C39.1, C40.1, C41.1, C42.1, C43.1, L2.2, R11.2, R12.1, U4.5 (RS+)
XIN: C59.2, U1.20 (XIN), X1.1 (CRYSTAL_1)
XOUT: R46.1, U1.21 (XOUT)

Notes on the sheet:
0.5V@1A
SENSING CONDITIONING
TEST PADS
MK2-RP2040 v2-May-2023
(DATA/COMMAND)
Overlap buzzer assy concentric
ICSP
BUZZER
ROTARY + SWITCH
DISPLAY
FIDUCIALS
OJO!! Es el de G=25 (TEUK version)
ISENSE = Iout * 0.025 * 25 = Iout *0.625
FLEX Connectors
3V @ Vi=25V
LOW PASS FILTER Fc= 7Hz
SWD PROGRAMMER CONNECTOR
3v3 DCDC Buck
OJO: Indicar en BOM que es el AP63203 !!
FLASH MEMORY
USB-C Power IN
PEDAL
CURRENT SENSE
ROTARY+PUSHBUTTON FILTER
DCDC + CURRENT SENSING
MCU
Indicar esta referencia en el part number TLRP3A30CR050FTE
3v3-3v = 0.3 /330R = 900uA
TVS ESD Protection Data
GND_IN es la masa original de entrada que se une al GND interno a traves de RSENSE DE 0.1R Toda la corriente de la EDCPSU pasa por RSENSE y se cierra en GND_IN de entrada. U9 registra la caida en RSENSE y si supera un valor predeterminado dispara el comparador que corta el ENABLE del DCDC. U9 esta 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
proteccion del bus de 3v3 con zener de 3v9
Linea de corte en PCB
3V @ Vi=20V

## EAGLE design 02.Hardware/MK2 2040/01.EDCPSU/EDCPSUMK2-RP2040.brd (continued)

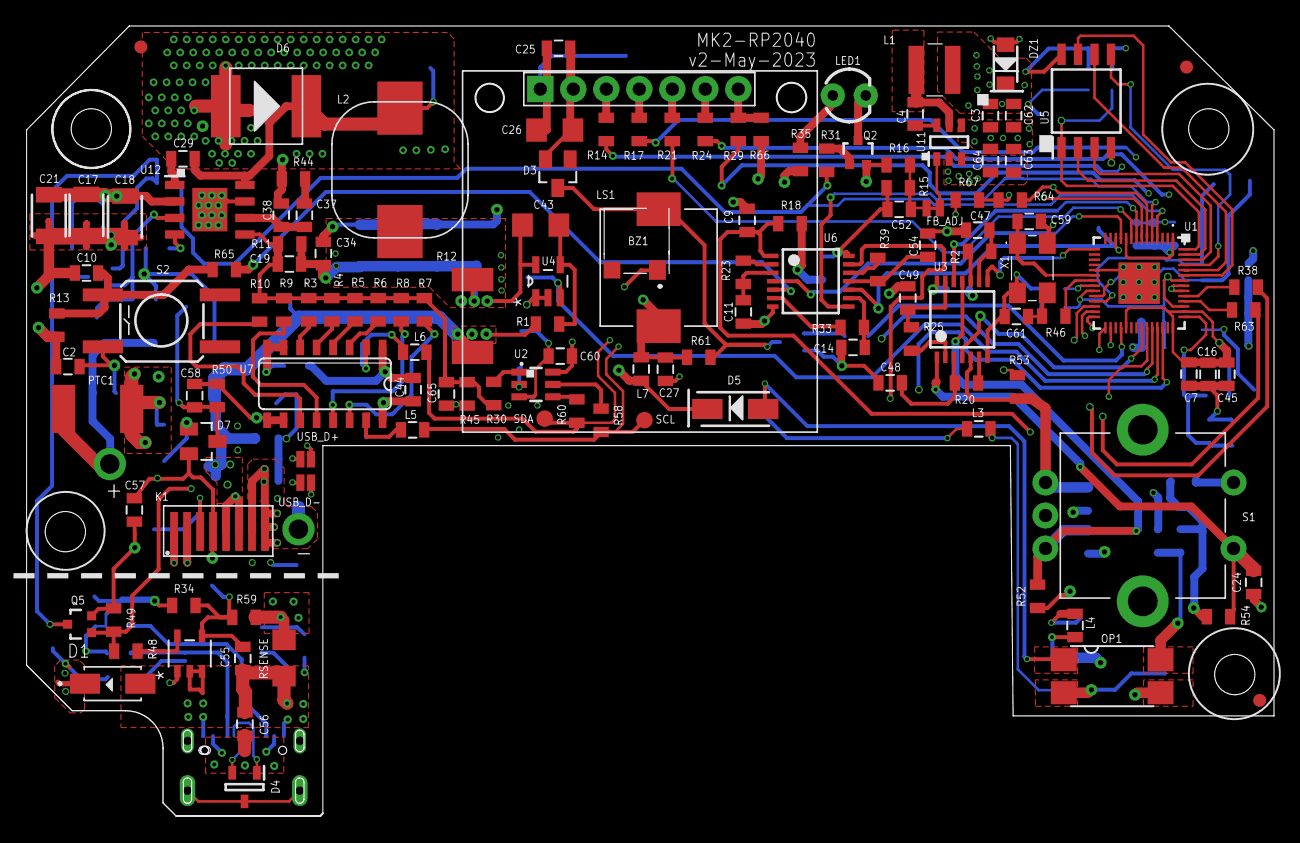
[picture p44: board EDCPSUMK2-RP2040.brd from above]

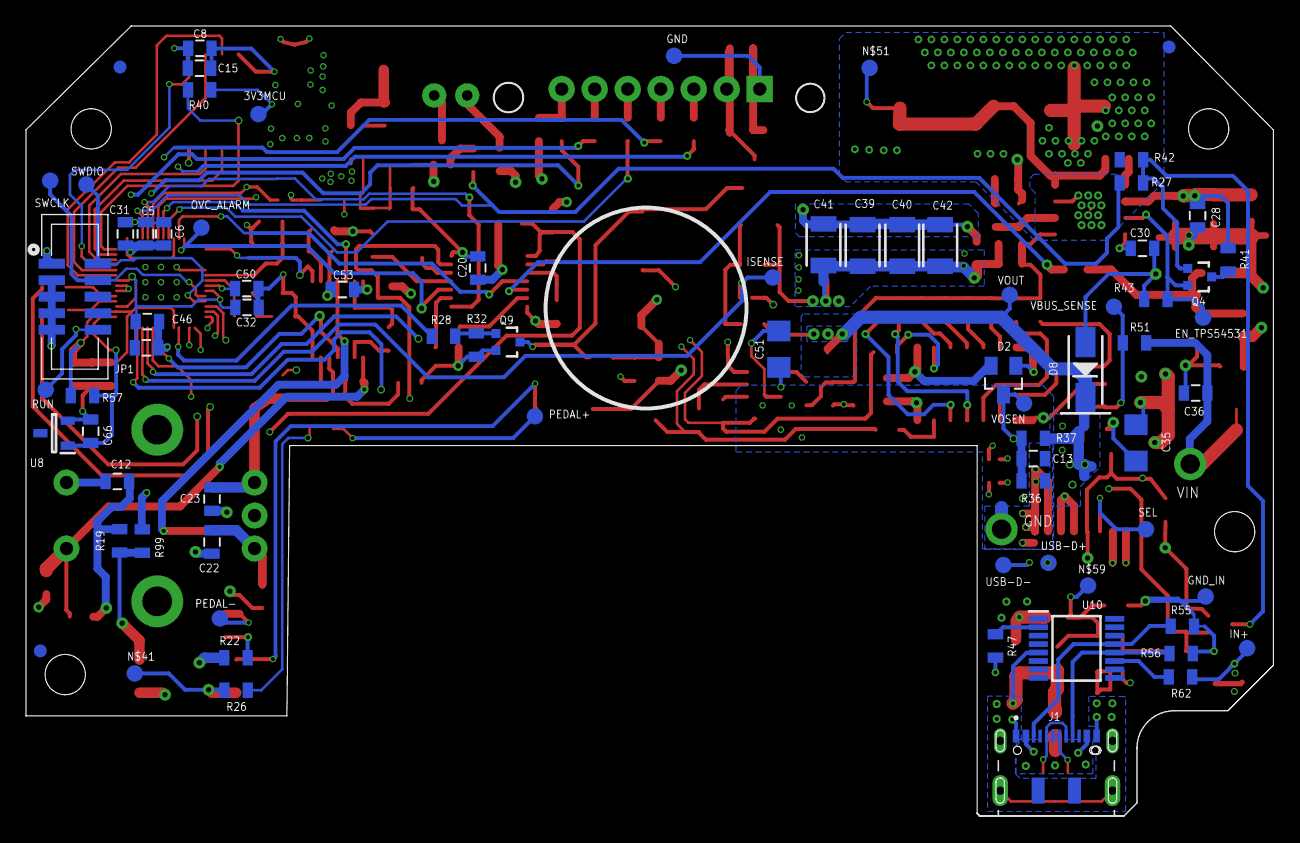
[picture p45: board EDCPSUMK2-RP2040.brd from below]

Board: 4 copper layers, 96.0 x 60.8 mm, 210 parts (76 on the bottom side), 116 nets.

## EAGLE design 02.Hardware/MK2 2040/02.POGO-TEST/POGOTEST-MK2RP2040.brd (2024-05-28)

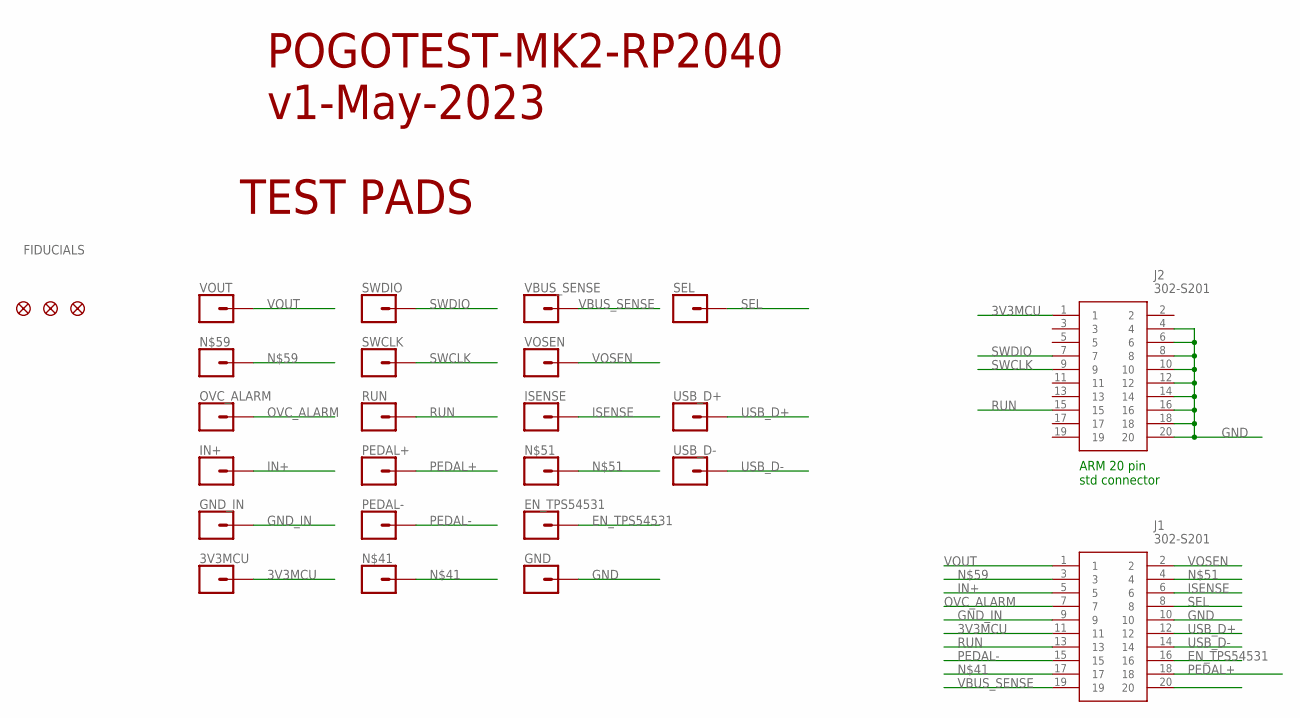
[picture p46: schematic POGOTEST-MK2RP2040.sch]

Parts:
3V3MCU: CONN_01POGOPIN_HOLE_LARGE; 1X01_POGOPIN_HOLE_0.061_DIA
EN_TPS54531: CONN_01POGOPIN_HOLE_LARGE; 1X01_POGOPIN_HOLE_0.061_DIA
FID3, FID5, FID6: FIDUCIAL1X2; FIDUCIAL-1X2
GND: CONN_01POGOPIN_HOLE_LARGE; 1X01_POGOPIN_HOLE_0.061_DIA
GND_IN: CONN_01POGOPIN_HOLE_LARGE; 1X01_POGOPIN_HOLE_0.061_DIA
IN+: CONN_01POGOPIN_HOLE_LARGE; 1X01_POGOPIN_HOLE_0.061_DIA
ISENSE: CONN_01POGOPIN_HOLE_LARGE; 1X01_POGOPIN_HOLE_0.061_DIA
J1, J2: 302-S201; SHDR20W66P254_2X10_3300X905X90
N$41, N$51, N$59: CONN_01POGOPIN_HOLE_LARGE; 1X01_POGOPIN_HOLE_0.061_DIA
OVC_ALARM: CONN_01POGOPIN_HOLE_LARGE; 1X01_POGOPIN_HOLE_0.061_DIA
PEDAL+: CONN_01POGOPIN_HOLE_LARGE; 1X01_POGOPIN_HOLE_0.061_DIA
PEDAL-: CONN_01POGOPIN_HOLE_LARGE; 1X01_POGOPIN_HOLE_0.061_DIA
RUN: CONN_01POGOPIN_HOLE_LARGE; 1X01_POGOPIN_HOLE_0.061_DIA
SEL: CONN_01POGOPIN_HOLE_LARGE; 1X01_POGOPIN_HOLE_0.061_DIA
SWCLK: CONN_01POGOPIN_HOLE_LARGE; 1X01_POGOPIN_HOLE_0.061_DIA
SWDIO: CONN_01POGOPIN_HOLE_LARGE; 1X01_POGOPIN_HOLE_0.061_DIA
USB_D+: CONN_01POGOPIN_HOLE_LARGE; 1X01_POGOPIN_HOLE_0.061_DIA
USB_D-: CONN_01POGOPIN_HOLE_LARGE; 1X01_POGOPIN_HOLE_0.061_DIA
VBUS_SENSE: CONN_01POGOPIN_HOLE_LARGE; 1X01_POGOPIN_HOLE_0.061_DIA
VOSEN: CONN_01POGOPIN_HOLE_LARGE; 1X01_POGOPIN_HOLE_0.061_DIA
VOUT: CONN_01POGOPIN_HOLE_LARGE; 1X01_POGOPIN_HOLE_0.061_DIA

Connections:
3V3MCU: 3V3MCU.2, J1.11, J2.1
EN_TPS54531: EN_TPS54531.2, J1.16
GND: GND.2, J1.10, J2.4, J2.6, J2.8, J2.10, J2.12, J2.14, J2.16, J2.18, J2.20
GND_IN: GND_IN.2, J1.9
IN+: IN+.2, J1.5
ISENSE: ISENSE.2, J1.6
unnamed: J1.17, N$41.2
unnamed: J1.4, N$51.2
unnamed: J1.3, N$59.2
OVC_ALARM: J1.7, OVC_ALARM.2
PEDAL+: J1.18, PEDAL+.2
PEDAL-: J1.15, PEDAL-.2
RUN: J1.13, J2.15, RUN.2
SEL: J1.8, SEL.2
SWCLK: J2.9, SWCLK.2
SWDIO: J2.7, SWDIO.2
USB_D+: J1.12, USB_D+.2
USB_D-: J1.14, USB_D-.2
VBUS_SENSE: J1.19, VBUS_SENSE.2
VOSEN: J1.2, VOSEN.2
VOUT: J1.1, VOUT.2

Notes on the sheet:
TEST PADS
POGOTEST-MK2-RP2040 v1-May-2023
FIDUCIALS
ARM 20 pin std connector

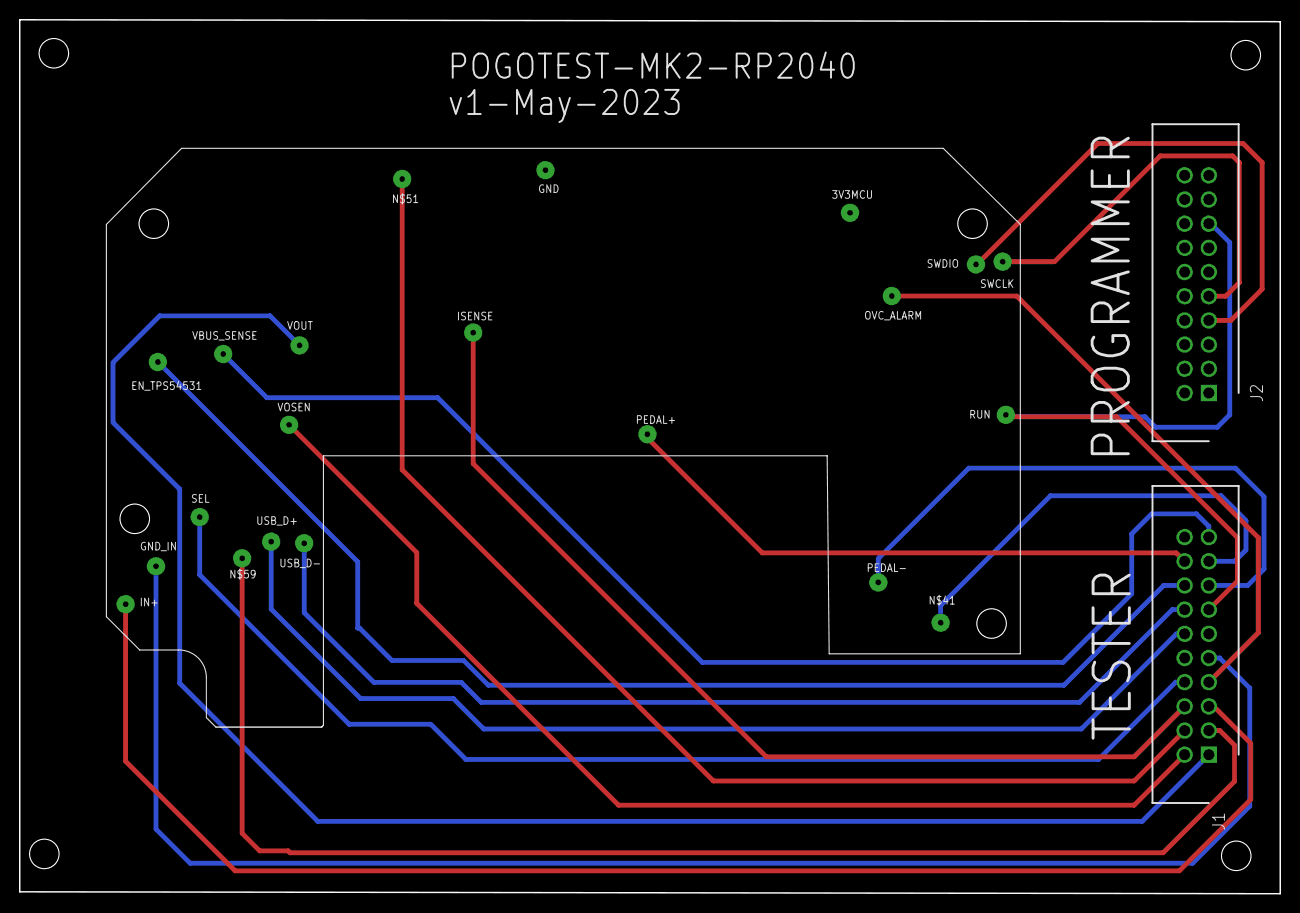
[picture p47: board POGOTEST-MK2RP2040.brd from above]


Board: 2 copper layers, 132.4 x 91.8 mm, 26 parts (3 on the bottom side), 21 nets.

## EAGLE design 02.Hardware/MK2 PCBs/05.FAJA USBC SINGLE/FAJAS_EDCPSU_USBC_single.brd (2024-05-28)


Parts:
K1, K2, K4, K5: FLEX_MK2; FLEX8

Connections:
GND: K1.7, K1.8, K2.7, K2.8, K4.7, K4.8, K5.7, K5.8
P+: K1.2, K2.2, K4.2, K5.2
P-: K1.1, K2.1, K4.1, K5.1
SEL: K1.3, K2.3, K4.3, K5.3
VCC: K1.4, K2.4, K4.4, K5.4
VOUT: K1.5, K1.6, K2.5, K2.6, K4.5, K4.6, K5.5, K5.6

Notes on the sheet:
FAJA_USB-C SINGLE v1-Feb23
EDCPSU <--> CONECTOREs



Board: 2 copper layers, 11.1 x 35.5 mm, 4 parts (2 on the bottom side), 6 nets.

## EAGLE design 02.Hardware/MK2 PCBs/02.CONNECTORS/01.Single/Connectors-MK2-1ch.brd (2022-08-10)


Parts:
K1: FLEX8
MACHINE3, MACHINE4: ACJS-MHDR; CONN_MHDR_AMP

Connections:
GND: K1.8, K1.9, MACHINE3.1, MACHINE3.4, MACHINE3.5
P+: K1.2, MACHINE4.6
P-: K1.1, MACHINE4.1, MACHINE4.4, MACHINE4.5
SEL: K1.3
VCC: K1.4
VOUT: K1.5, K1.7, MACHINE3.6



Board: 2 copper layers, 59.5 x 28.5 mm, 3 parts (2 on the bottom side), 4 nets.

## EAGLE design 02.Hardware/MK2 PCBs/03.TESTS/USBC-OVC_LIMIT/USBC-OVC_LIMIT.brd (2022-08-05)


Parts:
C1, C3, C4: 100n; WCAP-CSGP_1206
CIN: 100n; WCAP-CSGP_1206
GND_OP: PINHD-1X1; 1X01
Q1: 2N7002PW; SOT323
R1: 1k; 1206
R2: 680R; 1206
RIN1: 1k; 1206
RIN2: N.A.; 1206
RSENSE: 100mR; 1206
RSET: 56k; 1206
U1: MAX9064EUK+T; 21-0057F_MXM
U2: LTC6993MPS6-1TRPBF; TSOT-23_S6_LIT
VUSB+: PINHD-1X1; 1X01
VUSB-: PINHD-1X1; 1X01
VUSB_OP: PINHD-1X1; 1X01

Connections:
ENA: Q1.3 (D)
GND: C1.1, C3.1, C4.1, CIN.1, Q1.2 (S), R2.1, RIN2.1, RSENSE.1, RSET.1, U1.2 (GND_2), U1.3 (GND), U2.2 (GND), VUSB-.1
GND_OP: GND_OP.1, RIN1.1, RSENSE.2
unnamed: RSET.2, U2.3 (SET)
unnamed: CIN.2, RIN1.2, RIN2.2, U1.4 (IN)
unnamed: R1.1, R2.2, U2.4 (DIV)
unnamed: Q1.1 (G), U2.6 (OUT)
unnamed: U1.5 (OUT), U2.1 (TRIG)
VCC: C1.2, C3.2, C4.2, R1.2, U1.1 (VCC), U2.5 (V+)
VUSB_OP: VUSB+.1, VUSB_OP.1


Board: 2 copper layers, 42.0 x 20.0 mm, 17 parts (0 on the bottom side), 9 nets.

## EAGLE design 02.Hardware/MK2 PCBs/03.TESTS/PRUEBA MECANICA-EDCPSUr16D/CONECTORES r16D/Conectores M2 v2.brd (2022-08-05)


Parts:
LED1, LED2: APA3010SRCPRV-GX; LED_APA3010SRCPRV-GX_KNB
MACHINE1, MACHINE2: ACJS-MHDR; CONN_MHDR_AMP
PEDAL: ACJS-MHDR; CONN_MHDR_AMP
R1, R2: 0805

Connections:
GND: LED1.1, LED2.1
LED1: R1.1
LED2: R2.1
unnamed: LED2.2, R2.2
unnamed: LED1.2, R1.2



Board: 2 copper layers, 62.1 x 28.0 mm, 7 parts (3 on the bottom side), 3 nets.

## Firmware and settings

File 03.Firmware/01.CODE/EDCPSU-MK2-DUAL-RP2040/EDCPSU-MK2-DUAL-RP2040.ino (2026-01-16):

//******************************
//   VERSION M2-805
//*****************************
#define VERSION 806
/**************************************************
*******************
EDCPSU Tattoo edition HW USB-C M2
This version is an evolution of the 730 (M1 dual)
10 AGO 2023
IDE Version: 1.8.13
VERSION: see above

CAMBIOS : En esta version se cierra el Issue #1 de Github.
*********************************************************************/

//----------------------------------------------  INCLUDE SECTION --------------------------------------------
#include <SPI.h>
#include <EEPROM.h>
#include <Wire.h>
#include <avr/pgmspace.h>
#include <Adafruit_GFX.h>
#include <Adafruit_SSD1306.h>
#include <MilliTimer.h>

//----------------------------------------------  MACROS DEFINITION --------------------------------------------
// macros from DateTime.h
#define SECS_PER_MIN (60UL)
#define SECS_PER_HOUR (3600UL)
#define SECS_PER_DAY (SECS_PER_HOUR * 24L)
#define SECS_9H (SECS_PER_HOUR * 9L)

/* Macros for getting elapsed time */
#define numberOfSeconds(_time_) (_time_ % SECS_PER_MIN)
#define numberOfMinutes(_time_) ((_time_ / SECS_PER_MIN) % SECS_PER_MIN)
#define numberOfHours(_time_) ((_time_ % SECS_PER_DAY) / SECS_PER_HOUR)
#define elapsedDays(_time_) (_time_ / SECS_PER_DAY)

//--------------------------------------------------------------------------------------------------------------

// EDCPSU Configuration
#define OLED_DC 16
#define OLED_CS 17
#define OLED_CLK 18
#define OLED_MOSI 19
#define OLED_RESET 7

#define SDA_PIN 4
#define SCL_PIN 5

#define I2C_TIMEOUT 1
#define I2C_NOINTERRUPT 1
#define I2C_SLOWMODE 1
#include <SlowSoftI2CMaster.h>

SlowSoftI2CMaster si = SlowSoftI2CMaster(SDA_PIN, SCL_PIN, false);

Adafruit_SSD1306 display(128, 64, OLED_MOSI, OLED_CLK, OLED_DC, OLED_RESET, OLED_CS);

#define XPOS 0
#define YPOS 1
#define DELTAY 2

//----------------------------------------------  CONST DEFINITION --------------------------------------------

const uint16_t LenDCDCLookupTable = 141; // 2V to 16V
const byte ADDR_I2C_DCDC = 0;
const int DEBOUNCING = 0x55;
const int NO_DEBOUNCING = 0xAA;
const int DEBOUNCE_PUSHB_TIME = 100;   //  milliseconds
const int DEBOUNCE_ROTPUSH_TIME = 200; //  milliseconds
const int DEBOUNCE_ROTARY_TIME = 30;   //  milliseconds
const int DEBOUNCE_PEDAL_TIME = 200;   //  milliseconds
const int DCDC_ENABLED = HIGH;
const int DCDC_DISABLED = LOW;
const int PEDAL_ON = LOW;
const int PEDAL_OFF = HIGH;
const int LED_ON = LOW;
const int LED_OFF = HIGH;
const int PUSHBUTTON_ON = LOW;
const int PUSHBUTTON_OFF = HIGH;
const int FLAG_ON = true;
const int FLAG_OFF = false;
const int NUM_MEMORY = 2;
const int SAVE_MEM_TIMER = 2000;       // Milliseconds
const int EEPROM_RECORDED_DONE = 0xDA; // THis signature indicates if the EEPROM is recorded or if it is brand new and not recorded
const int EEPROM_POLARITY_STATUS = 0x19;

const int EEPROM_HOURS = 0X28; // Position of EEPROM NITRO STATUS  --> INDICATES if NITRO is active or not

const int EEPROM_NITRO_STATUS_CH_1 = 0X20; // Position of EEPROM NITRO STATUS  --> INDICATES if NITRO is active or not
const int EEPROM_NITRO_STATUS_CH_2 = 0X25; // Position of EEPROM NITRO STATUS  --> INDICATES if NITRO is active or not
const int EEPROM_RECORD_STAT = 0x21;       // Position of EEPROM RECORDED FLAG --> INDICATES if EEPROM is recorded (when value = EEPROM_RECORDED_DONE)
const int EEPROM_MNF_YEAR = 0xF0;          // Position of EEPROM MANUFACTURED YEAR (Binary)
const int EEPROM_MNF_MONTH = 0xF1;         // Position of EEPROM MANUFACTURED YEAR (Binary)
const int EEPROM_SERIAL_NO = 0xF2;         // Position of EEPROM MANUFACTURED YEAR (Binary)
const byte NITRO_CFG_NO = 1;               // Nitro Signature configured as NOT (menu selection 1)
const byte NITRO_CFG_YES = 2;              // Nitro Signature configured as YES (menu selection 2)
const int MACHINE_EEPROM_POS0 = 0;         // Position 1 of EEPROM --> Stores the position 0 of Machine 1 memory
const int MACHINE_EEPROM_POS1 = 1;         // Position 1 of EEPROM --> Stores the position 0 of Machine 1 memory
const int MACHINE_EEPROM_POS2 = 2;         // Position 1 of EEPROM --> Stores the position 0 of Machine 1 memory
const int MACHINE_EEPROM_POS3 = 3;         // Position 1 of EEPROM --> Stores the position 0 of Machine 1 memory
const int MACHINE1_OFFSET = 0;             // Offset for both MachinesMemory[] array and EEPROM corresponding to MACHINE_1 WorkingPoint Memories
const int MACHINE2_OFFSET = 4;             // Offset for both MachinesMemory[] array and EEPROM corresponding to MACHINE_2 WorkingPoint Memories
const int MACHINE3_OFFSET = 8;             // Offset for both MachinesMemory[] array and EEPROM corresponding to MACHINE_3 WorkingPoint Memories
const byte NITRO_SETUP_OFF = 0;            // If Nitro setup is taking place
const byte NITRO_SETUP_ON = 0xAA;          // If No Nitro setup is taking place
const byte BEEP_IS_TRUE = true;
const byte BEEP_IS_FALSE = false;
const byte WRITE_MESSG = 1;
const byte DELETE_MESSG = 2;
const byte INFO_MESSG = 1;
const byte WARNING_MESSG = 2;
const byte VIP_MESSG = 3;
const byte NITRO_MESSG = 4;
const byte RUNMODE_NORMAL = 0;
const byte RUNMODE_CONFIG_TOP = 1;
const byte RUNMODE_CONFIG_NITRO = 2;
const byte RUNMODE_MENU_TIMER = 3;
const byte RUNMODE_CHANGE_POL = 4;
const byte LEN_VOUT_BUFFER = 4; // Lenght of VoutBuffer
const byte OVC_SCAN_INPROGRESS = 1;
const int LOW_PITCH = 500;                  // Microseconds between buzzer pulses
const int HIGH_PITCH = 200;                 // Microseconds between buzzer pulses
const int OVC_RECOVERY_TIME = 1500;         // Milliseconds
const unsigned long STANDBY_TIME = 3600000; // 1h
const int POL_NORMAL = 0;                   // Normal polarity = Relay resting/not-energized
const int POL_REVERSE = 1;                  // Revere polarity = Relay energized
const int MAX_THRESHOLD_NITRO = 95;         // Corresponds to EncoderPosition for 11.5V
const int HIGH_THRESHOLD_NITRO = 50;        // Corresponds to EncoderPosition for 7V
const int PUSHBUTTON_IDLE = 0;
const int PUSHBUTTON_ON_EDGE = 1;
const int PUSHBUTTON_FALL = 2;
const int PUSHBUTTON_LONGPRESS = 3;
const unsigned long LONG_PRESS_TIME = 300;   // Milliseconds
const unsigned long OVC_ALARM_TIMER = 2000;  // Milliseconds
const unsigned long MEM_DISPLAY_TIME = 2000; // Milliseconds
const int LenNITROLookupTable = 11;

const int OVC_SENSE_MAX_TIME = 2000; // Maximum time that can last the overcurrent with SENSE method (in Milliseconds)
const int OVC_UVOLT_MAX_TIME = 500;  // Maximum time that can last the overcurrent with the UNDERVOLTAGE method (Milliseconds)
const int OVC_UVOLT_MIN_TIME = 200;  // Maximum time that can last the overcurrent with the UNDERVOLTAGE method (Milliseconds)
const int OVC_UVOLT_DELAY = 5;
const int OVC_SHTC_DELAY = 5;
const int OVC_SHTC_MAX_TIME = 50;
const int OVC_SHTC_MIN_TIME = 15;
const unsigned int OVC_SENSE_LIMIT_INF = 554; // Current limit above which it is still considered an overcurrent sense situation 2.6A
const unsigned int OVC_SENSE_LIMIT_SUP = 639; // Current limit above which it is Triggered the overcurrent sense situation 2.7A real (in theory this value should trigger at 3.1A but Rsense is contaminated by a trace track to the amplifier)
const byte MAX_OVC_ERRORS = 5;                // Max number of OVC errors per session in order to request the release of the PEDAL to the user
const int UNDERVOLT_1V5 = 93;                 // Sensed voltage corresponding to 2V for undervoltage sensing
const int UNDERVOLT_1V8 = 104;                // Sensed voltage corresponding to 1.8V for undervoltage sensing
const int SHORTCIRCUIT_UVLO_INF = 100;        // Sensed voltage corresponding to 1.8V for undervoltage sensing
const int SHORTCIRCUIT_UVLO_SUPP = 104;       // Sensed voltage corresponding to 1.8V for undervoltage sensing
const float DISP_TO_VTARGET_CONV = 5.2;       // Conversion factor to get display values into same scale as VoutSense values (1/19.6)*1023 = 52.2 --> to DISP 52/10=5.2
const byte DISPLAY_MEM = 1;
const byte NO_DISPLAY_MEM = 2;
const byte CLEAR_DISPLAY_MEM = 3;

const byte NO_LONGPRESS_INFO = 0;
const byte LONGPRESS_INFO_CONT = 1;
const byte LONGPRESS_INFO_NO_CONT = 2;
const byte LONGPRESS_INFO_TIMER_ON = 3;
const byte LONGPRESS_INFO_TIMER_OFF = 4;
const unsigned long SHOW_LONGPRESS_TIME = 900; // Time that the longpress information is shown on display (Milliseconds)

const int16_t C_TIMER_ARMED = 0; // Identificador de un Timer como armado y contando.
const int16_t C_TIMER_IDLE = 1;  // Identifiador de un Timer esperando a ser iniciado.
const int16_t C_TIMER_DONE = 2;  // Identificador de un Timer que ha finalizado la cuenta

const unsigned long RX_CHAR_TIMEOUT = 10; // (ms) time allowed for an orphan char received via Serial
const byte TLG_RX_BYTES = 3;              // Bytes compounding a Serial telegram of the Test mode

const byte ALARM_FLAG = 0; // Flag to report that OVC_ALARM sensor is activated. This is set in ReportFlags report byte in the Test Mode
const byte PEDAL_FLAG = 1; // Flag to report that PEDAL input is activated. This is set in ReportFlags report byte in the Test Mode
const int CHANNEL_1 = 1;   // Channel 1
const int CHANNEL_2 = 2;   // Channel 2

// ------------------------------------------------- PIN DEFINITION r7,r6 -------------------------------------------
const int DCDC_EN = 2; //
// const int LED_FRONT = 9; // Arduino 7 (pin 11 in ATMEGA368)
// const int LIFE_CHECK = 10;

const int ISEN = A1;
const int VOSEN = A2;
const int PUSHBUTTON_IP = 3; // HIGH = OFF; LOW = ON
const int ROTPUSH_IP = 6;    // HIGH = OFF; LOW = ON
const int ROTA = 24;
// const int ROTA = 20; // Pico
const int OVC_ALARM = 9; // New in r8.0 (before pin 2)
const int ROTB = 12;
const int BUZZ = 21;
const int PEDAL_IP = 8;     // New in r8.0 (before pin 5)
const int VBUS_SENSE = A0;  // New in r8.0 (before LED)
const int CHANNEL_SEL = 25; // Previous HW version this pin was CHG_POL
// const int CHANNEL_SEL = 22; // Pico
//  const int ENA_OUT = 1;       // TXo-- caution! this digital line overlaps with TXo, so Serial has to be disabled
//-------------------------- ERROR DEFINITION -----------------------------------------------------------------
const int ERROR_10 = 10;
const int ERROR_11 = 11;
const int ERROR_20 = 20;
const int ERROR_21 = 21;
const int ERROR_22 = 22;
const int ERROR_30 = 30;
const int ERROR_31 = 31;

//-------------------------- PROGMEM DEFINITION -----------------------------------------------------------------

const static unsigned char __attribute__((progmem)) MusotokuLogo[] = { // NEW LOGO
    0x03, 0xff, 0xff, 0xff, 0xff, 0xff, 0xff, 0xff, 0x00,
    0x06, 0x00, 0x00, 0x00, 0x00, 0x00, 0x00, 0x01, 0x80,
    0x0c, 0x00, 0x00, 0x00, 0x00, 0x00, 0x00, 0x00, 0xc0,
    0x18, 0x00, 0x00, 0x00, 0x00, 0x00, 0x00, 0x00, 0x60,
    0x30, 0x00, 0x00, 0x00, 0x00, 0x00, 0x00, 0x00, 0x30,
    0x60, 0x00, 0x00, 0x00, 0x00, 0x00, 0x00, 0x00, 0x18,
    0xc0, 0x00, 0x00, 0x00, 0x00, 0x00, 0x00, 0x00, 0x0c,
    0x80, 0x00, 0x00, 0x00, 0x00, 0x00, 0x00, 0x00, 0x04,
    0x80, 0x00, 0x00, 0x00, 0x00, 0x00, 0x00, 0x00, 0x04,
    0x80, 0x00, 0x00, 0x00, 0x00, 0x00, 0x00, 0x00, 0x04,
    0x80, 0x00, 0x41, 0x10, 0x83, 0xc1, 0xe0, 0x00, 0x04,
    0x80, 0x00, 0x63, 0x10, 0x84, 0x22, 0x10, 0x00, 0x04,
    0x80, 0x00, 0x77, 0x10, 0x88, 0x12, 0x10, 0x00, 0x04,
    0x80, 0x00, 0x5d, 0x10, 0x84, 0x02, 0x10, 0x00, 0x04,
    0x80, 0x00, 0x49, 0x10, 0x83, 0xc2, 0x10, 0x00, 0x04,
    0x80, 0x00, 0x41, 0x10, 0x80, 0x22, 0x10, 0x00, 0x04,
    0x80, 0x00, 0x41, 0x10, 0x80, 0x12, 0x10, 0x00, 0x04,
    0x80, 0x00, 0x41, 0x10, 0x88, 0x12, 0x10, 0x00, 0x04,
    0x80, 0x00, 0x41, 0x10, 0x84, 0x22, 0x10, 0x00, 0x04,
    0x80, 0x00, 0x41, 0x0f, 0x03, 0xc1, 0xa0, 0x00, 0x04,
    0xe0, 0x00, 0x00, 0x00, 0x00, 0x00, 0x00, 0x00, 0x1c,
    0x20, 0x00, 0x00, 0x00, 0x00, 0x00, 0x00, 0x00, 0x10,
    0x20, 0x00, 0x00, 0x00, 0x00, 0x00, 0x00, 0x00, 0x10,
    0x20, 0x00, 0x00, 0x00, 0x00, 0x00, 0x00, 0x00, 0x10,
    0x20, 0x00, 0x00, 0x00, 0x00, 0x00, 0x00, 0x00, 0x10,
    0x20, 0x00, 0x00, 0x00, 0x00, 0x00, 0x00, 0x00, 0x10,
    0x20, 0x00, 0x00, 0x00, 0x00, 0x00, 0x00, 0x00, 0x10,
    0xe0, 0x00, 0x00, 0x00, 0x00, 0x00, 0x00, 0x00, 0x1c,
    0x80, 0x00, 0x7f, 0x0f, 0x04, 0x22, 0x10, 0x00, 0x04,
    0x80, 0x00, 0x08, 0x10, 0x84, 0x42, 0x10, 0x00, 0x04,
    0x80, 0x00, 0x08, 0x10, 0x84, 0x82, 0x10, 0x00, 0x04,
    0x80, 0x00, 0x08, 0x10, 0x85, 0x02, 0x10, 0x00, 0x04,
    0x80, 0x00, 0x08, 0x10, 0x86, 0x02, 0x10, 0x00, 0x04,
    0x80, 0x00, 0x08, 0x10, 0x86, 0x02, 0x10, 0x00, 0x04,
    0x80, 0x00, 0x08, 0x10, 0x85, 0x02, 0x10, 0x00, 0x04,
    0x80, 0x00, 0x08, 0x10, 0x84, 0x82, 0x10, 0x00, 0x04,
    0x80, 0x00, 0x08, 0x10, 0x84, 0x42, 0x10, 0x00, 0x04,
    0x80, 0x00, 0x08, 0x0f, 0x04, 0x21, 0xe0, 0x00, 0x04,
    0x80, 0x00, 0x00, 0x00, 0x00, 0x00, 0x00, 0x00, 0x04,
    0x80, 0x00, 0x00, 0x00, 0x00, 0x00, 0x00, 0x00, 0x04,
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

};
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
void loop()
{
  Time = millis();

  if (RunMode == RUNMODE_NORMAL) // Only display if NOT in any configuration menu
  {

    if (RuntimerEnable == true) // PLAY
    {
      if ((Time - PartialRuntimer) > 10000)
      {
        TotalRuntimer = TotalRuntimer + (Time - PartialRuntimer);
        PartialRuntimer = Time; // Reset the partial count
        RunTimer(TotalRuntimer, &runningHours, &runningMinutes);
        DisplayTimer(runningHours, runningMinutes);
      }
    }
    else if ((Time - PartialRuntimer) > 1000) // RuntimerEnable == STOP -->> Blinks the timer
    {
      PartialRuntimer = Time; // Reset the partial count

      if (toggleTimer == true)
      {
        toggleTimer = false;
        DisplayTimer(runningHours, runningMinutes);
      }
      else
      {
        toggleTimer = true;
        display.fillRect(95, 57, (128 - 95 - 1), 7, BLACK); // Clears the print area before the text (x0,y0,w,h,color)
        display.display();
      }
    } // RuntimerEnable == STOP
  } // RunMode == RUNMODE_NORMAL

  Standby_Handler(&StandbyGlobalTimer); // Checks if go to STANDBY
  if ((Time - HourTimer) > 1000)
  {
    mins++;
    if (mins == 60)
    {
      hours++;
      mins = 0;
      HourTimer = Time;
      EEPROM[EEPROM_HOURS] = hours;
      EEPROM.commit();
    }
  }

  //----- DCDC ADJUSTMENT TO ENCODER POSITION -----
  // This section of code does not execute while on MENU CONFIGURATION mode

  if (updateDisplayVoltsFLAG == FLAG_ON)
  {
    updateDisplayVoltsFLAG = FLAG_OFF;

    TPICvalue = pgm_read_byte_near(TPICLookupTable + encoderPos);

    Write_TPIC2810(ADDR_I2C_DCDC, TPICvalue);
    // Serial.println(TPICvalue);

    DisplayValue = pgm_read_byte_near(DisplayValues + encoderPos);
    VoutTarget = int(DisplayValue * DISP_TO_VTARGET_CONV);

    ShowDisplayValue(DisplayValue);
    /*if (showMem == DISPLAY_MEM)
    {
      showMem = CLEAR_DISPLAY_MEM;
      DisplayMem(MachineMemPos);    // Dual model must not display the memory memory because there are only
                                       two memories that are associated to each channel.
    }
    */
    if ((NitroStartGradeCh1 != NITRO_CFG_NO) && (ActualChannel == CHANNEL_1)) // Confirm that NITRO in Channel 1 is ON
    {
      DisplayMessage(RunMode, WRITE_MESSG, "NITRO", NITRO_MESSG, DisplayValue);
    }
    else if ((NitroStartGradeCh2 != NITRO_CFG_NO) && (ActualChannel == CHANNEL_2)) // Confirm that NITRO in Channel 2 is ON
    {
      DisplayMessage(RunMode, WRITE_MESSG, "NITRO", NITRO_MESSG, DisplayValue);
    }
    DisplayTimer(runningHours, runningMinutes);
  }
  //----------------- UPDATE MEMORY ---------------------------
  if (RotaryChangedFlag == FLAG_ON)
  {
    if ((Time - SaveMemoryTimer) >= SAVE_MEM_TIMER)
    {
      MachinesMemory[(MachineOffset + MachineMemPos)] = encoderPos;
      EEPROMaux = MachineMemPos + MACHINE1_OFFSET;
      EEPROM[EEPROMaux] = (byte)encoderPos;
      EEPROM.commit();
      RotaryChangedFlag = FLAG_OFF;
      DisplayMessage(RunMode, WRITE_MESSG, "REC", INFO_MESSG, DisplayValue);
      delay(300);
      DisplayMessage(RunMode, DELETE_MESSG, "REC", INFO_MESSG, DisplayValue);
    }
  }
  /*
  //------------------ CLEAR THE MEMORY INFORMATION ON DISPLAY --------------
  if (showMem == CLEAR_DISPLAY_MEM)
  {
    if ((Time - Show_Mem_Timer) > MEM_DISPLAY_TIME)
    {
      showMem = NO_DISPLAY_MEM;
      display.fillRect(0, 51, 37, 13, BLACK);
      display.display();
    }
  }
*/

  //---------------- SPECIAL INFO ON DISPLAY (LONGPRESS ACTIONS) ---------

  if (ShowLongpressInfo != NO_LONGPRESS_INFO)
  {
    updateDisplayVoltsFLAG = FLAG_OFF;
    display.clearDisplay(); // clears the screen and buffer
    display.setTextSize(3);
    display.setTextColor(WHITE);
    display.drawRoundRect(0, 0, 128, 64, 10, WHITE);

    if (ShowLongpressInfo == LONGPRESS_INFO_CONT)
    {
      display.setCursor(33, 8);
      display.print("CONT");
      display.setCursor(43, 35);
      display.print("ON");
    }
    else if (ShowLongpressInfo == LONGPRESS_INFO_NO_CONT)
    {
      display.setCursor(33, 8);
      display.print("CONT");
      display.setCursor(36, 35);
      display.print("OFF");
    }
    else if (ShowLongpressInfo == LONGPRESS_INFO_TIMER_ON)
    {
      display.setCursor(26, 5);
      display.print("START");
      // THE TIMER
      char arr_HHMM[8] = "01:44";
      sprintf(arr_HHMM, "%01d:%02d", runningHours, runningMinutes);
      display.setCursor(28, 35);
      display.print(arr_HHMM);
    }
    else if (ShowLongpressInfo == LONGPRESS_INFO_TIMER_OFF)
    {
      display.setCursor(28, 5);
      display.print("STOP");
      // THE TIMER
      char arr_HHMM[8] = "01:44";
      sprintf(arr_HHMM, "%01d:%02d", runningHours, runningMinutes);
      display.setTextSize(3);
      display.setTextColor(WHITE);
      display.setCursor(25, 35);
      display.print(arr_HHMM);
    }

    display.display();

    if ((Time - ShowLongPressTimer) > SHOW_LONGPRESS_TIME)
    {
      ShowLongpressInfo = NO_LONGPRESS_INFO;
      // Serial.println("timer");
      updateDisplayVoltsFLAG = FLAG_ON; // To refresh the display with the output value
    }
  }
  else // NO_LONGPRESS_INFO
  {
    ShowLongPressTimer = Time;
  }

  //---------------- PUSHBUTTON ACTION EXECUTION ----------------------
  if ((PushbuttonAction == PUSHBUTTON_FALL) && (ShowLongpressInfo == NO_LONGPRESS_INFO)) // No  pushbutton available while longpress info is shown
  {
    PushbuttonAction = PUSHBUTTON_IDLE;

    if (BlankingPushB_action == false) // To avoid change memory after entering in continuous mode
    {
      RotaryChangedFlag = FLAG_OFF; // RESET the rotary change action to avoid memory update after the button is pressed

      StandbyGlobalTimer = Time; // Reset the standby timer

      if ((OutLatchState == false) && (PedalNow == PEDAL_OFF)) // Only change MEMORY SETUP if Output is OFF
      {
        MachineMemPos = (MachineMemPos + 1) % NUM_MEMORY;
        if (MachineMemPos == 0)
        {
          // MEMORY = 0 --> MACHINE OUTPUT 1
          digitalWrite(CHANNEL_SEL, LOW);
          ActualChannel = CHANNEL_1;
        }
        else
        {
          // MEMORY = 1 --> MACHINE OUTPUT 2
          digitalWrite(CHANNEL_SEL, HIGH);
          ActualChannel = CHANNEL_2;
        }
        encoderPos = MachinesMemory[(MachineOffset + MachineMemPos)];
        updateDisplayVoltsFLAG = FLAG_ON;
        showMem = DISPLAY_MEM; // For displaying the memory info
        Show_Mem_Timer = Time; // Ready the timer for display the mem number
      }
      else
      {
        BuzzerClick(LOW_PITCH, 210);
        // do nothing
        // While the output is ON (OUTLATCHSTATE = TRUE) it won't
        // change the memory
      }
    }
    else
    {
      BlankingPushB_action = false;
    }
  }

  if (PushbuttonAction == PUSHBUTTON_LONGPRESS)
  {
    BlankingPushB_action = true; // This is to avoid change in memory value after the Longpress

    if (PUSHB_Longpress_1st_Action == true)
    {
      PUSHB_Longpress_1st_Action = false; // This avoids continuous entering in PushbuttonAction, which would result in toggling the continuous mode

      BuzzerClick(HIGH_PITCH, 55);
      delay(15);
      BuzzerClick(HIGH_PITCH, 55);

      if (continuousMode == true) // Continuous Mode with toggle function in order to completely avoid the pedal if needed
      {
        continuousMode = false;
        OutLatchState = false;
        ShowLongpressInfo = LONGPRESS_INFO_NO_CONT;
      }
      else
      {
        continuousMode = true;
        OutLatchState = true; // output is latched by default to ON state
        ShowLongpressInfo = LONGPRESS_INFO_CONT;
        NitroForContinuousMode = true; // This is to enable the Nitro action during the "RISE event" of continuou mode
      }
    }
  }
  else
  {
    PUSHB_Longpress_1st_Action = true; // Reset the variable. Now is ready for the next cycle.
  }

  //--------------- ROTPUSH ACTION EXECUTION ------------------
  if (RotPushEvent == PUSHBUTTON_FALL) // Important while in longpress action FALL event should not be attended
  {
    RotPushEvent = PUSHBUTTON_IDLE;

    if (ShowLongpressInfo == NO_LONGPRESS_INFO)
    {
      StandbyGlobalTimer = Time; // Reset the standby timer
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

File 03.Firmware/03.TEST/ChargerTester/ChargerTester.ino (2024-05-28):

/**
 * @file ChargerTester.ino
 * @author Javi (Javier@musotoku.com)
 * @brief
 * @version 0.1
 * @date 2023-05-17
 *
 * @copyright Copyright (c) 2023
 *
 */

#include <Adafruit_SSD1306.h>
#define OLED_DC 16
#define OLED_CS 17
#define OLED_CLK 18
#define OLED_MOSI 19
#define OLED_RESET 7

Adafruit_SSD1306 display(128, 64, OLED_MOSI, OLED_CLK, OLED_DC, OLED_RESET, OLED_CS);

const uint16_t C_PIN_CHARGER_1 = 15;
const uint16_t C_PIN_CHARGER_2 = 14;
const uint16_t C_PIN_CHARGER_3 = 13;
const uint16_t C_PIN_CHARGER_4 = 12;
const uint16_t C_PIN_CHARGER_5 = 11;
const uint16_t C_PIN_CHARGER_6 = 10;
const uint16_t C_PIN_CHARGER_7 = 9;
const uint16_t C_PIN_CHARGER_8 = 8;

const int num_signals = 2;      // número de señales
const int on_time = 5000;       // tiempo en milisegundos en el que las señales están en nivel alto
const int off_time = 5000;      // tiempo en milisegundos en el que las señales están en nivel bajo
const int signal_spacing = 400; // tiempo en milisegundos entre cada señal

uint16_t cursor_x = 0;
uint16_t cursor_y = 0;

bool flag_1 = false;
bool flag_2 = false;
bool flag_3 = false;
bool flag_4 = false;
bool flag_5 = false;
bool flag_6 = false;
bool flag_7 = false;
bool flag_8 = false;

void setup()
{
    display.begin(SSD1306_SWITCHCAPVCC);
    display.clearDisplay();
    display.setTextSize(2);
    display.setTextColor(WHITE);
    display.setCursor(45, 0);
    display.print("INIT");
    display.setCursor(45, 26);
    display.print("TEST");
    display.display();
    // Inicializar los pines como salidas

    pinMode(3, OUTPUT);
    pinMode(4, OUTPUT);

    pinMode(C_PIN_CHARGER_1, INPUT);
    pinMode(C_PIN_CHARGER_2, INPUT);
    pinMode(C_PIN_CHARGER_3, INPUT);
    pinMode(C_PIN_CHARGER_4, INPUT);
    pinMode(C_PIN_CHARGER_5, INPUT);
    pinMode(C_PIN_CHARGER_6, INPUT);
    pinMode(C_PIN_CHARGER_7, INPUT);
    pinMode(C_PIN_CHARGER_8, INPUT);

    digitalWrite(3, HIGH);
    digitalWrite(4, HIGH);

    delay(10000);
    digitalWrite(3, LOW);
    digitalWrite(4, LOW);

    cursor_x = 0;
    cursor_y = 26;
    display.clearDisplay();
    display.setCursor(0, 0);
    display.print("FAILS:");
    display.display();

    for (int i = 0; i < 200; i++)
    {
        // Poner todas las señales a nivel alto
        digitalWrite(3, HIGH);
        digitalWrite(4, HIGH);
        delay(1000);

        if ((digitalRead(C_PIN_CHARGER_1) == HIGH) && (flag_1 == false))
        {
            display.setCursor(cursor_x, cursor_y);
            display.print("1");
            cursor_x += 16;
            flag_1 = true;
        }
        if ((digitalRead(C_PIN_CHARGER_2) == HIGH) && (flag_2 == false))
        {
            display.setCursor(cursor_x, cursor_y);
            display.print("2");
            cursor_x += 16;
            flag_2 = true;
        }
        if ((digitalRead(C_PIN_CHARGER_3) == HIGH) && (flag_3 == false))
        {
            display.setCursor(cursor_x, cursor_y);
            display.print("3");
            cursor_x += 16;
            flag_3 = true;
        }
        if ((digitalRead(C_PIN_CHARGER_4) == HIGH) && (flag_4 == false))
        {
            display.setCursor(cursor_x, cursor_y);
            display.print("4");
            cursor_x += 16;
            flag_4 = true;
        }
        if ((digitalRead(C_PIN_CHARGER_5) == HIGH) && (flag_5 == false))
        {
            display.setCursor(cursor_x, cursor_y);
            display.print("5");
            cursor_x += 16;
            flag_5 = true;
        }
        if ((digitalRead(C_PIN_CHARGER_6) == HIGH) && (flag_6 == false))
        {
            display.setCursor(cursor_x, cursor_y);
            display.print("6");
            cursor_x += 16;
            flag_6 = true;
        }
        if ((digitalRead(C_PIN_CHARGER_7) == HIGH) && (flag_7 == false))
        {
            display.setCursor(cursor_x, cursor_y);
            display.print("7");
            cursor_x += 16;
            flag_7 = true;
        }
        if ((digitalRead(C_PIN_CHARGER_8) == HIGH) && (flag_8 == false))
        {
            display.setCursor(cursor_x, cursor_y);
            display.print("8");
            cursor_x += 16;
            flag_8 = true;
        }
        display.display();

        // Esperar el tiempo especificado
        delay(on_time);

        // Poner todas las señales a nivel bajo
        digitalWrite(3, LOW);
        digitalWrite(4, LOW);

        // Esperar el tiempo especificado
        delay(off_time);
    }
    digitalWrite(3, HIGH);
    digitalWrite(4, HIGH);
}

void loop()
{
}

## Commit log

2022-05-23 WIP EDCPSU r1 (Ready To Revision)
    [EDCPSUMK2.brd, EDCPSUMK2.sch]
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2022-05-23 Revision de version definitva Javi
    [EDCPSUMK2.brd, EDCPSUMK2.sch]
2022-05-23 Update Note 22-RTR (Ready To Revision)
    Add Resistor N.A for Divisor
    Connect USb Shield to GND
    Fix silkcreen and Position
    Fix IN_OVC to MCPU
    Plane for VOUT and GND in Flex Connection
    Fix Test Pint Positions
    [EDCPSUMK2.brd, EDCPSUMK2.sch]
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2022-05-23 Añadido SPARE2 + revisión
    Se añade SPARE2 con R y Pad para tener un punto de acceso al pin 13 de CPU.
    Pequeños cambios en revisión
    [EDCPSUMK2.brd, EDCPSUMK2.sch]
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2022-05-25 Update EDCPSUMK2.brd
    Solucion a la estrangulacion del plano de Vcc(19v) en la capa PWR en la parte superiror izquierda.
    [EDCPSUMK2.brd]
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2022-05-26 Update PCB ECPSUMK2
    Actualizacion y mejora de las capas de PWR y GND
    [EDCPSUMK2.brd, EDCPSUMK2.sch]
2022-05-26 Se actualiza Titulo (cajetin) a MK2 r1 mayo 22
    [EDCPSUMK2.sch]
2022-05-27 Delete MK2_BOM.xlsx
    Se mueve de sitio y cambia de nombre
    [MK2_BOM.xlsx]
2022-05-27 Migrado desde el documento DOC de Javi
    [Resumen Cambios en BOM (MK2).xlsx]
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2022-05-27 Convertido de documento WORD de Javi
    [Resumen Cambios en BOM (MK2).xlsx]
2022-05-27 Varios cambios
    Se separa de la tarjeta de conectores
    Se añade indicación en el histórico de procedencia
    Se corrige alguna linea que sí monta SETI
    [EDCPSU_MK2_BOM.xlsx]
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2022-06-13 Se añade la FAJA de poliester
    [EDCPSUMK2.dxf, FAJA.dxf, FAJAS_EDCPSU_USBC.brd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]
2022-06-15 Flex MK2 Creation
    [FAJAS_EDCPSU_USBC.brd, FAJAS_EDCPSU_USBC.sch]
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2022-06-16 Cleanup trazado + GERBERs
    Versión de primera compra a PCBWAY
    [FAJAS_EDCPSU_USBC.brd]
2022-06-17 Cambio Grosor y Carpetas nuevas
    Se cambia el grosor de las pistas de VOUT y la conexión a las vías de los conectores.
    ----------
    Creación de las carpetas dentro de la
    [Connectors-MK2-1ch.brd, Connectors-MK2-1ch.dxf, Connectors-MK2-1ch.sch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]
2022-08-05 Pruebas mecanicas en EDCPSUr16
    [Conectores M2 v1.brd, Conectores M2 v1.sch, Conectores M2 v2.brd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]
2022-08-05 Placa de prueba de control de overcurrent
    [USBC-OVC_LIMIT.brd, USBC-OVC_LIMIT.dxf, USBC-OVC_LIMIT.sch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]
2022-08-05 Ficheros de referencia version 731 de la Machete MK1
    [Lookup table TPIC.xlsx]
2022-08-05 Documentacion conectores de la MK2 Dual
    [Connectors_MK2_Dual-BOM.xlsx]
2022-08-05 Ficheros Lentilla Led Frontal MK2
    [Drawing 2.dxf, shapr3d_export_2022-05-11_18h31m.dxf, shapr3d_export_2022-05-11m.dxf]
2022-08-05 Creacion BOM Conectores y EDCPSU MK2
    [Connectors_MK2_Dual-BOM.xlsx, EDCPSU_MK2_BOM.xlsx]
2022-08-10 PCB 1channel - CAM output generado
    [Connectors-MK2-1ch.brd]
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2022-08-16 Cierre de Issue #3. Cambios menores
    #3- https://www.notion.so/Arranque-de-la-M2-muestra-el-logo-durante-muy-poco-tiempo-Antes-3s-ahora-1s-f0cdef7c8bc9491a815bdf0ef47de030
    Se cambia la duracion del LongPress de 800 a 900 para prevenir el encendido NO intencionado. (Testing)
    Cambio en la nomnclatura a MK2-DUAL
    [EDCPSU-MK2-DUAL.ino]
2022-08-17 Close Issue #4,#5,#6.
    #4 Se decide cambiar el texto que se muestra. Se vuelva a mostras el encendido y apagado del modo continuo independientemente del canal.
    #5 Se coloca la Palabra NITRO en la esquina inferior izquierda siempre que el nitro se encuentre activado.
    #6 En la activación del pulsador se realiza una comprobación de si el pedal esta activo o no. En caso afirmativo no se permite el cambio de canal.
    [EDCPSU-MK2-DUAL.ino]
2022-08-29 Updata EDCPSU-MK2-DUAL.ino. Independencia por canal del modo Nitro
    Independencia de la activacion Nitro por canal.
    Almacenamiento en EEPROM del estado de cada canal de la Configuracion del Nitro
    Issue #7:
    https://www.notion.so/Activaci-n-independiente-del-Nitro-para-cada-Canal-Almacenamiento-en-EEPROM-2c2c8b672f0b42c3aefab32c016fb566
    [EDCPSU-MK2-DUAL.ino]
2022-08-30 Release Candidate v802. Close Issue #7
    Creacion constantes para los canales mejora Coding Standar.
    [EDCPSU-MK2-DUAL.ino]
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2022-11-24 v804.Cierre del Issue #8. y creacion carpeta con ficheros HEX
    [EDCPSU-MK2-DUAL.ino]
2022-11-30 Cambio dimension Fajas. Cierre Issue #9
    [FAJAS_EDCPSU_USBC.brd, FAJA_LARGA_USBC.dxf]
2022-11-30 Creacion Gerber
    Se corrige la serigrafia a V2.
    [FAJAS_EDCPSU_USBC.brd]
2023-02-03 Creacion y Ajuste de faja para Single output a raiz de la v2 de la faja para dual output.
    [FAJAS_EDCPSU_USBC_single.brd, FAJAS_EDCPSU_USBC_single.sch]
2023-02-03 Revision de la creacion de la nueva faja
    Se cambia DRC a 10mil para todo el diseño
    Se corrigen fallos de clearance
    [FAJAS_EDCPSU_USBC_single.brd]
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2023-03-07 Cierra issuel #2
    referencia de conector nueva: ACJS-MHOM
    [Connectors_MK2_Dual-BOM.xlsx]
2023-03-07 Cierra la issue #3
    [FAJAS_EDCPSU_USBC_single.brd]
2023-03-10 Creacion de carpeta rp2040, documentacion sobre la rasp picp y el rp2040. Archivo de pcb con los primeros cambios.
    [74LVC1G74DP,125.stp, ABLS-12.000MHZ-B4-T.SchLib, ABLS-12.000MHZ-B4-T.stp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]
2023-03-14 Propuesta 1 MK2 2040
    [EDCPSUMK2_2040.brd, EDCPSUMK2_2040.sch]
2023-03-22 Version de comienzo de rediseño
    [EDCPSUMK2_2040.brd, EDCPSUMK2_2040.sch]
2023-03-23 Adapatacion cambios MK2 RP2040
    [EDCPSUMK2-RP2040.brd, EDCPSUMK2-RP2040.sch, EDCPSUMK2_2040.brd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]
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2023-03-24 1º Colocacion de componentes en el brd
    [EDCPSUMK2-RP2040.brd, EDCPSUMK2-RP2040.sch]
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2023-03-27 Continuacion de cambios. Rutado inicial de todos los componentes. Falta asignacion de pines.
    [EDCPSUMK2-RP2040.brd, EDCPSUMK2-RP2040.sch]
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2023-03-28 Propuesta de routeado 1
    [EDCPSUMK2-RP2040.brd, EDCPSUMK2-RP2040.sch]
2023-03-29 Propuesta de routeado 2
    [EDCPSUMK2-RP2040.brd, EDCPSUMK2-RP2040.sch]
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2023-05-02 Version 1 de la pogo test de la MK2-RP2040
    [POGOTEST-MK2RP2040.brd, POGOTEST-MK2RP2040.sch]
2023-05-02 Correcion errores
    [POGOTEST-MK2RP2040.brd]
2023-05-02 PCB que servra de calzador para la pogo pin
    [POGOHOLES-MK2RP2040.brd, POGOHOLES-MK2RP2040.sch]
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2023-05-16 Pedido a PCBWAY (ultimas modificaciones)
    Revision del diseño de Javi
    Se añade landing mas largo para el opto
    [Tester Charger Mk2.brd]
2023-05-16 Revision antes de enviar a SETI
    Se corrigen varios links
    Se crea columna de selección para fabricacion de DUAL USBC o MK1 y asi ajustar la producción
    [EDCPSU_MK2_RP2040_BOM.xlsx]
2023-05-30 Version 2 revisada de la EDCPSU
    Los cambios son referidos a los issues #5, #6, #7, #8, #9, #10, #11, #12.
    [EDCPSUMK2-RP2040.brd, EDCPSUMK2-RP2040.csv, EDCPSUMK2-RP2040.sch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]
2023-05-31 v3 BOM. cambios para seti
    Columna de cambios.
    [EDCPSU_MK2_RP2040_BOM-SETI.xlsx]
2023-05-31 Actualizacion de Cambios menores
    R15 con valor 0R.
    Lineas de Ref de tension a 3V_REF y R57 ajustada a 330R #10
    Aumento de la linea de potencia de GND en la zona de la faja.
    Mejora del marcaje de la colocacion de los Diodos.
    [EDCPSUMK2-RP2040.brd, EDCPSUMK2-RP2040.sch]
2023-05-31 Update EDCPSUMK2-RP2040
    Cambio del Zener del 3,6v a 3,9v. #13
    [EDCPSUMK2-RP2040.brd, EDCPSUMK2-RP2040.sch]
2023-06-01 Update EDCPSUMK2-RP2040 - Diodo entrada D1
    Cambio del diodo D1 de bidireccional a Unidireccional de 24v. #14
    [EDCPSUMK2-RP2040.brd, EDCPSUMK2-RP2040.sch]
2023-06-01 Produccion SETI - Modificaciones menores y generacion de GERBER para fabricacion
    [EDCPSUMK2-RP2040.brd, EDCPSU_MK2_RP2040_BOM-SETI.xlsx]
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2023-06-14 Fallo en el I2C. #Issue 15
    [EDCPSUMK2-RP2040.brd, EDCPSUMK2-RP2040.sch]
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2023-09-08 Tarjeta de Testeo MK2040 v1
    Pendiente de Revision
    [tester rp2040.brd, tester rp2040.sch]
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2023-09-08 Fix fecha de creacion
    [EDCPSU-MK2-DUAL-RP2040.ino]
2023-09-11 Fix errors.
    Cooper clereance 6mil ->8mil.
    Isolate de los planos a 0,254 mils.
    DRC aproved
    [tester rp2040.brd]
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2023-10-11 Issue #18
    Version 1 de la propuesta de cambio
    [EDCPSUMK2-RP2040.brd, EDCPSUMK2-RP2040.dxf, EDCPSUMK2-RP2040.sch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]
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2023-10-30 Correccion Errores
    Señal Vcc sin conectar.
    Añadido sensado de señales VBUS_SENSE y OVC_ALARM.
    Mejorado el Plano de GND para evitar estrangulamientos.
    Ensanchadas las pistas que conectan con vias.
    [tester rp2040.brd, tester rp2040.sch]
2023-11-22 Cambio de R7
    El valor se cambia para tener en cuenta la R1 presente en la tarjeta cuando la señal OVC_ALARM es activada y prevenir la raspi de una subida de tension en la entrada digital.
    [EDCPSUMK2-RP2040.csv, tester rp2040.brd, tester rp2040.csv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]
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2024-02-05 Correccion de la version en pagina principal. No hay cambios de valores
    [EDCPSU_MK2_RP2040_BOM-SETI.xlsx]
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

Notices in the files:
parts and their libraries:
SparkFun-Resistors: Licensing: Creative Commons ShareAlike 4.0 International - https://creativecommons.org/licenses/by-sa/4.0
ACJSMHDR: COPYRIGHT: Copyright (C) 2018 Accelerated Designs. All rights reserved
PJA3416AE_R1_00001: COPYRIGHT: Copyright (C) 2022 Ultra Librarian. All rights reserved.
